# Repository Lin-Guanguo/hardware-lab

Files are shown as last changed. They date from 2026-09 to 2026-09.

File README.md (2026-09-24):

# Hardware Lab

用于个人硬件实验和小装置开发的 Git 仓库。每个装置放在 `projects/` 下，独立维护固件、硬件资料、依赖和构建流程。

## 当前确定方案

以下为各项目当前采用的方向；点击项目名查看最新文件和验证边界，历史方案保留在各项目后续章节。

| 项目 | 用途 | 最近记录的状态 |
| --- | --- | --- |
| [AI Passport](projects/ai-passport/README.md) | 探索紧凑的可编程胸牌、屏幕按键交互与 NFC 链接 | 2026-09-16 确认已下单，等待到货 |
| [Image Oracle](projects/image-oracle/README.md) | 用固定算法将摄像头图像映射为答案，默认拍摄熔岩灯 | 2026-09-19 拼接原型完成并验收；后续探索更多传感器，或焊接、定制 PCB 与 3D 打印的紧凑装置 |
| [Programmable NFC Business Card](projects/nfc-business-card/README.md) | 按键切换身份的薄型 NFC 墨水屏名片 | 2026-09-24 R1 routed in a clean native project: saved/reopened DRC 0, 5.8 mm clear case. Checkpoint `bee8846` saved. Subsequent review removes all nominal 0.2 mm drills, adds USB ground stitching and corrects the C1/C8 review assignment; CE/SCL routing removes two vias and R3/R4 are corrected to 0 ohm. [SWD programmer recovery is selected](projects/nfc-business-card/hardware/r1-usb-swd-recovery.md), with no hidden RESET added. Vendor DFM and real-board tests remain open. [Delivery and checks](projects/nfc-business-card/hardware/pcb-r1-delivery.md). RF and physical fit remain untested. |

## 目录结构

```text
hardware-lab/
├── README.md
├── AGENTS.md
├── .gitignore
├── .gitmodules
├── .agents/
│   └── skills/
│       ├── easyeda-api -> ../../upstreams/easyeda-api-skill   <- 外部 Skill（符号链接）
│       └── pcb-methodology/                                   <- 本仓库自建的方法论总控
├── upstreams/
│   ├── easyeda-api-skill/       <- 嘉立创 EDA 官方 API Skill（可调用）
│   ├── kicad-happy/             <- EMC 规则、公式与监管限值（只读参考）
│   ├── pcb-skill/               <- 同工具链的流程纪律与 MCP 陷阱（只读参考）
│   ├── pcba-design-skills/      <- 证据门禁与产物失效模型（只读参考）
│   └── hw-review/               <- 逐引脚证据式审查、嘉立创 EDA 解析（只读参考）
├── eda/
│   ├── README.md
│   ├── NFC-Card-R1.eprj2
│   └── archive/              <- Historical native projects
├── docs/
│   ├── environment.md      <- 工具链、常驻服务、五分钟自检（新接手先看）
│   ├── pcb-design-rules.md <- DRC 看不见的规则：阈值、一手来源与本板适用性
│   ├── inventory.md
│   └── wiring-diagrams.md
└── projects/
    ├── ai-passport/
    │   └── README.md
    ├── image-oracle/
    │   ├── README.md
    │   ├── firmware/
    │   ├── hardware/
    │   ├── scripts/
    │   ├── wiring-diagrams/
    │   └── docs/
    └── nfc-business-card/
        ├── README.md
        ├── hardware/         <- production/r1/ 制造文件；records/ 校验证据
        ├── enclosure/        <- 模型、STEP/STL、报告；renders/ 是渲染图册
        ├── scripts/          <- 导出器、检查器、布线/线圈规划工具
        ├── docs/             <- 含 progress.md 进度看板
        ├── archive/          <- 历史方案与旧索引
        └── artifacts/        <- 本机产物（全部忽略，只有 README.md 索引入库）
```

目录用途与命名约定见 [AGENTS.md](AGENTS.md)；本机环境、常驻服务与自检见 [环境与常驻服务](docs/environment.md)。所有目录均在首次有实际内容时创建；新项目可以只有 README，不使用占位文件预建目录。根目录 `docs/` 保存跨项目信息，包括器件清单和[接线图制作与归档方法](docs/wiring-diagrams.md)。

根目录 [eda/](eda/README.md) 直接保存嘉立创 EDA 的原始 `.eprj2` 工程，不使用工程文件符号链接；历史工程移到 `eda/archive/`。客户端只需登记一次 `hardware-lab/eda/`。正式工程纳入 Git，所属项目通过文档关联；BOM 等资料仍保存在项目的 `hardware/`，临时导出产物放在 `artifacts/`。

现有接线图见 [Image Oracle 图册](projects/image-oracle/wiring-diagrams/README.md)。后续默认使用带主板外形、完整丝印和模块排针数字序号的接线图；各项目使用相同目录名。

## 设计方法论

DRC 只证明几何没撞上，不证明设计正确。仓库级 [PCB 设计规则索引](docs/pcb-design-rules.md) 列出 DRC 看不见的规则、阈值、一手来源，以及每条规则对 2 层薄板的适用性；流程、约束层级与电气敏感件门禁见自建 skill [pcb-methodology](.agents/skills/pcb-methodology/SKILL.md)。

外部方法论仓库以 Git submodule 引入 `upstreams/`，按需跟随主线。分两类：可直接调用的 Skill 用符号链接进 `.agents/skills/`；只作参考的上游不加链接、不执行其脚本，由自建总控 skill 引用。上游的规则原文不复制进本仓库，引用时标注仓库、文件与规则编号。

## 开始工作

0. 新机器/新接手先看[环境与常驻服务](docs/environment.md)：工具链路径、EDA 桥接（launchd）从零重建、五分钟自检清单与常见故障。
1. 阅读 [AGENTS.md](AGENTS.md) 和目标项目的 README。
2. 分配引脚和确定供电前，先核对实物及对应资料。
3. 改布局、布线、板框或器件位号前，先看 [PCB 设计规则索引](docs/pcb-design-rules.md)，并按敏感件门禁判断要动的器件属于哪一类。
4. 将固件放入项目的 `firmware/`，在项目 README 记录具体工具链、依赖版本和已验证的 shell 命令。
5. 先复现已知可用的例程，再修改应用功能。
6. 记录完成了哪些构建、哪些实机测试，以及仍未确认的事项。

各项目在自己的 README 记录已验证的构建、烧录与测试命令；在本地 Mac 上使用编辑器、shell 工具和 AI 辅助开发。

克隆后使用 `git submodule update --init --recursive` 初始化 `upstreams/` 下的外部仓库。外部 Skill 通过 `.agents/skills/` 中的相对符号链接供 Codex 发现；EDA Skill 的本地依赖与启动方式见 [软件说明](projects/nfc-business-card/docs/software.md)。

## 仓库约定

- 按装置或用途组织项目，每个项目可使用不同的 MCU 和工具链版本。
- 详细状态和下一步放在项目 README，根目录项目表仅作简要导航。
- Git 保存源码、实用的小型素材、可编辑 CAD、依赖锁文件和可复现配置。临时固件导出、采集数据和测量输出放入被忽略的 `artifacts/` 或 `logs/` 目录。
- ESP-IDF 的有意配置保存在 `sdkconfig.defaults` 及所需变体中；生成的 `sdkconfig` 和构建产物不入库。
- 外部上游仓库统一用 Git submodule 放在 `upstreams/`，固定提交并保留上游许可证，在项目文档记录 URL、revision 和使用方式。直接导入的例程仍需记录来源，避免把其嵌套 `.git` 目录复制进仓库。
- 文档默认使用中文；代码、代码注释和专有名词保持英文，具体见 [AGENTS.md](AGENTS.md) 的语言约定。

历史讨论和采购决策继续保存在 [CyberMnema](../CyberMnema/README.md)，通过链接关联。本仓库记录实际工程进展。

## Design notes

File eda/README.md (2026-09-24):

# Native EDA projects

## 当前确定方案

Open [NFC-Card-R1.eprj2](NFC-Card-R1.eprj2) for the NFC card. It contains one PCB and one four-page schematic. [Current files, status and checks](../projects/nfc-business-card/README.md).

Historical projects and database checkpoints are preserved in [archive/nfc-business-card](archive/nfc-business-card/). The E14-named project contains later E-series experiments; its filename does not identify the final R1 source.

Save and close the EDA application before moving or committing `.eprj2` databases. SQLite journals and local automatic backups are ignored. Active projects live directly in this directory; superseded sources live in `archive/`.

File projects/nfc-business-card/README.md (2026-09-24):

# Programmable NFC Business Card

## 当前确定方案

**3.0 mm 内腔研究：**按用户反馈电池最厚处可卡入 3 mm，已完成 [4.6 mm 总厚诊断](enclosure/r1-cavity-3mm-study/README.md)。现有 USB、主控、FPC 座和按键运动存在干涉；局部深腔与平整外表两条路线已有尺寸预算，尚无可打印的 3 mm 内腔方案。电池 3.0 mm 仅用于本次研究，打包版不变。

**最新减薄候选：**[3.6 mm 内腔／5.2 mm 总厚度](enclosure/r1-usb-height-5.2/README.md)已生成。保持电池 3.4 mm 包络及 PCB 安装高度，调整键帽中央压柱后，静止无预压干涉、完整行程几何通过；USB-C 顶部名义余量约 0.11 mm，打印公差和实物回弹仍未验证。5.8 mm 打包版保持不变。

**减薄方向更新：**以 USB-C 安装高度为约束的 [5.4 mm 圆角候选](enclosure/r1-usb-height-5.4/README.md)已生成。键帽底面局部挖空后完整行程几何检查通过，仍保留 3.4 mm 电池包络；键帽局部薄壁、回弹公差与可拆底盖待解决，尚未替换 5.8 mm 打包版。

**CAD 最新接口同步：**[2.54 mm SWD 圆角候选](enclosure/r1-rounded-rear-soft-swd254/README.md)沿用 5.8 mm 厚度，仅更新底盖五孔：Ø1.60 mm、孔口 R0.05，表面最窄连桥 0.84 mm。用户接受通用夹具假设，实物试夹待完成。可拆底盖与按钮减薄仍在设计中。

**外壳工艺评审：**[SLA 打印与 SWD 烧录说明](enclosure/r1-rounded-rear-soft/manufacturing-review.md)已完成，保留五个调试孔。圆角候选仍需解决薄底盖、胶接定位、涂层配合和按键轴向公差；首选向嘉立创 3D 询价，备选 PCBWay。成品板固件尚未开发；首次 bootloader 由用户通过 SWD 写入，不安排工厂代烧。

**最新圆角候选：**[加大圆角的上壳与底盖](enclosure/r1-rounded-rear-soft/README.md)已生成，正面／背面／俯视四角为 R1.2／R0.7／R3.2 mm；外尺寸与 PCB 不变，装入几何检查通过。仍待底盖固定与实物工艺验证。

**外壳方向更新，2026-09-24：**用户选择正面＋侧壁一体、独立底盖、背面内移接缝和外露圆角。[独立 CAD 候选与剖面](enclosure/r1-rounded-rear-study/README.md)保持原外尺寸，PCB 对上壳的装入路径检查通过；底盖固定、胶接工艺和实际装配仍待验证，尚未替换现有 CAD 或制造文件。

**R1 is the current editable engineering prototype.** Three front keys and a front e-paper display; rear NFC coil; right-centred recessed USB-C; two-layer 0.8 mm PCB; transparent printed enclosure, 85.2 × 53.2 × 5.8 mm. The selected battery is nominally 31 × 12 × 3 mm.

**Reviewed prototype checkpoint, 2026-09-24:** the perimeter GND rim is removed, the rear coil has 45° corners and equal offsets to the three exposed edges, and USB CC2 now branches at its protection pad. DRC/connectivity checks pass. **The C1 finding was retracted after identifying C8 as the existing charger input capacitor.** [Review and discussion items](hardware/pcb-r1-review.md). RF tuning, battery measurements and physical assembly remain unverified. The earlier archive checkpoint is `ccf9f92`; the PCB and enclosure study checkpoint is `bee8846`. Subsequent drill/return-path changes are described in the [pre-order review](hardware/r1-preorder.md).

**Latest electrical review:** CE/SCL routing now uses two fewer vias and 4.88 mm less combined trace; saved/reopened DRC and independent copper checks pass. R3/R4 changed to 0 ohm / C21189. [USB update/logging and SWD recovery plan](hardware/r1-usb-swd-recovery.md) records the implemented 2.54 mm SWD row, its synchronized cover access and the user-selected SWD programmer recovery path. The selected generic 5P clip is accepted on nominal dimensions; actual contact is a prototype check. Current manufacturing files are refreshed; the user confirmed on 2026-09-24 that R1 needs no hidden RESET switch or side opening. Next: [production verification handoff](hardware/r1-preorder.md#next-task-handoff).

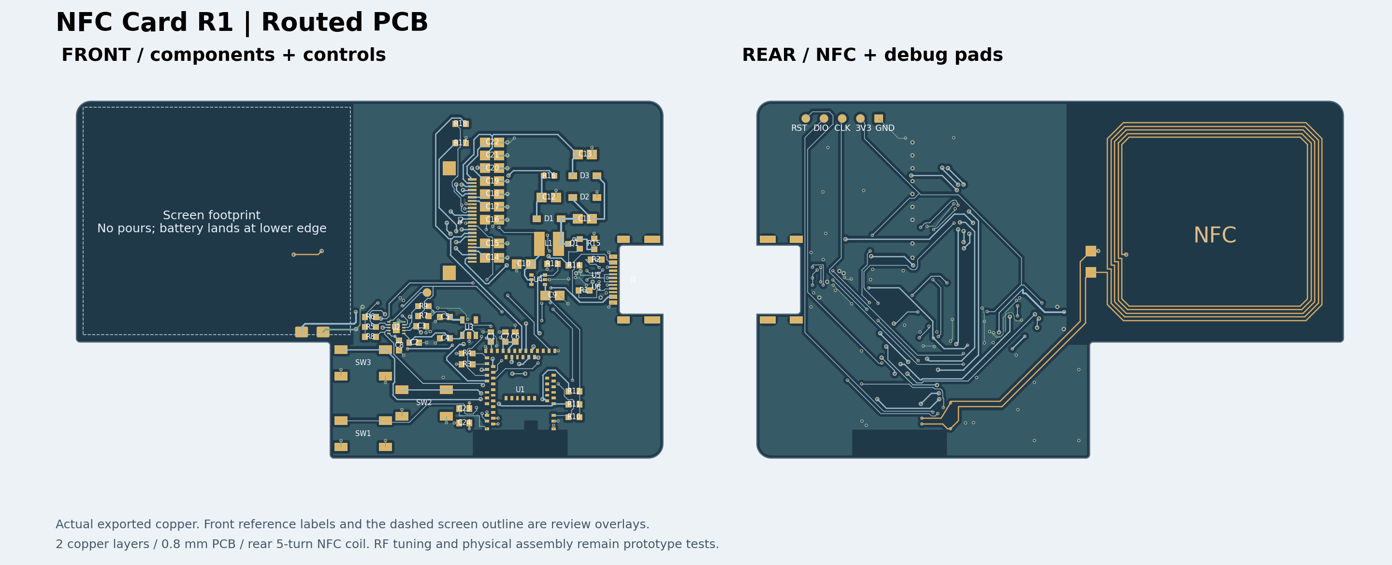
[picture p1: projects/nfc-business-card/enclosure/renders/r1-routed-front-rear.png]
Actual front and rear copper


**Battery follow-up:** battery pads are routed at the user-selected **B position beneath the screen**, with the pack lead exit toward the upper right; both pads were subsequently shifted **1.5 mm right**, to (32.5,18.7)/(35.5,18.7) mm. Three redundant signal vias and one unused stub were removed; reopened DRC and independent copper checks pass. [Regional height/button handoff](enclosure/r1-height-handoff.md) records the accepted 3.4 mm battery and 0.25 mm ferrite assumptions. Thickness/button work is deferred; the active case remains **5.8 mm**. Its old wire/ferrite service bodies need revision for the new pads.

## R1 file index

| Entry | Purpose |
| --- | --- |
| [Native EDA project](../../eda/NFC-Card-R1.eprj2) | Primary editable source: one PCB and one four-page schematic |
| [Manufacturing files](hardware/production/r1/README.md) | Gerber for bare PCB; BOM and CPL for assembly; PDF, STEP and portable EDA backup |
| [Design and verification](hardware/pcb-r1-delivery.md) | Design decisions, checks, limits and reproduction commands |
| [USB/SWD recovery](hardware/r1-usb-swd-recovery.md) | Electrical checks, UF2/CDC plan, clip dimensions and selected SWD recovery |
| [Design inputs](hardware/r1-design.json) | PCB, screen, flex, battery and enclosure dimensions |
| [Clear enclosure](enclosure/README.md) | Editable CAD, assembled STEP and printable tray/lid/three-key meshes |
| [Evidence](hardware/records/r1-validation.json) | Saved DRC, netlist, physical copper, winding and export checks |
| [Scripts](scripts/README.md) | Current export, verification and package commands |
| [Progress](docs/progress.md) | Remaining engineering and physical work |
| [Complete local ZIP](artifacts/NFC-Card-R1-prototype.zip) | Rebuildable handoff containing PCB, CAD and checks; do not upload it as a Gerber ZIP |
| [Historical archive](archive/README.md) | E-series designs, experiments, old indexes and migration map |

## Physical validation still required

- Measure the complete protected battery, sealed edges and wires against the assumed 32.5 × 14 × 3.4 mm envelope.
- Fit the fully inserted display flex, printed enclosure, keys and USB plug; check screen-to-aperture alignment and adhesive retention.
- Bring up the assembled PCB and tune NFC with the final screen and enclosure. C23/C24 = 220 pF is provisional.

[Bench experiments](docs/nfc-bench-test.md) and [firmware](firmware/pn532_probe/) are separate from production-board qualification. No order has been placed.

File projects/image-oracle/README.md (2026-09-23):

# Image Oracle：图像答案之书

用摄像头拍摄图像，通过固定算法从本地答案库中选取并显示答案。默认拍摄熔岩灯，也可以拍摄其他对象。

## 当前确定方案

继续开发的入口是 [oracle_live](firmware/oracle_live/README.md)（[主程序](firmware/oracle_live/oracle_live.ino)）：ESP32-S3-CAM N16R8 + OV3660 + ST7789 + MID 中心键，USB 供电，沿用已验证的[接线图册](wiring-diagrams/README.md)。`camera_serial` 与 `display_serial` 保留作单项测试和恢复基线。

**2026-09-19：相机、屏幕与按键的桌面拼接原型完成，用户实物验收通过。** 当前运行第三个程序 `oracle_live`：左侧实时预览、MID 定格到右侧、下方生成 TRUE/FALSE。可用基线、已完成工作和后续路线见[阶段收尾记录](docs/prototype-milestone.md)。

后续有两条路线：继续拼接传感器探索玩法；或进入焊接、定制 PCB 与 3D 打印，让装置更紧凑。当前仍使用开发板、现成模块和杜邦线，尚未进行定制电路板或外壳制作。

## 实验进展记录

下列条目保留各实验阶段当时的结论；最新状态以上方阶段总结为准。

- 2026-09-16，用户确认此前购买的鹿小班硬件已经全部到货，计划当晚开始实验。具体型号、数量和完好情况仍待验货。
- 2026-09-16，已整理[商家资料与首次实验说明](docs/vendor_resources.md)，下载相机测试源码、套装教程、小智固件及屏幕资料。发现商家部分图纸混用版本，需先对照实物；本地原始下载不入 Git。
- 2026-09-18，已根据用户提供的实物总览与装箱单照片补充[到货清单](../../docs/inventory.md)。纸质清单标注主板为 ESP32-S3-N16R8 CAM、摄像头为 OV3660，额外温湿度模块为 SHT30；实物完整丝印、板卡版本和功能仍待核对。
- 2026-09-18，主板近照可辨认模组标记 ESP32-S3-N16R8；Mac 已识别 USB 串口，并在 115200、8N1 下收到预装程序循环输出的 `50%R`、`50%G`、`50%B`。已验证 USB 识别与串口接收，详见[首次连接记录](docs/first-connection.md)。
- 2026-09-18，用户报告已断电安装摄像头并重新上电；已通过串口确认预装程序为 MicroPython v1.19.1 的 `RGB Demo`，`import camera` 报模块不存在。查询后已软重启恢复灯测试，摄像头安装方向和取帧仍待验证；后续操作同时提供可复现命令。
- 2026-09-19，完整 16 MiB 原固件备份及设备摘要比对通过；[串口相机工程](firmware/camera_serial/README.md)已构建、烧录并通过写入校验，程序约 378 KB。实测识别 OV3660，初始化 8 MB PSRAM，并经原生 USB 取得 320×240 JPEG；修正 Mac 串口控制线引发复位的问题后，正式脚本连续两次拍照成功，已解码查看画面。屏幕、按键和更高分辨率未测试，详见[摄像头启动记录](docs/camera-bringup.md)。
- 2026-09-19，新增[面包板入门与屏幕、按钮准备](docs/breadboard-start.md)。下一步目标为按钮控制屏幕计数；屏幕背面版本和按钮公共端仍待实物确认，尚未分配新 GPIO 或烧录外设测试程序。
- 2026-09-19，用户确认屏幕八针标注，已制定[母对母杜邦线接线表](hardware/display-wiring.md)：SCK40、MOSI41、RST21、DC47、CS42、BL38，保留摄像头和原生 USB 引脚。待核对实际接线与背面版本、添加屏幕测试固件；尚未烧录或验证显示。
- 2026-09-19，用户报告按表接好屏幕；[屏幕测试工程](firmware/display_serial/README.md)构建、原生 USB 自动烧录及写入校验通过，自动重启后收到 `display_serial` 状态回复，待目视确认画面。相机基线保留；两个 Mac 客户端共用避免复位的原生 USB 连接类，提取后相机取帧复测通过。详见[屏幕启动记录](docs/display-bringup.md)。
- 2026-09-19，用户目视确认屏幕测试画面已显示，基本显示验证通过。下一步确认五向按键模块的公共端和针脚，再实现按键控制屏幕计数。
- 2026-09-19，按键近照已确认 `COM UP DWN LFT RHT MID SET RST` 丝印；制定 [COM 共地、MID 接 GPIO14 的方案](hardware/button-wiring.md)。屏幕程序已加入中心键计数和消抖，构建通过，尚未烧录；等待用户完成共地接线。原显示测试程序已另存本地基线。
- 2026-09-19，已将屏幕、中心按键和面包板的四张 HTML 图归档到[接线图册](wiring-diagrams/README.md)，同时保留可编辑源文件。后续沿用主板外形、完整丝印与数字序号的画法；按键实测仍待完成。
- 2026-09-19，用户确认 COM 共地、MID 接 GPIO14 并重新连接 USB；计数版本重新构建、烧录及四段写入校验通过，状态确认 `revision=button-counter`、初始 `count=0`。已发起短按和长按验证，等待用户反馈，详见[按键启动记录](docs/button-bringup.md)。
- 2026-09-19，用户实际按压后报告快速连按漏计数、整屏扫刷。确认旧版绘图阻塞采样约 152 ms，已烧录独立采样、10 ms 消抖及数字局部重绘版本。实测数字绘图约 9.6 ms、采样最大间隔约 1.4 ms；模拟按键测试通过，实物快速连按和长按复测待回报，详见[性能修正记录](docs/button-bringup.md#快速连按漏计数与刷新修正)。
- 2026-09-19，用户确认计数不再丢失，但持续按压后画面延迟。补测复现 USB 日志在无读取端时等待约 2 秒；已烧录不等待 USB 发送的版本，同一压力测试下输出峰值降至 0.212 ms，数字绘图仍约 9.6 ms。构建、烧录校验与无读取端回归测试通过；用户持续连按、停顿后再按，确认“始终跟手，问题解决”。此版本作为按键与屏幕交互基线，详见[USB 阻塞修正](docs/button-bringup.md#连续按压后变慢usb-日志阻塞)。
- 2026-09-19，第三个独立工程 [oracle_live](firmware/oracle_live/README.md)已构建、烧录并正常启动：左侧约 20 FPS 预览，MID 定格到右侧，下方根据照片像素生成 `TRUE`／`FALSE`。固定图像算法、实机预览／定格和 USB 无读取端回归通过；右图已导出 PNG，Mac 重算哈希和答案一致。用户实测确认预览、定格、答案、画面方向和颜色“都正常，效果符合预期”，第三个程序作为后续开发的可用基线。此前按键显示基线已备份，详见[第三个程序整合记录](docs/oracle-bringup.md)。

## 已确定的设计原则

- 图像是答案选择中唯一变化的输入；算法、处理规则和答案库相同时，同一份图像应得到同一个答案。
- 不额外加入随机种子、时间戳或计数器来改变结果。重新抽取意味着重新拍摄，允许答案重复。
- 计划中的核心硬件是摄像头、屏幕和五向按键模块；其他已购模块用于实验，不作为必需功能。
- 先用 USB 供电和面包板验证，功能原型跑通并测量尺寸后，再确定正式接线和外壳。
- 熔岩灯保留原装市电供电并独立放置；本项目仅开发弱电电子部分。
- AI Passport 当前公开配置没有摄像头，作为独立项目探索。

## 目录用途

- `firmware/`：完整固件工程和可复现的构建配置。
- `hardware/`：已核对的 BOM、引脚分配、接线和未来可能设计的 PCB。
- `tests/`：Mac 消抖、图像算法测试，以及实机预览、定格和 USB 无读取端回归测试。
- `wiring-diagrams/`：[交互式接线图册](wiring-diagrams/README.md)，包含独立 HTML 和 `sources/` 图源。
- `docs/`：器件资料、实验、测量结果和设计决策。
- `downloads/`：本地商家原始资料、预编译固件和解压副本，被 Git 忽略；下载来源和校验值保存在 `docs/vendor_downloads.json`。

## 后续两条路线

| 路线 | 目标 | 启动时先做什么 |
| --- | --- | --- |
| 更多传感器实验 | 尝试温湿度、光照、触摸、编码器等输入与屏幕交互 | 选一个已购模块，确认型号、电压及引脚，再做独立读取实验 |
| 紧凑装置与产品化探索 | 用焊接、定制 PCB 和 3D 打印减少杜邦线、固定模块 | 明确保留功能，测量实物尺寸与接口位置，再设计布局和连接方式 |

两条路线可以交替推进，具体步骤与尚未验证的范围见[阶段收尾记录](docs/prototype-milestone.md)。三个固件工程和可恢复基线继续保留；后续实验按实际内容创建目录，不预建 PCB 或外壳占位工程。

## 常用命令

以下安装和构建命令已在 macOS ARM64 验证；烧录与实物测试进展见[摄像头启动记录](docs/camera-bringup.md)。

```sh
bash projects/image-oracle/scripts/setup.sh
bash projects/image-oracle/scripts/build.sh
```

第三个程序使用以下命令构建、查询和定格：

```sh
bash projects/image-oracle/scripts/build-oracle.sh
uv run --offline projects/image-oracle/scripts/oracle.py --port /dev/cu.usbmodem1101 STATUS
uv run --offline projects/image-oracle/scripts/oracle.py --port /dev/cu.usbmodem1101 SNAP
uv run --offline projects/image-oracle/scripts/oracle.py --port /dev/cu.usbmodem1101 EXPORT \
  --output projects/image-oracle/artifacts/photos/oracle-frozen.png
```

`SNAP` 等同于按 MID；`EXPORT` 保存已经定格的右图并重新校验哈希和答案。构建不会自动烧录，烧录、恢复和代码阅读入口见[第三个程序说明](firmware/oracle_live/README.md)。

切回第二个屏幕／按键程序后，使用以下命令控制显示：

```sh
bash projects/image-oracle/scripts/build-display.sh
uv run projects/image-oracle/scripts/display.py --port /dev/cu.usbmodem1101 STATUS
uv run projects/image-oracle/scripts/display.py --port /dev/cu.usbmodem1101 COUNTER
uv run projects/image-oracle/scripts/display.py --port /dev/cu.usbmodem1101 RED
uv run projects/image-oracle/scripts/display.py --port /dev/cu.usbmodem1101 TEST
```

完整步骤及 `COUNTER`、`GREEN`、`BLUE`、`LIGHT_OFF` 等命令见[屏幕工程说明](firmware/display_serial/README.md)。

切回相机固件后，保持原生 USB 连接，不按 BOOT，从仓库根目录拍照：

```sh
uv run projects/image-oracle/scripts/capture.py \
  --port /dev/cu.usbmodem1101 \
  --output projects/image-oracle/artifacts/photos/my-photo.jpg
```

重新插入后用 `ls /dev/cu.*` 核对端口；每次拍照换一个新文件名。照片和原固件备份均不入 Git。

串口连接、MicroPython REPL 与 `screen` 操作见[首次连接记录](docs/first-connection.md)。

## 参考资料

- [拼接原型阶段收尾与后续路线](docs/prototype-milestone.md)
- [第三个程序：相机、屏幕与按键整合实测](docs/oracle-bringup.md)
- [知识笔记：任务、局部重绘与非阻塞日志](docs/responsive-input-display.md)
- [知识笔记：两个 USB-C 接口、UART 与固件通信](docs/usb-uart-notes.md)
- [商家资料、下载位置与首次实验说明](docs/vendor_resources.md)
- [下载来源及 SHA-256 清单](docs/vendor_downloads.json)
- [原始讨论、采购记录与启动计划](../../../CyberMnema/timeline/2026/09/W38/熔岩灯交互装置.20260914.md)
- [共享器件清单](../../docs/inventory.md)

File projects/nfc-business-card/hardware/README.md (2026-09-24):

# R1 hardware

## 当前确定方案

Use the [R1 native project](../../../eda/NFC-Card-R1.eprj2) and [current project index](../README.md). The antenna/CC2 and battery-pad changes were checkpointed in `bee8846`. The [pre-order follow-up](r1-preorder.md) removes nominal 0.2 mm drills, improves USB stitching and corrects the C1/C8 service assignment. The CE/SCL reroute removes two vias; R3/R4 are corrected to 0 ohm. [USB/SWD recovery](r1-usb-swd-recovery.md) records the implemented 2.54 mm SWD row, physical clip trial fit, pending RESET decision and firmware tests. Vendor DFM and prototype tests remain open.

| Files | Purpose |
| --- | --- |
| [production/r1/](production/r1/README.md) | Frozen vendor exports and portable project |
| [pcb-r1-delivery.md](pcb-r1-delivery.md) | Current engineering report and checks |
| [r1-design.json](r1-design.json) | Coordinated dimensional inputs |
| [records/r1-validation.json](records/r1-validation.json) | Consolidated verification; other `r1-*` files hold inputs and detailed evidence |
| [candidate-bom.md](candidate-bom.md), [component-options.md](component-options.md) | Component selection rationale; the exported BOM is authoritative for R1 |
| [battery-purchase-candidates.json](battery-purchase-candidates.json) | Purchased battery candidates and measurement uncertainty |
| [Historical hardware](../archive/pre-r1/hardware/) | E-series snapshots, placement studies and old manufacturing gates |

The native project is editable design data. Gerber describes board artwork and drilling; it does not contain the complete editable design, firmware or enclosure.

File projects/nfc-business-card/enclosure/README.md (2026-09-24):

# R1 transparent enclosure

## 当前确定方案

最新研究：[3.0 mm 内腔／4.6 mm 总厚诊断](r1-cavity-3mm-study/README.md)。电池按用户报告的 3.0 mm 输入，现有 USB、主控、FPC 座和按键仍干涉。已记录局部深腔与平整外表的尺寸预算，仅保存诊断 CAD，未导出打印件或替换下述候选。

继续减薄：[内腔 3.6 mm／外厚 5.2 mm 候选](r1-usb-height-5.2/README.md)已生成，三键静止与完整行程检查通过；USB 顶部间隙约 0.11 mm，按键凹位的按压竖向间隙约 0.08 mm。此为紧配合研究，未替换打包版，仍需处理打印公差和可拆底盖。

减薄研究已恢复：[USB 高度约束下的 5.4 mm 候选](r1-usb-height-5.4/README.md)采用键帽底面局部凹位，三键完整运动包络无干涉，USB／3.4 mm 电池上方名义间隙约 0.31／0.30 mm。局部键帽厚 0.6 mm 与原有 0.05 mm 轴向间隙尚未经过打印和回弹验证；可拆固定仍未实现，打包版保持 5.8 mm。

打包用 [r1-clear-5.8](r1-clear-5.8/README.md)也已同步 2.54 mm 五孔：Ø1.60、外孔口 R0.05，CAD、托盘与装配导出、冻结输入和 `r1-mechanical-check.json` 已刷新。仅更新孔位，不代表打包外形已切换为圆角背盖方案。

最新 CAD 基线：[2.54 mm SWD 圆角候选](r1-rounded-rear-soft-swd254/README.md)在 5.8 mm 圆角版上同步五孔坐标，采用 Ø1.60、外孔口 R0.05，最窄表面连桥 0.84 mm。上壳及其余几何不变；通用探针模块的实物试夹待完成。用户希望方便拆卸，下一步优先研究局部支柱、插舌和小螺钉固定；减薄至 5.6 mm 仅是讨论中的目标，尚未改模型。

恢复接口协调：[隐藏 RESET 与 2.54 mm 探针候选评估](r1-recovery-study.md)已给出右侧按压轴和开关区域；保守包络与装入检查通过。SWD 夹具尺寸、底盖小孔和工具导向尚待确定，未修改 PCB 或发布新外壳制造版。

最新 [制造工艺评审](r1-rounded-rear-soft/manufacturing-review.md)记录 SLA 透明材料平台、薄板与配合风险和 SWD 烧录准备；五个孔按用户确认保留。几何检查通过不代表打印与装配已验收。

同日圆角加强：[更圆润的候选](r1-rounded-rear-soft/README.md)将正面／背面／俯视四角分别增至 R1.2／R0.7／R3.2 mm，外尺寸保持不变；几何与装入检查通过。背面五孔是 SWD 调试探针通道，本次保留。后续仍需验证底盖定位、胶接与打印公差。

2026-09-24 外观方向更新：采用**正面＋侧壁一体、背面嵌入独立底盖，外露边缘圆角**。[圆角与背面接缝候选](r1-rounded-rear-study/README.md)保持 85.2 × 53.2 × 5.8 mm；接缝距外轮廓约 1.33 mm，PCB 对上壳的直线装入检查通过。竖向胶接与底盖定位尚未验证，未替换以下现有模型，也未批准下单。下一步确认固定结构与打印公差，并验证真实排线和装配步骤。

The [current R1](../README.md) uses two transparent printed halves and three printed keys. Overall size is **85.2 × 53.2 × 5.8 mm**; panels are 0.8 mm, perimeter walls 1.2 mm. The display aperture is open and there are no internal crossbeams. Nominal CAD fit passes; printing, flex insertion, battery fit and adhesive closure still need physical validation.

The [thickness/key study](../hardware/r1-packaging-study.md) compares 5.8–5.2 mm using the switch specification's upper travel bound. The existing generator's 0.30 mm key check covers only the earlier nominal-motion assumption. Thickness/button manufacturing is deferred to a separate discussion; no thinner CAD release has been selected or generated. The [height handoff](r1-height-handoff.md) records regional stacks, cap motion and the new battery B solder/ferrite arrangement.

| File | Purpose |
| --- | --- |
| [Assembly FCStd](r1-clear-5.8/e20-clear-assembly.FCStd) | Editable FreeCAD document |
| [Assembly STEP](r1-clear-5.8/e20-clear-assembly.step) | Complete mechanical assembly for review; not the file to print as one solid |
| [Tray STL](r1-clear-5.8/e20-clear-tray.stl) | Print the lower enclosure, dimensions in mm |
| [Lid STL](r1-clear-5.8/e20-clear-lid.stl) | Print the upper enclosure |
| [Keys STL](r1-clear-5.8/e20-clear-keys.stl) | Print all three separate keys |
| [Tray STEP](r1-clear-5.8/e20-clear-tray.step), [lid STEP](r1-clear-5.8/e20-clear-lid.step) | Solid part exports |
| [Geometry report](r1-clear-5.8/e20-clear-report.json) | Nominal intersections and clearances |
| [Assembly preview](r1-clear-5.8/e20-clear-assembled-iso.png), [open preview](r1-clear-5.8/e20-clear-open-iso.png) | Visual review |
| [Actual copper](renders/r1-routed-front-rear.png) | PCB front/rear review |
| [Generator](e20-clear-shell.py), [preview macro](e20-clear-preview.FCMacro) | Rebuild from `hardware/r1-design.json`; filenames retain their E20 origin |

[Mechanical check](../hardware/records/r1-mechanical-check.json): rear debug access is aligned, supports remain on the board, and print meshes are closed. These checks do not certify resin tolerances or strength. [Historical models](../archive/pre-r1/enclosure/) are preserved separately.

The antenna/CC2/battery-pad revision retains component placement and shell geometry. [Mechanical reuse check](../hardware/records/r1-cad-reuse-check.json) compares the two STEP exports; the original CAD build inputs remain preserved inside `r1-clear-5.8/design-inputs.json`. Current electrical dimensions are in `hardware/r1-design.json`. **The frozen CAD still contains the old long wire corridor and 0.20 mm ferrite body; it does not validate the new B-pad wiring or accepted 0.25 mm sheet.** Update the local service bodies and sheet notch in the next mechanical iteration.

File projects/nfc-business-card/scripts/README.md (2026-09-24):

# R1 scripts

## 当前确定方案

Use these scripts with the [R1 files](../README.md). Historical E-series scripts are [archived](../archive/pre-r1/scripts/) and must not be run against the live R1 project.

| Script | Purpose |
| --- | --- |
| `eda-exec-wait.mjs`, `eda-export-r1-snapshot.js` | Bridge execution and live geometry export, guarded by both project and PCB UUID |
| `check-r1-copper.py`, `pour_geometry.py` | Physical connectivity, detached pours, single-layer vias and the precise battery B exception within the screen exclusion |
| `check-r1-nfc.py` | Cut-winding topology proof and deliberate bypass negative control |
| `check-netlist-consistency.py` | Schematic/PCB pin-by-pin agreement |
| `check-e20-outline.py` | Generic closed Gerber outline and USB plated-slot verification |
| `check-r1-delivery.py` | Manufacturing files, positions, drill hits, saved evidence and native-source checks |
| `check-r1-usb-swd.py` | USB/charger/key/SWD pin assignments and R3/R4 procurement consistency; records unverified firmware and fixture status |
| `check-r1-case.py` | FreeCAD solid, print mesh and debug-hole checks |
| `render-r1-copper.py` | Render actual saved copper |
| `study-r1-packaging.py` | Read-only CAD/PCB study of thickness, full key motion and battery landing options |
| `compare-gerber-exports.py` | Compare manufacturing geometry across different native export presets |
| `review-r1-layout.py` | Named service-pin decoupling, antenna spacing, copper fragments, TVS topology and discussion findings |
| `plan-r1-chamfered-coil.py` | Generate constant-normal-pitch 45° coil geometry |
| `export-r1-manufacturing.py` | Export the guarded native PCB into a fresh output directory |
| `package-r1.py` | Rebuild the complete local handoff ZIP from tracked source, exports, CAD and evidence |
| `check-proposed-route.py`, `pcb-maze-router.py` | Candidate-route geometry and routing helpers; plans require independent verification |

[Verification commands](../hardware/pcb-r1-delivery.md#reproduce-checks). Install Python dependencies from [requirements.txt](requirements.txt). FreeCAD checks use the [documented runtime](../docs/software.md).

Rebuild the local handoff from the repository root:

```sh
python3 projects/nfc-business-card/scripts/package-r1.py
```

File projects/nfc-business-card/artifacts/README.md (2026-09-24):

# Local generated artifacts

## 当前确定方案

Tracked sources and vendor files are indexed in the [R1 project README](../README.md). Everything here except this index is local generated data.

- `NFC-Card-R1-prototype.zip`: complete handoff; rebuild with `python3 projects/nfc-business-card/scripts/package-r1.py`.
- `r1-delivery/`: expanded handoff contents; rebuilt with the ZIP.
- `r1-routing/`: snapshots, route experiments and native export scratch files.
- `archive/pre-r1/`: preserved E-series generated outputs.
- `archive/`: other preserved local checkpoints.

Use `hardware/production/r1/NFC-Card-R1-gerber.zip` for bare PCB fabrication. Do not upload the complete prototype ZIP as Gerber data.

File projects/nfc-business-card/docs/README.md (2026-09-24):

# NFC card documentation

## 当前确定方案

The [R1 index](../README.md) defines current geometry and release status. Older dimensions or layout proposals in background notes are historical context.

- [Progress](progress.md): current gates and required physical work.
- [Delivery](../hardware/pcb-r1-delivery.md): evidence, limits and check commands.
- [Software](software.md): EDA bridge and FreeCAD runtime.
- [Screen evaluation](gdeh0154e01-evaluation.md): display datasheet and interface evidence.
- [Architecture](architecture.md): firmware and interaction concepts.
- [NFC bench test](nfc-bench-test.md): separate development-board experiments.
- [Sources](sources.md) and [download manifest](download_manifest.json): source provenance.
- [USB and prototyping](usb-and-prototyping.md), [PCBA workflow](pcba-ai-workflow.md): manufacturing background.
- [Archive](../archive/README.md): superseded plans and previous progress notes.

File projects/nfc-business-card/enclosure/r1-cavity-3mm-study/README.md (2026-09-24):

# 3.0 mm 内腔研究

## 当前确定方案

2026-09-24：按用户反馈“电池最厚处可以卡入 3 mm”，将 **3.0 mm 电池厚度**作为本次研究输入。它是用户观察，不是全寿命最大尺寸；不依靠挤压电池闭合外壳。目标为主体内腔 3.0 mm，前后各 0.8 mm 时总厚 **4.6 mm**，保留圆角及背面内移接缝方向。

**当前器件、安装层和键帽不能直接装进均匀的 3.0 mm 内腔。** 已生成诊断 CAD，静态和按键运动均发现干涉，因此未导出打印 STEP/STL。下一步需要选择局部加厚，或联动修改支承、壁厚和按键结构；本研究没有修改 PCB 或替换 5.8 mm 打包版。

## 高度预算

基准是底盖内表面；沿用 0.32 mm PET/胶安装层、0.80 mm PCB。下列值尚未叠加打印误差、器件公差和装配余量。模型名义值与最大值分别标明。

| 区域 | 当前需要的高度 | 对 3.0 mm 内腔的缺口 | 依据 |
| --- | --- | --- | --- |
| 电池 | 3.00 + 0.10 胶 = 3.10 mm | 0.10 mm | 用户报告的厚度；胶层沿用假设 |
| USB-C | 3.490 mm | 0.490 mm | 当前安装层及库模型 |
| 主控 | 0.32 + 0.80 + 2.20 = 3.32 mm | 0.32 mm | 沿用器件最大高度 |
| 屏幕 FPC 座 | 3.130 mm | 0.130 mm | 当前安装层及库模型；不含排线折弯 |
| 当前凹底键帽 | 约 3.52 mm 才达到按压零竖向间隙 | 0.52 mm | 0.45 mm 规格行程上界加约 0.05 mm 接触间隙 |

USB4500 官方标注 **3.16 mm profile、0.80 mm offset、Mid Mount**，与当前库模型约 3.17 mm 接近。中沉安装已经利用了 PCB 厚度；不能再把 0.8 mm 从连接器整体高度里扣一次。即使完全取消 0.32 mm 安装层，现有连接器仍超过 3.0 mm。[GCT 产品页](https://gct.co/connector/usb4500)

屏幕区域另有问题：按最大屏厚 1.0 mm 计算，屏幕后方与 0.25 mm 铁氧体的间隔仍有约 **0.47 mm**，但与假设高出 PCB 1.0 mm 的焊点/线头重叠约 **0.18 mm**。这是尺寸链计算，未建立真实焊点和走线实体，不能当作实际碰撞测量。

## 两条结构路线

### 主体 3.0 mm，局部加高

保留当前 PCB 安装位置和 0.8 mm 面板，在高器件处增加内腔；外部可考虑连续圆滑过渡。以下统一增加 **0.15 mm 试算余量**，它不是供应商认可的打印公差，也不代表所有按键配合方向已有足够间隙。

| 局部区域 | 内腔估算 | 对应外厚估算 |
| --- | --- | --- |
| USB-C | 3.64 mm | 5.24 mm |
| 主控 | 3.47 mm | 5.07 mm |
| FPC 座 | 3.28 mm | 4.88 mm |
| 当前键帽运动区 | 3.67 mm | 5.27 mm |

电池区按 3.0 电池 + 0.1 胶 + 0.1 试算间隙，需要 3.2 mm。可以研究底盖内侧局部沉槽 0.2 mm，但会使该处底盖从 0.8 减至 0.6 mm，局部内腔也实际变成 3.2 mm，强度与电池长期尺寸仍需验证。

这条路线只是主体薄，最大厚度仍约 **5.3 mm**。表中是包络预算，尚未生成无干涉的局部凸起实体，也未检查过渡曲面、局部薄壁及装入路径。不能宣称它比 5.2 mm 平整候选的最大厚度更小。

### 外表平整，目标总厚 4.6 mm

保持目前底盖及 PCB 高度，只挖上壳内侧，USB 上方壁厚仅剩 **4.6 − 4.290 = 0.310 mm**；再留 0.15 mm 顶部间隙，只剩 **0.160 mm**。这不能作为现有透明树脂方案已可制造的依据。

更有意义的研究方向是同时下沉 PCB、在底盖内侧做局部凹位，并重新设计键帽或更换低矮开关。不过 0.32 mm 安装层是实体 PET 和胶，不能直接当作空隙删除；下沉还会改变 USB 开口、SWD 探针深度和底部绝缘。若进一步更换 USB、主控封装或板厚，则需要 PCB 任务重新核对电气、板框及装配基准。目前没有确认满足严格 3.0 mm 整体内腔的替代 USB 型号。

因此本次结论是：**严格均匀 3.0 mm 内腔不兼容当前配置；主体 3.0 mm 加局部深腔有明确尺寸预算；平整 4.6 mm 外壳仍需结构与器件联动，尚未证明可制造。**

## 检查与文件

- [原始计算报告](report.json)：静态上壳与 USB、主控、FPC 座、电池相交；三个键帽与固定开关体在运动中相交，第二键还触及 R8。报告中的 `retained_rear_brep_equal: false` 是序列化字串比较未通过，未据此声称底盖几何已验证不变。
- [按键尺寸剖面](key-section.png)：已视觉检查，展示 3.8、3.6、3.0 mm 内腔。蓝色实心为完整检查行程位置，虚线为静止位置；省略圆角、端子和移动触点，仅用于解释尺寸关系。
- 诊断模型位于 `../../artifacts/usb-height-3mm-cavity-v1/rear-cover-study.FCStd`，原始源文件哈希未变，诊断模型保存重开后各零件有效。实体有效不代表装配无干涉。
- [建模脚本](../study-r1-usb-height.py)与[剖面脚本](../render-r1-key-section.py)可复现；按键移动/固定区域仍沿用半径 1.4 mm 分界假设，未经实物验证。
- 行程依据：[ALPS SKQGAB 规格](https://tech.alpsalpine.com/cms.media/SKQGAB_KQG_719_EN_cc4e10226e.pdf#page=3)。0.45 mm 是规格上界检查输入，不是建议强压到该行程。

从仓库根目录运行，输出目录必须不存在：

```sh
NFC_USB_HEIGHT_MM=4.6 NFC_USB_BATTERY_MM=3.0 \
NFC_USB_HEIGHT_OUT="$PWD/projects/nfc-business-card/artifacts/usb-height-3mm-cavity-v2" \
PYTHONHOME=/Applications/FreeCAD.app/Contents/Resources \
PYTHONPATH=/Applications/FreeCAD.app/Contents/Resources/lib \
/Applications/FreeCAD.app/Contents/Resources/bin/freecadcmd \
projects/nfc-business-card/enclosure/study-r1-usb-height.py

NFC_USB_HEIGHT_OUT="$PWD/projects/nfc-business-card/artifacts/usb-height-3mm-cavity-v2" \
python3 projects/nfc-business-card/enclosure/render-r1-key-section.py
```

本次 v1 已完成上述 FreeCAD 检查与独立剖面绘制，报告状态为 `INTERFERENCES_FOUND_DIAGNOSTIC_ONLY_NO_PRINT_EXPORTS`。没有进行打印、强度、回弹或实物装配验证。

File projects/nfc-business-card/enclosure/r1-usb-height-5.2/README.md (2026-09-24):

# R1：3.6 mm 内腔／5.2 mm 总厚度候选

## 当前确定方案

2026-09-24：用户要求继续压缩 3.8 mm 内腔，本轮将研究推进到 **内腔 3.6 mm、总厚度 5.2 mm**，上下大面各 0.8 mm。候选已生成并通过名义几何检查，供后续试装设计使用；尚未替换 5.8 mm 打包文件，也未成为可直接下单版本。

3.8 mm 是上一轮分配了约 0.3 mm 顶部间隙的目标，不是硬性结构下限。继续减薄会减少装配余量。PCB、USB-C、支撑高度、外轮廓圆角及 SWD 五孔不变；仍保留 **3.4 mm 电池包络＋0.1 mm 胶层**，没有以压电池来获得空间。

## 厚度比较

以下均为名义尺寸，尚未扣除加工与装配偏差：

| 内腔／总厚度 | USB-C 顶部间隙 | 3.4 mm 电池＋胶层间隙 | 按到底时凹位顶面至开关外壳的竖向间隙 |
| --- | ---: | ---: | ---: |
| 3.8／5.4 mm | 0.31 mm | 0.30 mm | 0.28 mm |
| 3.7／5.3 mm | 0.21 mm | 0.20 mm | 0.18 mm |
| **3.6／5.2 mm** | **0.11 mm** | **0.10 mm** | **0.08 mm** |

三组均使用 1.0 mm 外缘、0.4 mm 底面凹位、0.6 mm 局部顶面的键帽，三个键帽的完整运动包络均无干涉。5.3 mm 在本轮作为几何对比，独立导出的是 5.2 mm 候选。若完整电池实测为 3.2 mm，5.2 mm 方案的电池顶部间隙为 0.30 mm，但 USB-C 的 0.11 mm 不变。

内腔若进一步到 3.5 mm，沿当前堆叠计算，USB-C 仅剩约 0.01 mm，3.4 mm 电池加胶层为零间隙；不能将这个零余量算例作为本工艺的可靠装配尺寸。

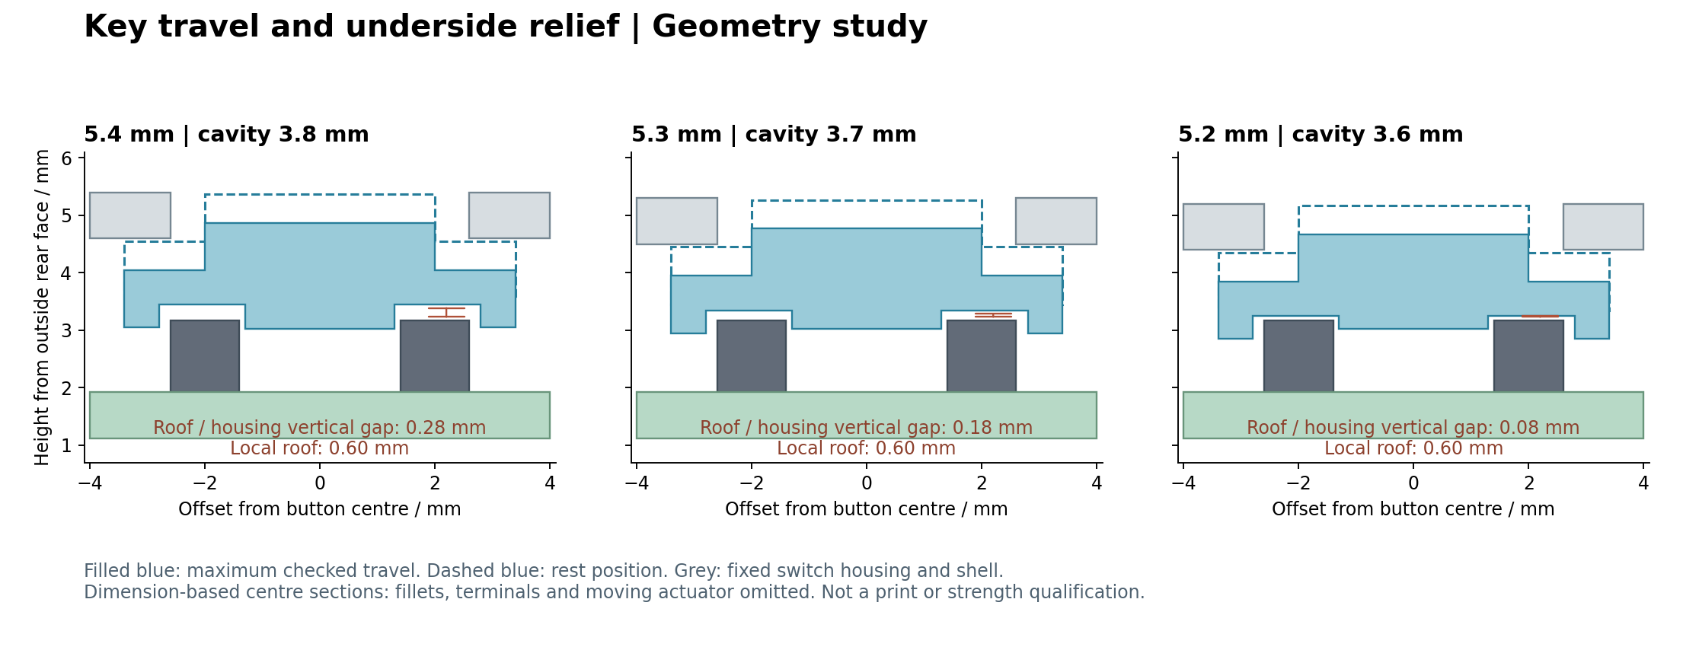
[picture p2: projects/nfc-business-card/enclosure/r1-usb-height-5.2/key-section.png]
三组内腔的按键剖面


## 键帽与验证

沿用[5.4 mm 研究](../r1-usb-height-5.4/README.md)的底凹位结构，但更低的外缘不能把中央压柱也带下去。本轮将中央压柱底端保持在原 **Z=3.52 mm**，原始接触间隙约 0.05 mm；新增静止键帽对**整个开关**的检查，确认没有名义预压干涉。按压扫掠继续使用约 0.50 mm 总位移，并沿用已注明的活动压头排除假设。

[检查报告](report.json)记录：三个键帽有效且各为单实体，中央压柱实际底面匹配原基准；静止时与完整开关无体积干涉；完整位移包络与上壳、PCB、固定开关和其余元件无干涉；所选上壳与已建模装配体无静态干涉。FCStd 保存重开通过，五件 STEP 有效且单实体、五份 STL 封闭；组合 STEP 有五个实体。原 5.8 mm 来源的 SHA-256 未变，SWD 底盖 BREP 不变。

剩余约束：0.6 mm 局部键帽强度、0.05 mm 静止轴向间隙和约 0.08 mm 按压竖向间隙都未通过树脂打印与实际回弹验证；USB 约 0.11 mm 余量没有覆盖完整公差链。真实电池包、排线、焊点和导线仍需试装；本次未加入可拆底盖固定结构。不得把几何通过解释成工艺或整机可靠性验收。

## 文件与复现

- [完整候选 FCStd](rear-cover-study.FCStd)、[五件打印零件 STEP](print-parts.step)。
- 独立壳体 `upper.step/.stl`、`rear.step/.stl`；独立键帽 `key-1.step/.stl` 至 `key-3.step/.stl`。
- [正面预览](front-iso.png)、[背面预览](rear-iso.png)。

代码经 `python3 -m py_compile`，完成结果以 `report.json` 为准，不仅检查 FreeCAD 退出码。生成必须使用新目录：

```sh
NFC_USB_HEIGHT_MM=5.2 \
NFC_USB_HEIGHT_OUT="$PWD/projects/nfc-business-card/artifacts/usb-height-5p2-rebuild" \
PYTHONHOME=/Applications/FreeCAD.app/Contents/Resources \
PYTHONPATH=/Applications/FreeCAD.app/Contents/Resources/lib \
/Applications/FreeCAD.app/Contents/Resources/bin/freecadcmd \
  projects/nfc-business-card/enclosure/study-r1-usb-height.py

NFC_USB_HEIGHT_OUT="$PWD/projects/nfc-business-card/artifacts/usb-height-5p2-rebuild" \
python3 projects/nfc-business-card/enclosure/render-r1-key-section.py
```

不指定 `NFC_USB_HEIGHT_MM` 时仍生成原 5.4 mm 研究。GUI 预览复用 `preview-r1-rear-cover.FCMacro`，指定本候选目录和独立配置，不保存源文件。

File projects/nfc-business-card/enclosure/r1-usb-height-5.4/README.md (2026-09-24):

# R1：以 USB-C 高度为基准的 5.4 mm 候选

## 当前确定方案

2026-09-24：按用户要求恢复减薄设计，以现有 USB-C 的安装高度为约束，完成 **5.4 mm 总厚度／3.8 mm 内腔**候选。上下大面仍各 0.8 mm；圆角、外轮廓、2.54 mm SWD 孔和 PCB 安装基准保留，前壳与屏幕向下移 0.4 mm，重新设计三个键帽底面。**当前是按键与厚度几何候选，尚未作为可打印交付版；打包版仍为 5.8 mm。**

电池继续保留完整包络 **3.4 mm＋0.1 mm 胶层**；3.2 mm 仅作为用户提出、待实测的对比输入，没有将挤压软包作为装配方式。即使电池实测降至 3.2 mm，USB-C 仍占约 3.49 mm 内腔高度，整体下限不会随电池再降低同样幅度。软包尺寸与膨胀需要留意，[VARTA 电池类型说明](https://www.varta-ag.com/fileadmin/varta_storage/downloads/Webinare_PDF/Batteries_101.pdf)也列出 pouch/polymer 的 swelling 问题；该资料不能替代本电池的最大尺寸或寿命余量。

## 厚度结果

| 项目 | 5.4 mm 候选 |
| --- | ---: |
| USB-C 顶部名义间隙 | 0.310 mm |
| 3.4 mm 电池＋0.1 mm 胶层顶部间隙 | 0.300 mm |
| 若完整电池实测为 3.2 mm，顶部间隙 | 0.500 mm，仅对比 |
| 主控最大高度至壳内面 | 0.480 mm |
| 最大屏幕背面至 0.25 mm 铁氧体 | 1.270 mm，堆叠计算 |
| 最大屏幕背面至假设 1.0 mm 焊点／导线 | 0.620 mm，堆叠计算 |

USB 的 3.49 mm 来自原库模型加 0.32 mm 支撑；它是本布局的名义高度，不是供应商最大公差。3.49＋两面各 0.8＝约 5.09 mm 只是零间隙算术下限。取约 0.3 mm 名义余量得到 5.4 mm 研究目标；这个余量尚未扣除打印误差、翘曲、胶厚和元件公差。

## 键帽改动

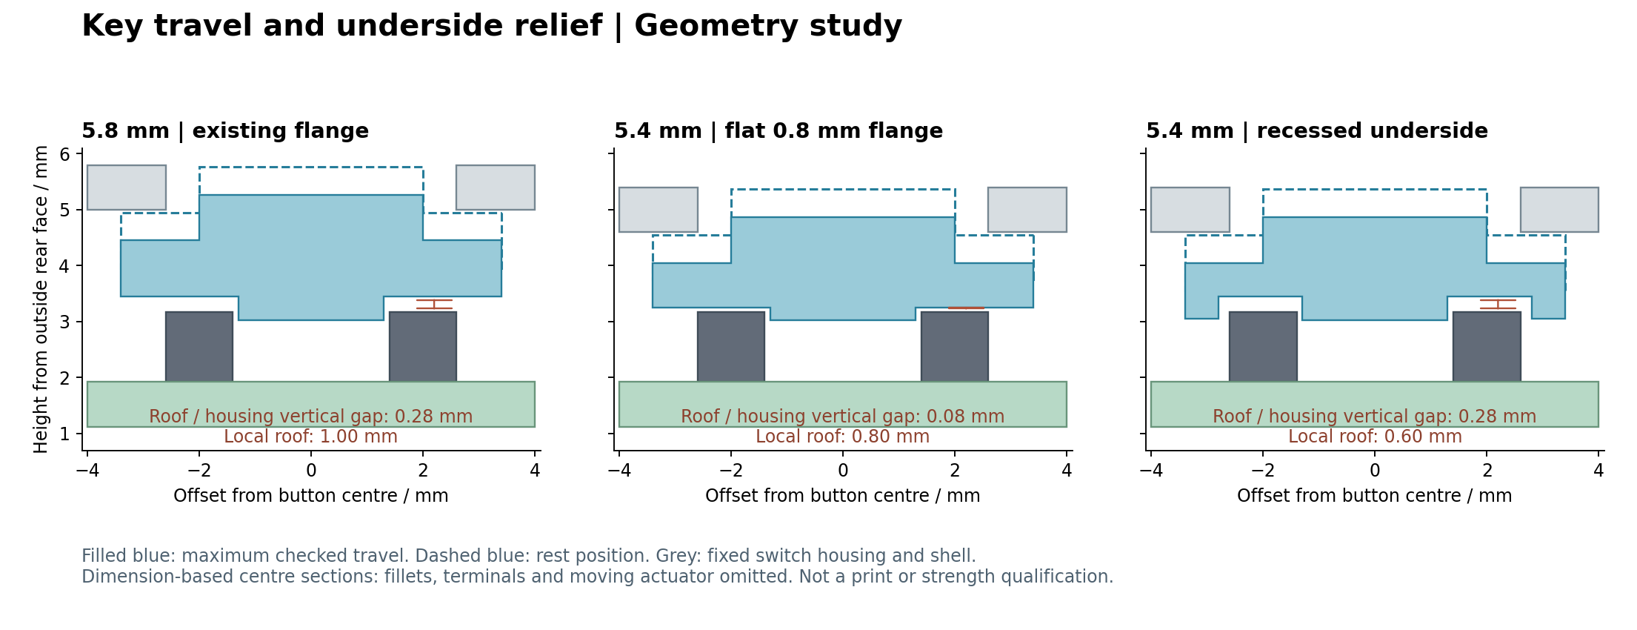
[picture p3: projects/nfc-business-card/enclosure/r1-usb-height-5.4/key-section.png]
按压剖面对比


剖面按尺寸绘制，省略圆角、引脚和活动压头；蓝色实线为检查的最大位移，虚线为静止位置。它不是透明树脂外观预测。

原键帽用一整片 1.0 mm 厚的圆形限位边。简单减薄外壳，会让这片边在按下时撞开关固定外壳。本候选保留 1.0 mm 外缘，在开关外壳上方挖 **5.6 × 5.6 mm、深 0.4 mm**的底面凹位，并保留中央 Ø2.6 mm 压柱；可见按钮仍为 Ø4.0 mm、边缘 R0.2。三个开关及 PCB 均未移动。

按 [ALPS SKQGABE010 规格 §7.2](https://tech.alpsalpine.com/cms.media/SKQGAB_KQG_719_EN_cc4e10226e.pdf#page=3)的行程上限 0.45 mm，加原有约 0.05 mm 接触间隙，检查约 0.50 mm 总位移。该行程是间隙检查边界，不是要求强行把实物开关压下 0.45 mm。

| 外厚／键帽结构 | 凹位顶面或平底至开关固定外壳的竖向间隙 | 几何结果 |
| --- | ---: | --- |
| 5.8／原 1.0 mm 平底 | 0.28 mm | 通过 |
| 5.6／0.8 mm 平底 | 0.28 mm | 通过 |
| 5.4／0.8 mm 平底 | 0.08 mm | 名义不碰撞，余量小 |
| 5.2／0.8 mm 平底 | −0.12 mm | 每键约 0.535 mm³ 干涉 |
| **5.4／1.0 mm 外缘＋0.4 mm 底凹位** | **0.28 mm** | 三键完整位移包络通过 |

这里的 0.28 mm 是**竖向间隙**，不是键帽所有表面的最短距离。完整键帽最短距离约 0.10 mm，来自沿用的中央压柱与活动区排除边界；固定开关检查沿用 Ø2.8 mm 活动区假设，仍需实物核对。

代价必须一起考虑：挖空后局部顶面厚度为 **0.6 mm**，外缘留下较窄的裙边；其打印、刚度和寿命未验证。原静止轴向间隙 **0.05 mm**也尚未解决公差、静止预压和回弹问题。因此“完整行程不撞”不等于按钮已可以可靠量产。下一步应先做该键帽与壳孔的局部配合样件，验证最薄处、偏压和回弹；若材料不接受 0.6 mm 局部结构，需要调整键帽工艺或回退厚度，不能直接压电池补偿。

## 文件与验证

- [完整候选 FCStd](rear-cover-study.FCStd)、[五个打印零件 STEP](print-parts.step)。
- 独立壳体：`upper.step/.stl`、`rear.step/.stl`。
- 独立键帽：`key-1.step/.stl`、`key-2.step/.stl`、`key-3.step/.stl`。
- [检查报告](report.json)、[正面预览](front-iso.png)、[背面预览](rear-iso.png)。这些导出供几何评审和后续样件准备，未批准直接下单。

FreeCAD 检查通过：用水平下表面连续扫掠构造完整键帽运动包络，三个键帽与上壳、PCB、固定开关和其他已建模元件均无干涉；降低后的上壳与已建模装配体无静态干涉；SWD 底盖保持原 BREP；FCStd 保存重开有效，五个独立零件各为单实体、五份 STL 封闭，组合 STEP 为五个有效实体。代码经 `python3 -m py_compile`，索引改动经 `git diff --check`。正背面 GUI 渲染与按键剖面已目视检查。

边界：没有加入可拆底盖固定结构或 RESET 孔；没有重建真实 FPC、导线、铁氧体和焊点实体；屏幕最大尺寸／铁氧体／焊点间隙仅为堆叠计算；没有验证包含松散线材和工具的装配过程，没有做实体按键力／回弹／寿命测试。原 5.8 mm 文件和 PCB 均保留。

## 复现

输出必须是新目录：

```sh
NFC_USB_HEIGHT_OUT="$PWD/projects/nfc-business-card/artifacts/usb-height-rebuild" \
PYTHONHOME=/Applications/FreeCAD.app/Contents/Resources \
PYTHONPATH=/Applications/FreeCAD.app/Contents/Resources/lib \
/Applications/FreeCAD.app/Contents/Resources/bin/freecadcmd \
  projects/nfc-business-card/enclosure/study-r1-usb-height.py

NFC_USB_HEIGHT_OUT="$PWD/projects/nfc-business-card/artifacts/usb-height-rebuild" \
python3 projects/nfc-business-card/enclosure/render-r1-key-section.py
```

读取完成报告；FreeCAD 退出码本身不足以证明成功。GUI 预览复用 `preview-r1-rear-cover.FCMacro`，指定上述模型目录和独立 GUI 配置。

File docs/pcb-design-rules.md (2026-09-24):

---
description: 仓库级 PCB 设计规则索引：DRC 看不见的规则、阈值、一手来源与板级适用性
last_updated: 2026-09-23
---

# PCB 设计规则索引

这份文档回答一个问题：**哪些规则是 DRC 抓不到、但会让板子出问题的？**

它列出规则、阈值、一手来源，以及每条规则对**本仓库的板子类别**（2 层、0.8 mm、USB 全速、射频在模块内、线性充电 + 升压变换）是否成立。它不复制上游规则原文，只做索引与适用性判定——完整规则定义读 `upstreams/` 里的原文。判定的原因比判定本身重要：写明"不适用"和写明"适用"同样有价值，否则会花力气去做不相关的事。

约束层级（硬约束与可交易目标的划分）与变更门禁见 [PCB 方法论 skill](../.agents/skills/pcb-methodology/SKILL.md)。

## 为什么需要这份索引

EasyEDA 的原生 DRC 只检查几何间距与连接：它是必要条件，不是充分条件。这一点本项目已经反复踩到并写进记录——[整板评审](../projects/nfc-business-card/archive/pre-r1/hardware/board-design-review.md) 写明"不会以 DRC 剩余数量作为改层依据"，[E16 记录](../projects/nfc-business-card/archive/pre-r1/hardware/pcb-e16-usb-right-mid.md) 写明"这只是几何与额定电流的估算：压降、去耦回路、升压瞬态和地回流阻抗仍需在实物上测"。

已发生的实例（本索引存在的理由）：`C3` 是 BQ25186 的 BAT 引脚电容（2.2 µF），在 E16 的 USB 排版中被归入"USB 小元件"搬到 (71.90, 20.60)，离 U2 的 BAT 焊盘 24.49 mm（E15 时在 (49.53, 22.86)，约 4.7 mm）。原生 DRC 0 间距、逐引脚网表 0 差异、连通性 0 断网、制造包 `ok=true` **四项全过**——因为它是一处布局意图错误，没有任何一项检查会问"这颗电容该在哪"。DC-001 一次就把它标出来了，随后按本索引的流程搬回 U2 旁 (49.60, 21.60)，实测 2.04 mm，规则从 CRITICAL 变为通过（见 [E16 记录](../projects/nfc-business-card/archive/pre-r1/hardware/pcb-e16-usb-right-mid.md)）。

## 覆盖状态图例

| 标记 | 含义 |
| --- | --- |
| ✅ 自动 | 已由本项目检查器实现，可复跑 |
| 🔒 阻塞 | 需要覆铜几何；快照导出尚未采集铜箔铺铜对象 |
| ✋ 人工 | 需要器件资料或人工判断，无法从几何推出 |
| ⬜ 待实现 | 判据所需几何已具备，但检查器还没写 |
| — 不适用 | 规则前提在本板类别下不成立 |

检查器：[check-e16-emc.py](../projects/nfc-business-card/archive/pre-r1/scripts/check-e16-emc.py)（E16 专用；板级无关的通用化等第二块板再做，不预先抽象）。

```bash
cd projects/nfc-business-card
python3 scripts/check-e16-emc.py --json /tmp/e16-emc.json

# 校验"本表声称自动覆盖"与"检查器真的实现"是否一致
python3 tools/check-rule-coverage.py
```

两条关于这张表可信度的说明：

- **覆盖声明由机器校验。** 标 ✅ 却没有对应实现的条目，属于过度声明——它会让板子看起来被审过而实际没有。这条守卫存在是因为真的发生过一次：`BE-001`、`BE-003`、`IO-001`、`DP-002` 曾标为自动而无人计算，`DP-002` 已因此降为 ✋ 人工。
- **器件角色是声明的，不是从几何推出来的。** 快照只能给出封装，给不出功能，所以检查器里的 `EXTERNAL_CONNECTORS`、`PROTECTION_REFS`、`SWITCHING_INDUCTORS`、`SENSITIVE_REFS` 四张表是人工声明并在每条结论中一起打印。换板或换料号必须同步改这四张表，否则检查会静默答非所问。

## 铜箔与回流路径

| 规则 | 阈值 | 本板 | 说明 |
| --- | --- | --- | --- |
| [GP-001](../upstreams/kicad-happy/skills/emc/references/pcb-emc-rules.md) 信号跨越铺铜缺口 | 任一信号网络的参考面覆盖率 <95% | ✅ 自动（**仅供参考，非门禁**） | 已实现，但**结论暂不可信**：铺铜会沿每条走线留出间距，走线中心线永远落在铺铜为它挖出的间隙里，所以必须按"到最近参考铜箔的距离"判，而**走廊宽度是我定的**。取 0.5 mm 时 48 个信号网络里 45 个低于 95%——对一个地覆铜占 40% / 51% 的板子，这个结论不可信。症结是这个指标无法区分"真实平面开槽"与"平面被同层其它走线的间距穿孔"。标为参考项，**校准到已知有问题的板子之前不作为发现**。本板确实存在的两处开槽是 NFC 禁布区（设计如此）与 EPD 电容列 (x 44–58, y 25–45) |
| GP-003 地平面碎裂 | 地网络有 >3 个不连通岛 | ✅ 自动 | 实测顶层 **29** 个覆铜区域、底层 **14** 个（`analyze-e16-pour.py`）。区域数远超"3 个岛"的阈值，但**这 29 块是否都连到 GND 网络尚未逐一验证**——原生 DRC 报 0 未布通，而本项目的 `ground_reach` 尚不可信（见[E16 记录](../projects/nfc-business-card/archive/pre-r1/hardware/pcb-e16-usb-right-mid.md)）|
| GP-004 地填充率 | 地覆铜填充率 <60% | ✅ 自动 | 实测顶层 **40.0%**、底层 **50.7%**，均低于 60% 阈值。**适用性**：该阈值按专用地平面写；2 层板双面密集走线下 40–50% 属预期，其含义是回流通道被压缩，正是 `GP-001` 要查的，不宜单独当缺陷 |
| GP-005 多个地域 | 检测到多个地网络 | 🔒 | 本板单一 GND，预期通过；仍需覆铜确认无孤岛 |
| [RP-001](../upstreams/kicad-happy/skills/emc/references/pcb-emc-rules.md) 换层缺缝合孔 | 信号过孔周围 max(2 × 介质厚, 1.0 mm) 内无地缝合孔 | ✅ 自动 | 本板 2 层、介质 0.8 mm，阈值 1.6 mm。实测 120 个信号过孔中 93 个超过；其中 **22 个带快速边沿**。USB 对的 8 个换层孔离最近地过孔 **4.27–6.83 mm**。**适用性**：2 层板没有平面对，回流在两面地覆铜之间跳，全速 USB 的 15 ns 边沿下这条绕行只有 λ/1000 量级 |
| [VS-001](../upstreams/kicad-happy/skills/emc/references/pcb-emc-rules.md) 缝合孔间距 | 平均间距 > 2 × λ/20 | ✅ 自动 | 本板 48 个地过孔，平均最近邻 2.92 mm，阈值 6.0 mm（2×λ/20 @2.4 GHz）通过。最大最近邻 8.56 mm 出现在 (69.70, 2.60)，位于天线禁布区边缘，属有意留空 |
| BE-001 信号靠近板边 | 外层走线距板边 < 1 × 介质厚 | ✅ 自动 | 阈值 0.8 mm。实测 **798 段里 7 段**低于阈值，且**全部是直流或按键驱动的慢速网络**（`USB_CC1/CC2/VBUS` 在 USB 缺口内 0.504 mm，`KEY_PREV_N` 沿电池开口边缘 0.400 mm）——0 段带快速边沿。注意与槽边铜距 0.20 mm 是两条不同规则 |
| BE-002 地覆铜环 | 板周长 <90% 在 2 mm 内有地覆铜 | ✅ 自动 | 实测覆铜距板边西/南/东/北 = 0.50/0.15/0.50/0.50 mm（顶层）与 0.50 mm（底层），全部在 2 mm 内，通过 |
| BE-003 连接器区缝合孔 | 连接器 10 mm 半径内孔距 > 2 × λ/20 | ✅ 自动 | 实测 **J1 的 10 mm 内只有 1 个地过孔**（且在 9.08 mm 处，实际属 U1 区域），5 mm 内 0 个。**适用性**：阈值按连接器最高频信号的拐点频率算，USB 全速 15 ns 边沿对应约 23 MHz，2×λ/20 ≈ 620 mm，远大于板子——这条对全速连接器**不构成约束**，数值本身不是缺陷 |
| EE-001 板腔谐振 | 谐振频率落在辐射源 ±20% | 🔒 | 2 层 0.8 mm 无平面腔；本板实际意义有限，列为信息项 |

## 去耦与电源

| 规则 | 阈值 | 本板 | 说明 |
| --- | --- | --- | --- |
| [DC-001](../upstreams/kicad-happy/skills/emc/references/pcb-emc-rules.md) 去耦距离 | 5 mm 警告 / 8 mm 严重（**焊盘到焊盘**） | ✅ 自动 | 必须量焊盘到焊盘。用元件中心到中心量会给 U1 报出假 CRITICAL（9.23 mm），实际 C5/C6/C7 → U1 的 VDD_3V3 焊盘是 4.40 / 3.75 / 4.12 mm，通过。**C3 由此暴露：21.90 mm**，随后修复至 2.04 mm |
| DC-002 缺去耦 | IC 10 mm 内无电容 | ✅ 自动 | 本板全部 IC 都在 10 mm 内（中心到中心，粗筛） |
| DC-003 电容远离过孔 | 电容焊盘到电源/地过孔 > 3 mm | ✅ 自动 | 供电类电容全部 ≤2.7 mm。电源变换类电容（C3 5.68、C11 4.24、C13 7.50、C19 4.12 mm）超阈值——它们不是高频去耦，但连接电感对开关回路的 EMI 同样重要 |
| SW-002 开关节点铜面积 | >25 mm² 中等 / >100 mm² 高 | ✅ 自动 | `EPD_SW` 铜箔 1.86 mm²，通过 |
| SW-003 输入电容热回路 | 三角面积（输入电容 → IC → 电感）>25 mm² | ✅ 自动 | U4→L1→C9 为 0.85 mm²，通过 |
| SW-001 谐波落入测试频段 | 开关谐波落在 30–960 MHz | ✋ 人工 | 需要 U4 升压的开关频率与边沿时间；数据手册可得 |
| PD-001..004 PDN 阻抗 | 反谐振峰超过 Z_target = V × 5% / (0.5 × I_transient) | ⬜ | 覆铜平面对已就位（顶层/底层各一块 GND），还缺逐电容的网络与 ESL/ESR 映射。2 层板无平面对，此项收益有限 |
| EF-001/002 EMI 滤波器截止 | f_sw / f_cutoff < 5 | — | 本板无输入 EMI 滤波器设计 |
| TH-001 MLCC 直流偏压降容 | 有效容值 < 标称 50% | ✋ 人工 | 需要所选 MLCC 的直流偏压曲线；0603 X5R/X7R 在 3.3–4.2 V 下值得核 |

## 连接器与 ESD

| 规则 | 阈值 | 本板 | 说明 |
| --- | --- | --- | --- |
| [ES-001](../upstreams/kicad-happy/skills/emc/references/pcb-emc-rules.md) TVS 距连接器 | >15 mm 中等（建议移入 10 mm） | ✅ 自动 | U5 → J1 4.97 mm，U6 → J1 5.05 mm，通过 |
| ES-002 TVS 地过孔 | 3 mm 内 <2 个地缝合孔（无则高危） | ✅ 自动 | U5/U6 的 GND 焊盘 3 mm 内 **0 个**地过孔。同一处缺陷被三条独立规则指向：`ES-002`（本行）、`RP-001`（USB 对换层孔 4.27–6.83 mm）、`BE-003`（J1 10 mm 内仅 1 个）。**能否判定取决于该焊盘是靠铺铜还是靠细线接地——覆铜几何不在快照里，所以当前只能按厂商指引补缝合孔，无法测量修好了多少** |
| IO-001 连接器无滤波/保护 | 25 mm 内无铁氧体/共模扼流圈/ESD 器件 | ✅ 自动 | 实测 J1（USB-C）最近的保护器件是 U5（USB ESD 阵列），**4.97 mm**，通过。本板无铁氧体与共模扼流圈，因此这条确认的是保护覆盖而非滤波覆盖 |
| IO-002 连接器地引脚比 | 地引脚 < max(2, 信号引脚/4) | ✋ 人工 | J1 是 USB-C，地引脚充足；需按实际连接的引脚数核 |
| SH-001 连接器开口槽谐振 | 槽谐振落在辐射源 ±20% | — | 本板无金属屏蔽壳，不构成谐振腔 |

## 差分与高速

| 规则 | 阈值 | 本板 | 说明 |
| --- | --- | --- | --- |
| [DP-001](../upstreams/kicad-happy/skills/emc/references/pcb-emc-rules.md) 对间偏斜 | 协议相关；**USB 全速 10000 ps**，高速 25 ps | ✅ 自动 | DP/DM 差 2.15 mm（11.8 ps）与 3.80 mm（20.8 ps）。对全速预算余量约 480 倍。**"USB 没做等长"这个担忧由此量化排除** |
| DP-002 偏斜致共模辐射 | 估算发射超过限值 | ✋ 人工 | **未实现，故不标自动。** 上游公式需要电缆长度与共模电流路径的假设（`I_CM = V_CM / Z_cable`、电缆长度），本板没有这些输入；全速 15 ns 边沿下 DP-001 的偏斜又只有 11.8 / 20.8 ps，不构成驱动因素 |
| DP-003 差分对换参考面 | 差分网络上有任何换层 | ✅ 自动 | 本板 USB 对共 10 个过孔。规则判"高危"是按高速对写的；全速下换层引入的是阻抗不连续而非回流断裂，影响有限 |
| DP-004 差分对走外层 | 内层可用时 >50% 走外层 | — | 本板无内层可用 |
| CK-001/002/003 时钟走线 | 外层时钟、>100 mm、距连接器 <10 mm | — | 本板无独立时钟网络；射频与主控时钟都在模块内部 |

## 叠层与串扰

| 规则 | 阈值 | 本板 | 说明 |
| --- | --- | --- | --- |
| [XT-001](../upstreams/kicad-happy/skills/emc/references/pcb-emc-rules.md) 3H 串扰 | 平行耦合 ≥5 mm 且间距 < 3 × 介质厚 | ✅ 自动 | 2 层 0.8 mm 下 3H = **2.4 mm**，比本板绝大多数走线间距都宽，因此命中 54 对网络。**阈值需按攻击者类别筛**：真正带快速边沿的只有 USB 对与 `EPD_SW`/`EPD_PUMP`。命中的高重叠对（NRESET↔SWDCLK、SWDCLK↔SWDIO、KEY_*）都是仅在烧录/按键时翻转的慢速信号 |
| SU-001 相邻信号层 | 两个信号层相邻且中间无参考面 | — | 2 层板无内层 |
| SU-002 信号层离参考面 >0.3 mm | 信号层距最近参考面 >0.3 mm | — | 规则前提是有参考平面。**但这条恰恰指出 2 层板的固有弱点**：本板所有走线距对侧参考面都是 0.8 mm，环路面积天然比多层板大 |
| SU-003 电源/地平面间距 | 电源地介质 >0.2 mm | — | 无平面对 |
| TH-002 铁氧体靠近开关稳压器 | 10 mm 内有开关稳压器 | — | 本板无铁氧体 |

## 上游没有成文阈值但已实现的一条

| 规则 | 阈值 | 本板 | 说明 |
| --- | --- | --- | --- |
| ML-001 未屏蔽开关电感靠近敏感电路 | 15 mm | ✅ 自动 | **这条在 `emc_rules.py` 与上游 README 里有，但 `pcb-emc-rules.md` 没有独立条目**。本板唯一开关电感 L1 距 U1 模块 43.14 mm，通过。注意：U1 模块内含晶振、2.4 GHz 射频与 NFC 前端，是这条规则最该保护的对象 |

## 已知的上游不一致

- 上游 README 与 `emc-precompliance.md` 声称 **44 条规则 / 18 类**；`pcb-emc-rules.md` 实际只写了 **42 条 `###` 条目 / 17 个分类**，且 `ML-001` 有实现无条目。
- 结论：**规则清单以 `emc_rules.py` 的实现 + `pcb-emc-rules.md` 的阈值为准，README 的计数不可当权威**。引用上游时同时标出规则 ID 与文件名。

## 尚未挂一手来源的本仓库规则

以下规则目前是经验值，属于"AI 会自信复述但未必成立"那一类，**在按它做设计决定前必须补来源或标为待验证假设**：

| 规则 | 现状 | 该补什么 |
| --- | --- | --- |
| NFC 线圈外缘离大块金属 ≥5 mm | [E16 记录](../projects/nfc-business-card/archive/pre-r1/hardware/pcb-e16-usb-right-mid.md) 自己标注为"经验余量" | NXP/Nordic 天线设计指南的原文依据，或标为待实测 |
| 0.15 mm 线宽 ≈ 600 mA @10 °C 温升 | 已标注依据为 IPC-2221 外层 1 oz | 保留；IPC-2221 是正式标准，属可追溯 |

## 署名与许可

规则 ID、阈值、公式与一手来源索引自 [aklofas/kicad-happy](../upstreams/kicad-happy)（MIT），规则原文见 `upstreams/kicad-happy/skills/emc/references/pcb-emc-rules.md`，公式库见 `upstreams/kicad-happy/skills/emc/scripts/emc_formulas.py`。本页的板级适用性判定、覆盖状态与本仓库自有规则由本项目撰写。外部仓库以 Git submodule 固定，`upstreams/` 内的上游文件不修改。

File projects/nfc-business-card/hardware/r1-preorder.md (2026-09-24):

# R1 pre-order review — 2026-09-24

## Saved state and current result

Checkpoint **`bee8846`** preserves the PCB, delivery files and separate enclosure studies. The changes below follow that checkpoint and are included in the current repository checkpoint at the user's request. No order or supplier message has been sent.

| Work item | Result |
| --- | --- |
| Six nominal 0.20 mm vias | Five USB vias enlarged to 0.25 mm drill / 0.45 mm land; battery via enlarged to 0.30 / 0.55 mm |
| Battery connection | Via moves from X40.20 to X40.05 mm, with three local trace adjustments; B+/B− positions stay (32.5,18.7)/(35.5,18.7) mm |
| Thin annular rings | Former CC2 0.30/0.20 mm vias now have nominal 0.10 mm radial copper, previously 0.05 mm |
| USB ground return | Two connected GND stitching vias added; worst nearest-ground-via distance 3.66 → 2.62 mm |
| Charger input capacitor | Earlier C1 finding corrected: C1 serves U1.32, while C8 already serves U2.10 |
| Charger-control routing | CE/SCL rerouted together: two fewer vias, 4.88 mm shorter combined path; other signal routes unchanged |
| USB series resistors | R3/R4 changed from 27 ohm to 0 ohm / C21189; native schematic, PCB and BOM synchronized |
| SWD clip adaptation | Five rear pads and labels moved to 2.54 mm pitch; square GND/pin 1, no added vias; cover access synchronized under accepted nominal fixture assumptions |
| Native and independent checks | Saved/reopened DRC 0; no split nets, dead ends, orphan copper or single-layer vias; NFC cut proof passes |
| Manufacturing consistency | 58 BOM/CPL references, 238 matching schematic pins, 153 vias, four plated slots; unchanged outline/components |
| Mechanical reuse | All 238 component STEP solids retain identical volume, area and bounds; this does not validate the pending wire/ferrite service volumes |

Evidence: [change plan and before/after metrics](records/r1-preorder-plan.json), [layout review](pcb-r1-review.md), [delivery checks](records/r1-validation.json), [C8 evidence](records/r1-input-capacitor-check.json).

## Why small holes existed, and why keep 0.25 mm now

The September 22 USB fanout experiments used a **“Multiple Layers Board” DRC preset** to permit smaller lands/holes around the connector's 0.5 mm pitch pads. The electrical board remained two-layer. A preset name is not a requirement to manufacture four layers. See the [archived USB experiment](../archive/pre-r1/hardware/pcb-e16-usb-right-mid.md), especially the “Multilayer-rule fanout experiment” and subsequent fanout records.

The current geometry supports removing every 0.20 mm drill without moving components or changing the USB protection topology. A nominal 0.25 mm hole with 0.45 mm copper land provides 0.10 mm radial copper. There are now **97 nominal 0.25 mm and 56 nominal 0.30 mm vias**. Larger holes are possible in open areas; enlarging all lands in place is not possible in the existing dense fanout. Eliminating the 0.25 mm tier would require broader routing changes and a new verification cycle. That is justified if the actual supplier quote or DFM reveals a material constraint or cost, rather than by the old preset alone.

The current Gerber drill tools are **0.248920, 0.250000, 0.299999 and 0.305001 mm**, plus **0.599999 mm** for the four mounting slots. The near-nominal differences come from legacy imperial dimensions and native export precision. The quote must use the actual Gerber, not a hand-rounded drill file.

## Current JLC domestic capability

Checked the [official JLC capability table](https://www.jlc.com/portal/vtechnology.html) on 2026-09-24:

- Two-layer boards support 0.15 mm drills, explicitly described as unconventional and expensive; the recommended minimum hole is 0.20 mm or larger.
- Via land diameter must exceed hole diameter by at least 0.10 mm; the recommendation is 0.15 mm or more. Current new 0.45/0.25 and 0.55/0.30 sizes exceed that recommendation.
- Unconventional two-layer holes require ink/resin filling. The page does not settle which quote tier our actual near-0.25 mm tools will use or what it costs.
- Minimum plated slot width/length for two layers is 0.5/1.0 mm; length should be at least twice width. R1 has two 0.6 × 1.8 mm and two 0.6 × 1.4 mm plated slots, including rounded ends.
- Published 1 oz two-layer track/space capability is 0.10/0.10 mm. Retain 1 oz; thicker copper has different limits.

Therefore **0.20 mm was not intrinsically unmanufacturable and did not require four layers**. Removing it improves the two smallest annular rings and simplifies the minimum-hole requirement. Neither the public capability page nor DRC is a quote or a supplier acceptance of this custom USB footprint.

## Fabrication selection and DFM brief

Use the [current Gerber](production/r1/NFC-Card-R1-gerber.zip), **89,074 bytes**, SHA-256 `bc26ce13373705df8b42c041d1c44eba96881d41cc013b50b29b341e18924c5b`.

| Field | R1 selection / constraint |
| --- | --- |
| Board | Two-layer FR-4, nominal 81.8 × 49.8 mm, routed L-shaped profile |
| Thickness / copper | 0.8 mm / 1 oz outer copper |
| Finish | ENIG is the proposed flat finish for this prototype; confirm the actual quote |
| Mask | Both faces, including the NFC winding; no exposed antenna, gold fingers or edge plating |
| Vias | Plated through; no blind/buried vias or HDI; confirm required filling/tenting and surcharge from actual drills |
| Connector cutout | Retain the exported contour and four plated slots; do not replace the board outline with an assembly/mechanical drawing |
| Clearance | Smallest pad-to-board-edge geometry is approximately 0.299 mm; signal-pad-to-USB-cutout clearance is approximately 0.301 mm, not the obsolete 0.2007 mm figure |
| Panel / rails | Ask the assembler to prepare/approve tooling rails for the L-shaped 0.8 mm board and protruding mid-mount USB body; keep rails removable and outside the final contour |

Before payment, obtain confirmation for the actual minimum drill tier, hole treatment, four plated slots and USB cutout. These are manufacturing acceptance questions, not a request to invent a special PCB process. The remaining 0.25 mm tier may still affect price.

## 嘉立创 PCB 网页试算（2026-09-24）

按 5 片、双层 FR-4、81.8 × 49.8 mm、0.8 mm 板厚、1 oz、绿色阻焊、沉金和 0.25 mm 最小孔径在[嘉立创 PCB 下单页](https://www.jlc.com/newOrder/#/pcb/pcbPlaceOrder)试算。选择 0.25 mm 后，页面提示该孔径属于高难度工艺，并自动选择过孔塞油及四线低阻全测。价格明细如下；这是未上传 Gerber 的裸板参数试算，不是已审核报价，也不含 SMT、器件和钢网。

| 网页价格项 | 5 片试算 | 说明 |
| --- | ---: | --- |
| 最小孔径/外径 | ¥102.04 | 对应 0.25 mm 档；Gerber DFM 识别最小孔径 0.25 mm |
| 喷镀费 | ¥102.85 | 所选沉金；DFM 估算沉金面积 6.53%，未达到页面提示的 30% 大面积加价线 |
| 阻焊覆盖费 | ¥100.20 | 页面因 0.25 mm 孔径自动选择过孔塞油；Gerber 的实际过孔属性仍须审核 |
| 四线低阻全测费 | ¥101.63 | 0.25 mm 档自动选中，页面禁用“无要求”；正式订单仍须确认 |
| 特价 | ¥30.00 | 裸板基础试算项 |
| 品质赔付费 | ¥10.00 | 页面默认选择的可选保障服务，不属于 PCB 工艺 |

网页合计 **¥446.72**，显示所选快递包邮。固定上述其他参数，仅将孔径改为免费 0.30 mm 档、将塞油与全测复位为普通选项，合计 **¥142.85**；重新选择 0.25 mm 档，页面再次自动选中塞油和全测，合计回到 ¥446.72。两档差 **¥303.87**，恰好是孔径 ¥102.04、塞油 ¥100.20、全测 ¥101.63 三项之和。若另外改用免费表面处理并取消默认品质赔付服务，普通档可低至这次的 ¥30 基础项；这不表示现有 R1 Gerber 可按普通档生产。实际运费和价格以订单审核为准。0.8 mm 板厚、1 oz、绿色阻焊没有在这次价格明细中单列加价。四个镀铜槽、L 形外形、SMT 工艺边和元器件仍待供应商确认，不能据此试算认定免费或可生产。DFM 页面使用了默认有铅喷锡显示，而本试算选择沉金；最终表面处理要以正式制造参数为准。

## Assembly preparation

Bare-board fabrication needs the Gerber ZIP. SMT assembly additionally needs the [BOM](production/r1/NFC-Card-R1-bom.csv), [CPL](production/r1/NFC-Card-R1-cpl.csv) and [assembly PDF](production/r1/NFC-Card-R1-assembly.pdf). A supplier number in the BOM is not proof of current stock or automatic assembly support.

| Part | Assembly / purchasing confirmation |
| --- | --- |
| U1 MDBT50Q-P1MV2, C5119772 | Confirm exact module suffix and antenna variant; check the module orientation and availability |
| U2 BQ25186DLHR, C44639442 | Confirm WSON-10 exposed-pad stencil and placement; do not substitute a charger by similar name |
| J1 USB4500-03-0-A, C5354966 | Custom adapted mid-mount footprint: review signal lands, tabs, slots and placement overlay; native CPL midpoint is 0.15 mm left of its reference origin |
| J2 FPC-05FB-24PH20, C2856831 | Verify contact side, latch direction and insertion orientation against the screen flex |
| C8 CL10A475KO8NNNC, C19666 | Samsung marks it NRND; check stock. Suggested successor is CL10A475KO8NQN#, but a substitution requires value, bias, package and height confirmation |
| SW1–SW3 SKQGABE010, C115351 | Three electrical switches are in the BOM; printed keycaps are separate enclosure parts |
| Battery, display, ferrite | Fit and connect after PCBA reflow; they are not populated by the 58-component CPL |

No live assembler BOM matching, stock reservation, stencil approval, panel approval or binding quotation has been completed. The bare-board parameter estimate above is provisional. Those remaining checks depend on the actual selected service and its review screen. The intentional R3/R4 substitution is documented in the [USB/SWD review](r1-usb-swd-recovery.md); no supplier-driven substitutions are approved.

## Remaining work and ownership

1. **Recovery design settled, 2026-09-24:** the user accepts recovery through an SWD programmer. Retain the five existing SWD/NRESET pads; do not add a hidden RESET switch or side opening. The current export implements 2.54 mm SWD pitch for the selected generic 5P clip, with synchronized cover access; nominal assumptions were accepted and trial fitting is a prototype check. [USB/SWD contract](r1-usb-swd-recovery.md).
2. **Supplier / order preview:** drill tier and filling, USB slot/cutout acceptance, component matches/stock, rotations and tooling rails. The package and questions are ready; no supplier acceptance is claimed.
3. **Prototype electronics:** current-limited power-up, rails, charging, display, SWD and USB full-speed operation. Four USB transitions still exceed the contextual 1.6 mm ground-via guideline; this is a review cue, not a proven USB fault. Firmware must be built and validated for this nRF52840 board.
4. **Assembled NFC:** tune the provisional C23/C24 values with the actual screen, 0.25 mm ferrite, battery and shell. Geometry checks do not establish resonance or read range.
5. **Separate enclosure work:** the active 5.8 mm case and rounded rear-cover candidate have separate status. Battery dimensions/lead dress, B-pad solder access, ferrite notches, display flex, cover fixing and key travel need the mechanical iteration and fit sample. See the [height handoff](../enclosure/r1-height-handoff.md) and [rounded candidate](../enclosure/r1-rounded-rear-study/README.md).

The current files can be uploaded for a fabrication/assembly quote and DFM review now. Before payment, accept the supplier's actual parts, connector placement and hole/profile review. Firmware development and RF/USB/physical validation can follow on the first small prototype batch. Print a fit sample before ordering finished transparent housings; the preferred rounded cover still needs a closure decision. This is an engineering prototype, not a production-qualified release.

## Next-task handoff

The PCB/manufacturing checkpoint is `ccdc51d`; the subsequent recovery decision above does not change the PCB or Gerber. The user plans a separate task for production verification. Start with the current Gerber, BOM/CPL and assembly PDF: verify export consistency, inspect the supplier's board preview, select fabrication parameters, review drill/slot/profile acceptance, and match actual assembly parts, orientation, availability and tooling rails. Record the quote and unresolved supplier findings before ordering. Do not reopen the hidden RESET decision or request further clip dimensions. Enclosure iteration proceeds separately; firmware and assembled RF/USB/fit tests remain prototype work.

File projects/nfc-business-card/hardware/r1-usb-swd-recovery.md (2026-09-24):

# R1 USB firmware update and SWD recovery review

Status: hardware review and USB resistor correction completed; firmware and physical USB/SWD operation are unverified. The five SWD lands now use 2.54 mm pitch for the user-selected single-row 5P clip. The user accepted nominal fit assumptions; detailed clip metrology is not a release gate. No factory programming is requested.

**Recovery decision, 2026-09-24:** the user accepts connecting an SWD programmer for recovery. Retain GND, VDD_3V3/VTref, SWCLK, SWDIO and NRESET; do not add a hidden RESET switch or side access hole for R1. The earlier RESET mechanical study is reference only and is no longer an ordering decision. Routine USB updates/logs remain planned firmware work; standalone button-only recovery with a failed application is not required.

## Implemented hardware correction

R3 and R4 changed from 27 ohm to **0 ohm, UNI-ROYAL 0603WAF0000T5E / C21189**, using the existing R0603 lands and component locations. Schematic and PCB instance procurement fields are synchronized. Nordic states that the nRF52840 USB PHY already includes the series resistors; extra termination is not required. Keeping the two lands permits later measured changes without a layout change. [Nordic verified answer](https://devzone.nordicsemi.com/f/nordic-q-a/94955/resistors-for-d-and-d-), [Nordic signalling discussion](https://devzone.nordicsemi.com/f/nordic-q-a/82014/nrf52840-usb-d-d--impedance-matching/340456).

## Netlist checks

| Function | Current connection / finding |
| --- | --- |
| USB D+ | J1 A6/B6 → USB_DP_CONN / U5 protection → R3 → U1.35 |
| USB D− | J1 A7/B7 → USB_DM_CONN / U5 protection → R4 → U1.34 |
| Type-C detection | CC1 and CC2 each have their own 5.1 kohm Rd to GND; U6 protects these lines. No USB PD or advertised-current detection controller is present. |
| USB supply | J1 VBUS → U1.32 and U2.10; C1 is the local 2.2 µF module VBUS capacitor, C8 is the charger 4.7 µF input capacitor. |
| Module power | U2 SYS → U3 TPS7A0233 → VDD_3V3 → U1 VDD and VDDH. DCCH remains unconnected in normal voltage mode. |
| Charge enable | R7 pulls CHG_CE_N high by default. Firmware must explicitly enable charging and set a battery-appropriate current. |
| Existing recovery input candidate | SW2 / KEY_NEXT_N → U1.4 / P1.11, active low, with a 10 kohm pull-up. Final bootloader board configuration must agree. |
| Reset | U1.40 / P0.18 → TP5 NRESET. There is currently **no physical RESET switch**. Configure both UICR PSELRESET registers during initial SWD programming. |
| VBUS protection limit | U5/U6 protect signal lines; they are not a VBUS clamp. The charger's input protection does not protect the parallel U1 VBUS branch. VBUS hot-plug waveform / ESD protection remains a review and bench item; no surge immunity is claimed. |

USB uses its own VBUS-powered regulator; supplying only VDD_3V3 does not establish USB operation. [Nordic power specification](https://docs.nordicsemi.com/r/bundle/ps_nrf52840/page/power.html).

The charger's default input limit is 500 mA; its default charge current is 10 mA, and CE is pulled inactive on this PCB. This does not prove compliance with a USB host's pre-enumeration or suspend limits. Both bootloader and application must control their total VBUS load, choose a conservative limit before enumeration, and handle suspend/detach. Do not infer a right to draw 1.5/3 A from the two Rd resistors. Battery charging limits also require the actual pack's specification. [TI BQ25186 data sheet](https://www.ti.com/lit/ds/symlink/bq25186.pdf), [TI default charge current clarification](https://e2e.ti.com/support/power-management-group/power-management/f/power-management-forum/1540320/bq25186-spec-check).

## Firmware and recovery contract

1. **First programming:** the user powers the board and uses SWD to program a board-specific bootloader and required configuration. Treat VDD_3V3 as the debugger's target-voltage reference by default; do not simultaneously drive it from an unrelated programmer supply.
2. **Routine update:** evaluate Adafruit nRF52 UF2 with the final framework. NCS/Zephyr is a candidate, not a frozen production port. Confirm bootloader/SoftDevice/MBR layout, application link address, UF2 family identifier, USB identity, LF clock source, button GPIO and flash protection. Do not flash an unrelated board's complete image.
3. **Application failure:** connect the SWD programmer and recover through the retained SWD/NRESET pads. Firmware may additionally support holding SW2 while the programmer asserts NRESET to enter the bootloader, but direct SWD reprogramming remains the fallback. A runtime USB command alone is insufficient when the application cannot start; no standalone hidden RESET is required for R1.
4. **Interrupted application update:** retry through the bootloader if reachable; otherwise recover with SWD. UF2 does not inherently guarantee automatic rollback or a second application image; use an explicitly designed MCUboot / dual-image scheme if that becomes a requirement.
5. **Bootloader / configuration failure:** retain all five SWD signals as the recovery path. Document whether a debugger recovery mass-erase is needed and warn that it removes stored user data. Do not enable debug protection without a deliberate recovery decision.
6. **Logs:** application USB CDC ACM is the candidate console, using bounded/non-blocking buffering and detach handling. UF2 bootloader USB and application USB are separate firmware states. USB logs/update do not provide SWD breakpoints.

A battery keeps the MCU powered when USB is unplugged. USB insertion/removal is therefore not a reliable reset mechanism. [Adafruit bootloader](https://github.com/adafruit/Adafruit_nRF52_Bootloader), [Zephyr UF2 board example](https://docs.zephyrproject.org/latest/boards/adafruit/feather_nrf52840/doc/index.html), [Zephyr CDC ACM](https://docs.zephyrproject.org/latest/services/connectivity/usb/device_next/cdc_acm.html), [Nordic UICR](https://docs.nordicsemi.com/r/bundle/ps_nrf52840/page/uicr.html).

## Mechanical handoff — proposals, not installed parts

### Hidden RESET — not selected for R1

The following dimensions preserve the earlier study only. The user selected SWD programmer recovery; do not implement this switch or its opening as part of R1 production preparation.

A rear-mounted switch cannot be assumed to fit the current **0.32 mm** PCB-to-rear-cover space. Assess a front-side, side-operated switch with an inconspicuous right-wall tool hole.

Candidate for CAD assessment: **Alps SKSCLBE010**, nominal **3.5 × 3.55 × 1.25 mm**, side push, 0.2 mm travel, 2.2 N force, with guide bosses. The manufacturer drawing must determine the full land/body envelope, boss penetration, actuator datum and tool clearance. [Manufacturer specification](https://tech.alpsalpine.com/e/products/detail/SKSCLBE010/).

The [CAD candidate study](../enclosure/r1-recovery-study.md) found space at front-coordinate datum **C = (80.30, 8.60) mm**, actuator toward +X, pressed toward −X. This datum is defined by the manufacturer drawing, not an EDA library origin. The operating end is at X = 82.40 mm; its axis is approximately outer-case Z = 2.620 mm. The full terminal span is 4.85 ±0.10 mm and recommended land span is 5.00 mm; the body dimensions alone are insufficient.

The conservative body/terminal envelope, including 0.10 mm assumed installation allowance, is **X 78.70…82.55, Y 6.075…11.125, Z 1.920…3.420 mm**. It clears the studied rounded upper case by at least 0.85 mm and passes its insertion sweep. Two locating holes are proposed at (79.40,8.60)/(81.20,8.60) mm, Ø0.80 +0.05/0 mm; the maximum 0.60 mm boss length fits within the 0.80 mm PCB. The final footprint still needs mounting-face/mirroring and all-layer copper checks.

A Ø2.0 mm side access hole was evaluated at Y = 8.60, Z ≈ 2.620 mm. A hypothetical Ø0.6 mm tool travels approximately 2.2 mm to the actuator and 2.4 mm at full nominal travel. **Tool guidance, allowable offset, overtravel stop and physical force/return are unresolved.** This establishes candidate space only. No PCB pads, board holes, switch BOM row or released CAD openings have been added. The study is against the rounded enclosure candidate; it does not modify or release the packaged frozen 5.8 mm shell.

### Five-pin clip

Selected fixture: **绿深旗舰店 / 单排5P探针模块（2.54mm间距）**, from the user's product screenshot on 2026-09-24. No manufacturer model number was shown. The user explicitly accepted adaptation by nominal pitch without waiting for exact needle projection/jaw dimensions. The first illustration labels fixture needle holes as Ø1.5 mm; this does not establish contact-tip diameter. These assumptions remain subject to physical trial fit, not further drawing requests.

The native PCB now has **five rear lands at exactly 100 mil / 2.54 mm pitch**, with the original row centre and Y retained. Coordinates below use the **front PCB coordinate system**, in mm:

| Land | Signal | X | Y | Identification |
| --- | --- | ---: | ---: | --- |
| TP1 | GND | 65.92062 | 48.49876 | Square, pin 1 |
| TP2 | VDD_3V3 / VTref | 68.46062 | 48.49876 | Circle |
| TP3 | SWCLK | 71.00062 | 48.49876 | Circle |
| TP4 | SWDIO | 73.54062 | 48.49876 | Circle |
| TP5 | NRESET | 76.08062 | 48.49876 | Circle |

Land size is approximately **1.20 mm** (native 1.19888 mm). Total first-to-last centre span is **10.16 mm**. TP1's square shape and the individual GND/3V3/CLK/DIO/RST rear labels identify orientation; this is visual identification, not mechanical keying. With PCB +Y upward in a front projection the table runs left to right; looking through the back about the vertical axis reverses that order. Match the square GND end and the actual debugger cable signal labels before connecting. VDD_3V3 is target-voltage reference by default.

Local rear access traces were adjusted without moving components or adding vias. Saved/reopened native DRC is zero; independent copper checks pass. [Applied plan](records/r1-swd-254-plan.json), [saved geometry and preservation checks](records/r1-swd-254-check.json).

CAD uses **Ø1.60 mm holes with an outer R0.05 mm mouth** for the revised access. At 2.54 mm pitch the bore web is 0.94 mm and minimum surface web is **0.84 mm**. The nominal rear face-to-pad depth remains **1.12 mm**. The [rounded rear-cover candidate](../enclosure/r1-rounded-rear-soft-swd254/README.md) documents the five-hole change; the packaged clear case is synchronized separately and checked against these PCB coordinates. Keep the existing 0.8 mm bare board and 5.8 mm enclosure for trial fitting. Probe reach, spring compression, coatings and reliable contact are physical checks, not claimed compatibility measurements.

## Required physical tests

- SWD identify, initial bootloader program, reset pin operation, and recovery after an intentionally invalid application.
- USB A-to-C and C-to-C data cables, both plug orientations; enumeration in bootloader and application; battery-only / USB-only / both-source transitions.
- VBUS hot-plug peaks, 3.3 V stability and source/backfeed behaviour; total pre-enumeration, configured and suspend current; conservative battery charge configuration.
- UF2 update interruption and retry; SWD/NRESET recovery with an invalid application while the battery remains connected. If implemented, test SW2 plus programmer-driven reset as an additional bootloader entry.
- USB log handling with no host, closed terminal and unplugged cable; no display/button task stalls.
- Actual clip registration, electrical contact and non-shorting through the assembled cover.

These are open verification items, not features marked usable.

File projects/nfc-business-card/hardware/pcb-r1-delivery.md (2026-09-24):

# NFC Card R1 — routed engineering prototype

## Current files

- Native source: [NFC-Card-R1.eprj2](../../../eda/NFC-Card-R1.eprj2). One board, one PCB, one four-page schematic. The original E14-named project is unchanged.
- Complete local handoff: [NFC-Card-R1-prototype.zip](../artifacts/NFC-Card-R1-prototype.zip).
- Actual copper review: [front/rear PNG](../enclosure/renders/r1-routed-front-rear.png).
- Coordinated clear case: [R1 CAD](../enclosure/r1-clear-5.8/e20-clear-assembly.FCStd), [STEP](../enclosure/r1-clear-5.8/e20-clear-assembly.step), [tray STL](../enclosure/r1-clear-5.8/e20-clear-tray.stl), [lid STL](../enclosure/r1-clear-5.8/e20-clear-lid.stl), [three keys STL](../enclosure/r1-clear-5.8/e20-clear-keys.stl).
- Frozen design inputs: [r1-design.json](r1-design.json). Verification: [r1-validation.json](records/r1-validation.json).

This is a routed, editable prototype handoff. NFC performance and physical assembly have not been tested; it is not a production-qualified product. No manufacturing order has been submitted.

## Review status

Checkpoint `bee8846` preserves the antenna, CC2, battery-pad and enclosure studies. Subsequent work eliminates all nominal 0.2 mm drills and adds two USB ground stitching vias. The previous C1 finding was incorrect: C1 bypasses U1 VBUS and C8 already bypasses the charger input. [Layout review](pcb-r1-review.md) and [pre-order DFM/assembly brief](r1-preorder.md) describe evidence and remaining work.

The latest grouped CE/SCL reroute removes two vias and 4.88 mm of trace. R3/R4 are now 0 ohm / C21189. [USB/SWD review](r1-usb-swd-recovery.md) records the user-programmed bootloader plan, implemented 2.54 mm SWD interface and hidden RESET candidate; these recovery features are not yet physically qualified.

## Implemented changes

All 58 component positions, rotations and footprints, and the board outline, retain the accepted E20D placement. The old project is preserved by SHA-256 comparison. Detailed routing now contains 819 line segments, 153 vias, 248 pads and two ground pours.

The complete screen projection through all three exposed board edges is free of pours on both copper layers: X 0–39.62, Y 17–52 mm. The user selected a specific top-layer exception for B+/B− lands at (32.5,18.7)/(35.5,18.7) mm and their narrow routes; all other non-NFC copper remains excluded. See [battery plan](records/r1-battery-b-plan.json) and [RF/assembly limits](../enclosure/r1-height-handoff.md#battery-b-and-ferrite-integration). Five rear debug pads now use X 65.92062/68.46062/71.00062/73.54062/76.08062, Y 48.49876 mm (GND/3V3/CLK/DIO/RST), at 2.54 mm pitch. TP1/GND is square and the other lands are circular; rear signal labels follow the new centres. The R1 bottom cover has matching Ø1.60 mm access holes and R0.05 outer mouths; the nearby support remains clear. The screen, key and USB openings retain their accepted positions.

The rear antenna is a five-turn spiral, outer centreline 29.9 × 27.6 mm, nominal trace/space 0.25/0.25 mm, 45° chamfers and 3 mm centreline offsets from the three exposed straight edges, covered by solder mask. The two NFCT terminals share a native net through a schematic short flag. A separate cut-and-reconnect proof verifies that the winding is not bypassed; ordinary net connectivity alone cannot prove this. C23/C24 remain **220 pF C0G provisional tuning values**. U1.52 connects through the C23 branch to NFC2; U1.54 through C24 to NFC1. These pad names are terminal identifiers, not proof of RF tuning.

USB protection/fanout, display power loops and local decoupling were routed before remaining controls and signals. Their construction records are [critical routes](records/r1-critical-plan.json), [local decoupling](records/r1-decoupling-plan.json), [coil](records/r1-nfc-coil-plan.json) and [RF ground return](records/r1-rf-ground-short-plan.json). Final exported geometry, rather than these construction plans, is the verification input. Short local power paths use 0.25–0.4 mm widths; control routing uses finer tracks where needed. USB is full speed; this two-layer layout has no controlled-impedance certification. Charger/display transient behaviour and USB operation still require powered board tests.

Major reference labels remain on the front silkscreen. Fine passive designators are on the assembly layer/PDF, with rear debug labels printed at 1.0 mm height and 0.15 mm stroke. The copper PNG adds reference labels for review; it is not a photorealistic rendering of final silkscreen.

## Verified evidence

| Check | Result |
| --- | --- |
| Saved, closed and reopened native project | SQLite `quick_check=ok`; native DRC **0** |
| Schematic vs PCB | 58 references, 238 component pins, **0 mismatches** |
| Independent physical copper, including ground pours/thermal spokes | **0 split nets, 0 dead ends** |
| Screen exclusion | **0 unexpected copper / 0 poured copper**; only the selected top battery lands/routes are excepted |
| Redundant via audit | **0 isolated or single-layer vias**; three removed along with one dead stub |
| NFC winding | Connected before cut; two correct branches after cutting an outer turn; deliberate bypass rejected |
| Gerber outline | One closed contour, native corner radii, no competing mechanical contour |
| Drills | 153 vias and four 0.6 mm plated mounting slots match the PCB |
| BOM / CPL | 58 references each; positions and rotations match native reference coordinates |
| Stack | Two copper layers, native total 0.800024 mm (nominal 0.8 mm) |
| CAD | See [R1 mechanical check](records/r1-mechanical-check.json); nominal shell/component geometry only; [new wire/ferrite service bodies remain pending](../enclosure/r1-height-handoff.md) |

The native J1 CPL automatic midpoint is 0.15 mm left of its reference origin because the custom signal lands shift the footprint bounds. The native values are retained, and both midpoint and reference coordinates are supplied. Confirm J1 orientation/registration in the assembler's placement preview, as with other connectors.

The independent pour parser was calibrated using asymmetric arc endpoints and a deliberately wrong tenfold fill-unit scale. The historical copper checker omitted pour contact from its dead-end logic; the R1 checker includes actual filled copper and thermal spokes. Native DRC connection results were stale during routing, so the final result was obtained after a full save/quit/reopen cycle.

## Fabrication and assembly parameters

Use the **R1 Gerber ZIP** for an engineering prototype: nominal PCB **81.8 × 49.8 mm**, routed L-shaped outline, two layers, **0.8 mm FR-4**, **1 oz outer copper**, solder mask over the antenna. Standard plated through vias and routed profile; no buried/blind vias, flex process or four-layer conversion. A flat ENIG finish is a reasonable assembly option; mask colour remains a cosmetic choice. Confirm vendor DFM for the custom USB footprint and small plated slots before fabrication.

The export retains only copper, silk, mask, paste and board-outline layers plus native drill/test data. BOM and CPL are normalized to UTF-8 CSV; original native UTF-16 tab-delimited versions remain in the local routing artifacts. The PCB STEP and seven-page native assembly PDF accompany the source project. The PDF includes both assembly faces, BOM, copper faces and drilling.

Public manufacturing references checked for this revision: [JLCPCB capabilities](https://jlcpcb.com/capabilities/Capab) and [assembly capabilities](https://jlcpcb.com/capabilities/pcb-assembly-capabilities). The covered coil's 0.25/0.25 mm nominal geometry exceeds the published 0.15/0.15 mm covered-coil requirement. The USB uses the [GCT USB4500](https://gct.co/connector/usb4500) mechanical family; E20D's documented land/cutout adaptation remains part of this prototype.

The case is **85.2 × 53.2 × 5.8 mm**, two transparent printed halves with 0.8 mm panels, 1.2 mm perimeter walls and three separate keys. No full-height crossbeams. PET/PSA support pieces and patterned adhesive are still assembly consumables; there is no separate PC cover sheet. STL dimensions are in millimetres. The user's vendor specifies 0.8 mm nominal walls and ±0.2 mm accuracy; resin identity and feature-specific tolerances have not been approved. Print one fit sample before treating this enclosure as qualified.

## Physical work still required

1. Measure the complete protected battery, sealed edges and leads. Nominal 31 × 12 × 3 mm is selected; the assumed maximum envelope is 32.5 × 14 × 3.4 mm.
2. Fit the fully inserted display flex and align the screen active area to the bezel. The connector must not pull the screen into alignment. Check USB access, lid bonding, keys and debug access on the printed sample.
3. Bring up the PCB with current-limited power, verify rails/charging/display/USB/SWD, then test NFC using the final screen and case. Measure/tune C23/C24 and evaluate ferrite if required. A PN532 desk test does not qualify the nRF52840 PCB antenna. [Nordic NFCT reference](https://docs.nordicsemi.com/r/bundle/ps_nrf52840/page/nfc.html).

## Reproduce checks

Run from the repository root, after installing `projects/nfc-business-card/scripts/requirements.txt`:

```sh
python3 projects/nfc-business-card/scripts/check-r1-copper.py --snapshot projects/nfc-business-card/hardware/records/r1-routed-snapshot.json --output projects/nfc-business-card/hardware/records/r1-copper-check.json
python3 projects/nfc-business-card/scripts/check-r1-nfc.py --snapshot projects/nfc-business-card/hardware/records/r1-routed-snapshot.json --output projects/nfc-business-card/hardware/records/r1-nfc-check.json
python3 projects/nfc-business-card/scripts/check-netlist-consistency.py --sch projects/nfc-business-card/hardware/records/r1-schematic.enet --pcb projects/nfc-business-card/hardware/records/r1-pcb-pins.json
python3 projects/nfc-business-card/scripts/check-e20-outline.py --snapshot projects/nfc-business-card/hardware/records/r1-routed-snapshot.json --gerber projects/nfc-business-card/hardware/production/r1/NFC-Card-R1-gerber.zip --output projects/nfc-business-card/hardware/records/r1-profile-check.json
python3 projects/nfc-business-card/scripts/check-r1-delivery.py
python3 projects/nfc-business-card/scripts/check-r1-usb-swd.py
python3 projects/nfc-business-card/scripts/render-r1-copper.py --snapshot projects/nfc-business-card/hardware/records/r1-routed-snapshot.json --output projects/nfc-business-card/enclosure/renders/r1-routed-front-rear.png
```

Live snapshot export: `eda-export-r1-snapshot.js`, guarded by both project and PCB UUID. Native final DRC, rule configuration, topology, profile, parser calibration and release-file hashes are recorded under `hardware/records/r1-*`.

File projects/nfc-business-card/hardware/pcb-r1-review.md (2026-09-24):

# R1 antenna and layout review — 2026-09-24

## Status

**Reviewed engineering prototype; vendor DFM and powered/physical tests remain open.** Earlier checkpoints are `bee8846` (PCB/CAD studies) and `ccf9f92` (organization). The current repository checkpoint includes the subsequent drill, return-path, control routing, USB resistor and 2.54 mm SWD/CAD changes. [Current files](../README.md), [machine-readable review](records/r1-review.json), [actual copper preview](../enclosure/renders/r1-routed-front-rear.png).

All 58 component placements, footprints and rotations are unchanged. The board outline is unchanged. SWD cover access is synchronized to the new 2.54 mm pitch. Routing now has **819 segments and 153 vias**. The immediately preceding drill/return-path revision had 825 segments and 155 vias; checkpoint `bee8846` had 824 and 153. Component values R3/R4 are now 0 ohm; their geometry is unchanged.

## Implemented

| Item | Before | After / evidence |
| --- | --- | --- |
| Screen projection | The old rectangle stopped short of the exposed board edges, leaving GND strips | Both layers free of pours in X 0–39.62, Y 17–52 mm, including all three exposed edges; later user-selected top battery B lands/routes are the only non-NFC exception |
| Coil | Five rectangular turns, outer centreline 30 × 24 mm; unequal edge offsets | Five turns, 20 corners at 45°; outer centreline 29.9 × 27.6 mm |
| Edge spacing | Left 2.9, lower 2.7, upper 6.9 mm to centreline | All three 3.000 mm to centreline / 2.875 mm to copper edge |
| Winding spacing | 0.25 mm nominal | 0.25 mm straight and diagonal minimum; 0.50 mm normal pitch maintained through nested chamfers |
| USB CC2 protection | Load branch before U6, leaving about 3.30 mm of TVS stub | Load leaves U6's protection pad; two added vias are on the protected load branch. Incoming connector routing is retained |
| Independent copper audit | Only copper groups containing pads/vias were examined | Detached fill fragments are also checked; injected orphan-fill negative control is rejected |

The coil is made from native PCB trace primitives, with a top crossover and two preserved vias. It is not an image or silkscreen drawing. The native single-net representation is intentional; a separate cut proof checks that the winding is not bypassed.

Nearby conductive material can introduce eddy-current losses and detuning. This supports removing the unnecessary rim, but does not quantify the improvement on this board. The screen remains a nearby load, and the changed winding requires assembled RF tuning. The matching capacitors remain provisional. [NXP AN11564, sections 2.2 and 3.2](https://www.nxp.com/docs/en/application-note/AN11564.pdf).

## Battery B and redundant-via follow-up

Following the user-requested 1.5 mm right shift, B+/B− are at **(32.5,18.7)/(35.5,18.7) mm**, with the battery lead exit at the upper right. Rounded 1.8 × 1.5 mm top lands have approximately **0.65 mm** board-edge clearance, polarity silk and 0.35 mm power routing. A 0.20 mm GND link reconnects a pour island isolated by the new route. No screen-area pours were restored. [Plan](records/r1-battery-b-plan.json), [checks](records/r1-battery-b-check.json).

Removed three vias that no longer join copper on both faces:

| Net | XY, mm | Removed geometry |
| --- | --- | --- |
| BAT_PACK_TBD | (45.840,24.646) | Via at former battery landing route; bottom traces remain joined |
| USB_CC2 | (72.100,28.800) | Via with only top traces after CC2 rerouting |
| VDD_3V3 | (61.665,17.936) | Via and the unused top branch ending there |

Nearby GND stitching vias still contact both face pours and are retained. The audit now checks each via for copper contact on both faces; an injected single-layer CC2 via is rejected. It also rejects unapproved screen-area tracks and any new pour, even inside an allowed battery pad.

The top battery routes cross rear NFC feedlines in XY and approach the winding to approximately **0.87 mm in XY**, on opposite PCB faces. The pads alone remain about 0.73 mm from NFC copper. The right shift increases the route-to-winding XY gap from 0.15 to 0.87 mm; feedline crossings are unchanged. These are geometric facts, not RF qualification. The ferrite lies between the PCB and screen; it does not isolate front battery copper from the rear coil. Assembled tuning remains required.

The user deferred thickness/button work. The [height handoff](../enclosure/r1-height-handoff.md) retains the current 5.8 mm case and records the 3.4 mm pack / 0.25 mm sheet assumptions. The frozen CAD wire/ferrite service volumes need updating for B-pad access in the next mechanical iteration.

## Charger-control routing cleanup

The foldback near (49,23.2) and the overlapping SCL segment were reviewed together with adjacent routing. The saved result reroutes CHG_CE_N and CHG_SCL as a group:

| Net | Segments before → after | Vias before → after | Length before → after |
| --- | ---: | ---: | ---: |
| CHG_CE_N | 29 → 21 | 6 → 4 | 39.56 → 32.98 mm |
| CHG_SCL | 18 → 19 | 4 → 4 | 33.76 → 35.46 mm |

Together: **7 fewer segments, 2 fewer vias and 4.88 mm less trace**. SCL grows by 1.70 mm to free the shorter CE path. This is a verified local improvement, not a claim of globally optimal routing. The numbers come from the saved/reopened native snapshot; EDA merged some proposed segments during creation. All unrelated net traces/vias, pads, placements, board outline and antenna exclusions match the preceding snapshot exactly. USB D− and CC2 retain their functional crossings and protection routing.

[Before/after front and rear comparison](../enclosure/renders/r1-control-routing-comparison.png), [actual metrics and preservation checks](records/r1-route-cleanup-check.json), [construction plan](records/r1-route-cleanup-plan.json).

## USB firmware and recovery hardware

R3/R4 changed from 27 ohm to **0 ohm / C21189**, with schematic/PCB procurement fields and native BOM synchronized. The nRF52840 PHY already includes series resistors. D+/D−, CC pull-downs, VBUS, charger defaults, existing key and all five SWD signals were checked against the netlist. [Hardware review, primary references and firmware/bench follow-up](r1-usb-swd-recovery.md), [machine checks](records/r1-usb-swd-check.json).

UF2 and USB CDC remain firmware candidates requiring board-specific implementation and tests. The user will perform initial SWD programming; no factory programming is requested. The user selected the generic Lushen single-row 5P clip and accepted nominal 2.54 mm fit assumptions. Five rear lands/silk and their access routes are updated; TP1/GND is square for orientation. A physical trial fit remains. [SWD change check](records/r1-swd-254-check.json). A hidden side-operated RESET has a [CAD space study](../enclosure/r1-recovery-study.md), but its tool guide/stop and final footprint are not released; no RESET component has been added.

## Findings to discuss

### 1. C1/C8 service assignment — previous finding retracted

The previous review mapped C1 to U2.10 and omitted C8. That was incorrect. **C1.1 is 1.24 mm from U1.32 (module VBUS); C8.1 is 1.75 mm from U2.10 (charger IN).** Both capacitors share `USB_VBUS`, but serve different local loads. No component was moved. The checker now names both service pairs, with ground-via distances computed from the saved geometry.

C8 is Samsung CL10A475KO8NNNC, 4.7 µF / 16 V / X5R. Its manufacturer typical 25 °C DC-bias curve gives about 2.35 µF at 5 V (about 2.12 µF when also allowing −10% nominal tolerance). TI requires at least 1 µF effective IN capacitance. This supports the existing 5 V input choice; it does not guarantee full-temperature behaviour or replace transient testing. The manufacturer now marks this part NRND and suggests CL10A475KO8NQN#; no BOM substitution was made. [Samsung product data](https://product.samsungsem.com/mlcc/CL10A475KO8NNN.do), [TI sections 7.2.2/9.1](https://www.ti.com/lit/ds/symlink/bq25186.pdf), [recorded evidence](records/r1-input-capacitor-check.json).

### 2. USB return stitching — partial geometric improvement

Added GND vias at **(52.25,12.35)** and **(75.00,24.15) mm**, outside SMT lands. Both touch copper on both faces and belong to the single connected GND network. The worst nearest-GND-via distance falls from **3.66 to 2.62 mm**. Four USB transitions remain above the contextual 1.6 mm guideline (about 1.68, 2.11, 2.46 and 2.62 mm).

A closer candidate at (53.35,14.95) would sit in a region isolated from local GND on both layers; local 0.25 mm GND-route screening could not connect it without crossing existing copper. It was not installed. Eliminating every detour would require additional signal rerouting; the proximity guideline alone does not establish that tradeoff is necessary for USB full speed. Reference continuity and USB operation remain prototype validation items, not claimed fixes or certifications.

### 2a. Small holes — enlarged

All six nominal 0.2 mm holes are gone: five USB holes are now 0.25 mm with 0.45 mm lands; the battery via is now 0.30/0.55 mm, shifted 0.15 mm left. Battery solder lands remain at the user's selected positions. The two former 0.30/0.20 mm CC2 vias now have a nominal 0.10 mm annular ring instead of 0.05 mm. The board remains two-layer, with 97 nominal 0.25 mm and 56 nominal 0.30 mm vias. [Decision, current capabilities and remaining vendor checks](r1-preorder.md).

### 3. NFC screen/ferrite/tuning — physical validation

The enlarged coil is still behind the screen. The existing optional ferrite service envelope covers it, but neither a ferrite material nor a final tuning capacitance has been qualified. Test the assembled screen, case and battery environment. Keep the ground rim removed during those tests.

## Other reviewed areas

| Rule / area | Computed result / applicability |
| --- | --- |
| GP-003 / ground connectivity | One connected GND network across layers; no orphan copper fragments |
| BLE module keepouts | No copper intrusion in either all-layer keepout or top-only extension |
| ES-002 / TVS ground | U5 nearest GND via 0.899 mm, 7 within 3 mm; U6 0.800 mm, 6 within 3 mm |
| ES-001 / CC2 topology | Removing the incoming U6 trace separates J1 from the U6 + R2 branch; prior pre-protection tee removed |
| SW-002 / switching node | `EPD_SW` copper area 9.757 mm²; below the upstream 25 mm² review threshold |
| SW-003 / placement proxy | C10–L1–Q1 pad triangle 5.643 mm²; e-paper charge-pump topology needs waveform validation, not a generic buck-loop claim |
| Ground ring BE-002 | Not applied inside the NFC keepout; its plane-pair edge-emission premise does not override antenna clearance |
| GP-002 / inner-layer rules | Not applicable to this two-layer board |
| Full-board copper-fill percentage | Not a gate because NFC/BLE clearances intentionally remove copper |
| Mechanical reuse | 58 unchanged placements and outline; 238 exported component STEP solids match in volume, area and bounds; the 5.8 mm case has synchronized 2.54 mm SWD holes |

The TVS routing change follows TI's recommendation to eliminate the branch between the protected line and the TVS. It does not claim ESD qualification; the retained connector fanout still uses layer changes. [TI SLVA680A, sections 2.1 and 2.3](https://www.ti.com/lit/an/slva680/slva680.pdf).

## Verification

Saved, closed and reopened native DRC: **0**. Independent copper: **0 split nets, 0 dead ends, 0 orphan copper, 0 single-layer or isolated vias**. Schematic/PCB: **58 references, 238 pins, 0 mismatches**. NFC winding cut and deliberate bypass negative control pass. Coil corners/spacing/edge offsets and the expanded screen/BLE exclusions are measured from the saved native snapshot. Manufacturing exports are refreshed for this review checkpoint.

```sh
python3 projects/nfc-business-card/scripts/review-r1-layout.py --snapshot projects/nfc-business-card/hardware/records/r1-routed-snapshot.json --pins projects/nfc-business-card/hardware/records/r1-pcb-pins.json --output projects/nfc-business-card/hardware/records/r1-review.json
```

See [delivery checks](pcb-r1-delivery.md#reproduce-checks) for copper, topology, netlist, profile and bundle verification. Passing these checks does not qualify RF, USB operation or physical assembly.

## Method and provenance

Applied the repository [pcb-methodology skill](../../../.agents/skills/pcb-methodology/SKILL.md), with read-only references to:

- `upstreams/kicad-happy/skills/emc/references/pcb-emc-rules.md`, revision `a6bba1add1e18b89e3aa0824b9769ed1d9d79174`: DC-001/DC-003, GP-003, SW-002/SW-003, ES-001/ES-002, RP-001 and BE-002.
- `upstreams/pcb-skill/skills/pcb/SKILL.md`, revision `6e939b64907e3c63236c7522c511af5d7d1afaad`: independently verify physical geometry and manufacturing outputs.
- `upstreams/pcba-design-skills/.agents/skills/pcb-layout-review/references/layout-review-checklist.md`, revision `d41e9996f052016727403236cf0f7476f8f23a1b`: prove each copper fragment reaches its net; invalidate downstream evidence after copper changes.

Thresholds are used only with stated board-specific applicability. This was one agent's systematic review with independent exported-geometry checks, not a separate human review or physical certification.

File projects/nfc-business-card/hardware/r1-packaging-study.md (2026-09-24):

# R1 thickness and battery landing study

## Superseding decision

The user selected **option B, screen lower-edge battery pads**. That PCB change is now applied and verified; [route plan](records/r1-battery-b-plan.json), [checks](records/r1-battery-b-check.json), and [updated PCB review](pcb-r1-review.md). The battery lead exit is at the upper right. **Thickness and button manufacturing are deferred; retain the current 5.8 mm case.** Regional heights and mechanical follow-up are recorded in the [height handoff](../enclosure/r1-height-handoff.md).

The comparison below is the earlier study, tied to its recorded pre-change snapshot. Its A recommendation was superseded by the user's B selection. Pad-only distances below do not include the implemented routes. The historical A/B image is not the current PCB.

## Earlier proposal (historical)

Discussion study, 2026-09-24. **No active PCB, enclosure or manufacturing export is changed by this study.** The study is retained in the repository checkpoint; its proposed thickness changes remain unimplemented. The user accepted a **3.4 mm battery maximum** and **0.25 mm ferrite sheet** for calculations; these are design inputs, not measurements. The ferrite allocation includes adhesive; separate tape must be added if necessary.

- Preferred next mechanical candidate: **5.6 mm overall / 4.0 mm cavity**, with a revised 0.8 mm key flange.
- 5.4 mm overall / 3.8 mm cavity is a tighter fitting experiment requiring further key design or measured fit.
- Preferred battery landings: **beside the vertical battery cutout, between SW1 and SW3**. Keep the full screen/NFC copper exclusion.

Evidence: [computed study](records/r1-packaging-study.json), [reproduction script](../scripts/study-r1-packaging.py). Dimensions below come from the active CAD and PCB snapshot. Component library models are nominal; maximum MCU and screen heights come from the design inputs.

## Thickness by region

Retain the 0.8 mm floor and lid. The 0.32 mm PCB support is a physical stack of 0.20 mm PET and two 0.06 mm adhesive layers, not unused air. The PCB is 0.8 mm thick. Take the **maximum regional stack**, not the sum of all regions.

| Region | Occupied height above the inner floor | Treatment |
| --- | --- | --- |
| Battery | 0.10 adhesive + 3.40 pack = **3.50 mm** | The old 0.40 mm allowance above a nominal 3 mm cell is already included in the accepted maximum; do not recover it a second time |
| Recessed USB | 0.32 support + 3.170 model = **3.490 mm** | The connector shares the PCB height; do not add another 0.8 mm |
| MCU | 0.32 support + 0.80 PCB + 2.20 maximum = **3.32 mm** | Includes the model-to-maximum allowance |
| FPC socket | 0.32 + 0.80 + 2.010 model = **3.130 mm** | Flex bend is checked separately; the open-lid service volume is not a closed-flex envelope |
| Screen | 0.32 + 0.80 + 0.10 sheet spacing + 0.25 ferrite + 1.00 screen + 0.06 adhesive = **2.53 mm** | The remaining cavity height is the gap between ferrite and screen; the active area remains open |

The [GCT USB4500](https://gct.co/connector/usb4500) specifies a 3.16 mm profile and 0.80 mm offset. The actual imported model is slightly taller, so the study uses its 3.170 mm extent.

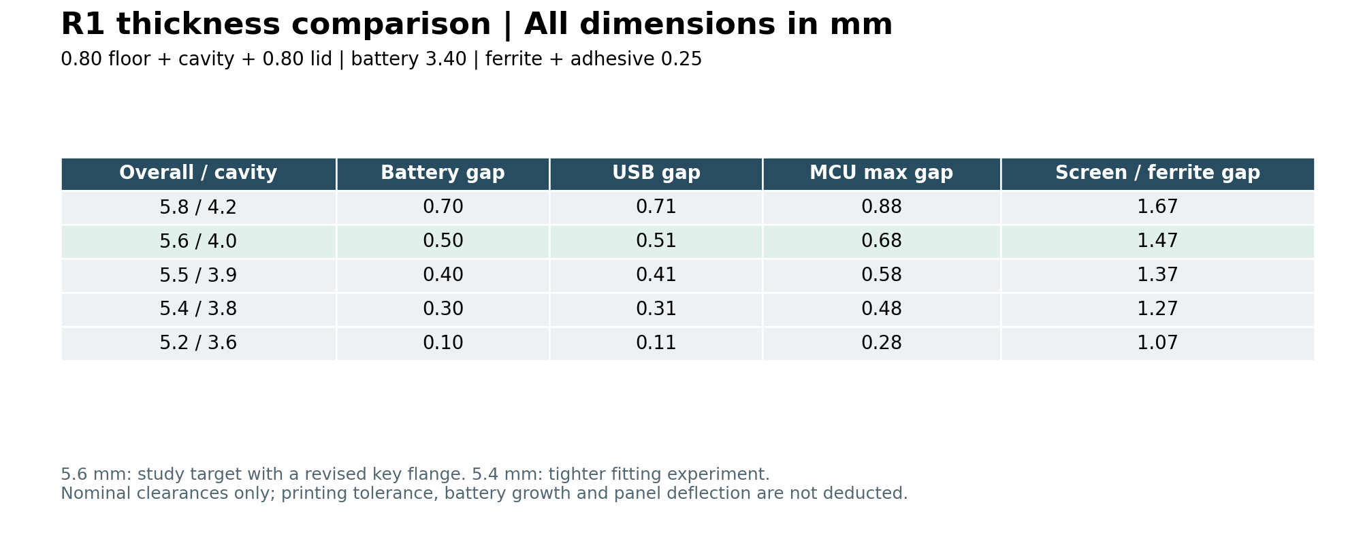
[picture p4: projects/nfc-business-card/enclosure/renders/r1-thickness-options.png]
Thickness options


At **5.6 mm**, nominal upper gaps are: battery **0.50**, USB **0.51**, MCU maximum **0.68**, FPC socket **0.87**, and ferrite-to-screen **1.47 mm**. At **5.4 mm**, these become **0.30 / 0.31 / 0.48 / 0.67 / 1.27 mm**.

Battery and USB alone suggest roughly 5.4 mm overall with a 0.3 mm nominal gap. That gap is a design allocation, not a supplier tolerance guarantee. At 5.2 mm only 0.10/0.11 mm remain above the battery/USB, and the proposed key already collides. A 5.0 mm enclosure has a 3.4 mm cavity, less than the battery-plus-adhesive stack even before clearance.

The screen has enough vertical space in every candidate. Its XY aperture registration stays unchanged; lowering the lid changes the flex bend, which still needs a fully inserted sample check. A hypothetical 1.0 mm solder/wire envelope above the PCB would leave 0.62 mm below the maximum screen at 5.4 mm if no ferrite covers that local envelope; this does not establish the wire diameter or actual solder height.

Reducing the PET support could recover some PCB/component height, but cannot reduce the battery's 3.50 mm requirement. Keep the existing support until rear solder protrusions, insulation and floor deflection are checked.

## Keys: a real constraint and a manufacturing item

There are two different parts:

1. **Electrical switches SW1/SW2/SW3:** purchased ALPS SKQGABE010 components, already in the PCB BOM; soldered during assembly.
2. **Visible keycaps:** three separate transparent printed parts, captured under the lid. They can be ordered with the shell; no separate stock keycap purchase is required. They cannot be fused to the rigid case if they are to move.

The old CAD check only moved the key 0.30 mm. The [ALPS specification, section 7.2](https://tech.alpsalpine.com/cms.media/SKQGAB_KQG_719_EN_cc4e10226e.pdf#page=3) gives travel **0.25 +0.20/-0.10 mm** under its test load. The study checks 0.45 mm plus the model's approximately 0.05 mm contact gap. This is a clearance envelope, not a command to force every switch through 0.45 mm. The moving actuator is excluded from the fixed-body collision check.

| Overall / flange | Clearance at the maximum travel envelope | Result |
| --- | --- | --- |
| 5.8 / 1.0 mm, existing geometry | 0.28 mm | Revised check of the existing design |
| **5.6 / 0.8 mm** | **0.28 mm** | Recovers 0.2 mm overall while retaining the current plunger length and motion space |
| 5.5 / 0.8 mm | 0.18 mm | More sensitive to printing and assembly variation |
| 5.4 / 0.8 mm | 0.08 mm | Static fit is insufficient evidence for release |
| 5.2 / 0.8 mm | -0.12 mm | Collision detected |
| 5.4 / 1.0 mm, unchanged flange | -0.12 mm | Simply lowering the existing lid fails the expanded motion check |

All three switches were checked using FreeCAD solid intersections. The failing cases intersect the fixed switch model by approximately 0.535 mm³ per key; passing rows have zero intersection. These are nominal geometry results, not tolerance or fatigue tests.

Keep the existing 0.6 mm nominal radial gap between the 4.0 mm head and 5.2 mm lid hole. The depicted 0.05 mm axial gap is not a controlled bearing: the cap floats and settles against the actuator. Plunger height, lack of resting preload and full return need actual fitting. The thinner flange also needs a strength/print check. Small keycaps may need a removable carrier for the printing supplier's handling/minimum-size rules; the carrier must avoid the plunger and sliding surfaces.

The user's resin sheet gives 0.8 mm wall and ±0.2 mm accuracy. Those values do not establish the flatness or accumulated tolerance of this assembly. [JLC's design guide](https://jlc3dp.com/help/article/3d-printing-design-guideline) increases recommended wall thickness with part size and lists minimum part sizes. The broad 0.8 mm shell panels and the separate small keys still need supplier review; this study retains the user's thickness choice rather than declaring it qualified.

## Battery pads: compare location before routing

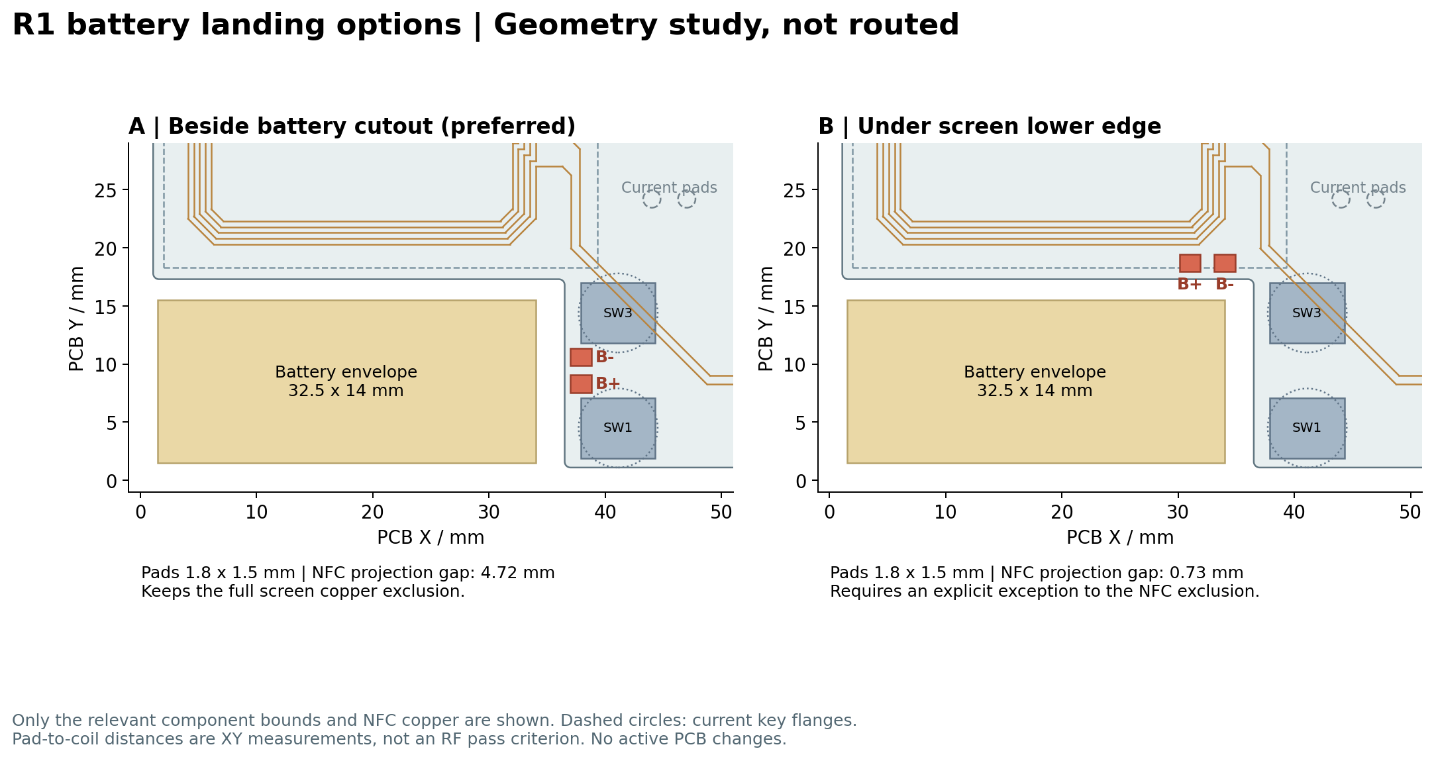
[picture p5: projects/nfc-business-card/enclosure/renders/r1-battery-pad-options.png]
Battery pad options


Both studies use **1.8 × 1.5 mm top-side solder landings**. Coordinates are in the PCB's native XY frame.

| Item | A: beside cutout, preferred | B: screen lower edge |
| --- | --- | --- |
| B+ / B− centers | (37.9, 8.3) / (37.9, 10.6) | (31.0, 18.7) / (34.0, 18.7) |
| Minimum copper-to-outline | 0.50 mm | 0.65 mm |
| Minimum XY distance to NFC copper | **4.72 mm** | **0.73 mm** |
| Nearest component model bounds | 0.45 mm to SW1/SW3 | No component within 2 mm |
| Top tracks within 0.2 mm of the proposed pads | None | None |
| Existing top pads or vias within 0.2 mm | None | None |
| Existing full-screen copper exclusion | Preserved | Requires two pad and route exceptions |

These distances are geometric comparisons, **not RF clearance thresholds**. At the time of this comparison neither option had been routed or passed native DRC; B has since been implemented as linked above. The side option also has a nominal 0.8 mm gap between solder lands and 0.424 mm XY clearance from the nearest key flange. Pad corners should be rounded in implementation, with solder-mask openings and clear polarity marks.

The assumed lead exit reference is (34, 8.5), still unmeasured. From there the preferred centers are only about 3.9–4.4 mm away in XY, before bends and soldering slack. This avoids the previous wire detour up to the pads at Y=24.2. Do not specify cut-to-length wires until the actual protection board/lead exit is known.

Implementation should move the BAT_PACK_TBD and GND landings, route power and return together through the right-hand electronics area, and retain the charger-local battery decoupling capacitor. Size trace widths for the actual peak current and voltage drop; the existing narrow battery route is not a requirement to preserve. Rebuild pours, check edge/mask clearance, route continuity and solder access, then update the wire service envelope and exports. Keep solder and strain relief clear of both moving key flanges. Do not restore a ground rim around the NFC coil. If a real battery temperature sensor is used, its NTC connection needs a separate lead plan; do not silently tie it to B−.

## Ferrite placement

Back-to-front stack: **phone → rear cover → rear coil → PCB → ferrite → screen**. Use a low-loss magnetic sheet specified for 13.56 MHz, not an arbitrary conductive metal foil. A [TDK NFC sheet example](https://product.tdk.com/en/search/noise_magnet-sheet/noise_magnet-sheet/charge-nfc-low/info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) has 0.20 mm magnetic material and 0.24 mm total thickness including adhesive, making the accepted 0.25 mm allocation plausible without selecting that part.

[NXP AN11564 sections 2.2 and 3.2](https://www.nxp.com/docs/en/application-note/AN11564.pdf) support placing ferrite between antenna and metal, covering the antenna, and measuring/tuning in the final stack. Only those physical principles are used here; PN7120-specific matching values do not apply to this nRF52840 design.

If a front PCB solder pad is below the sheet, it is on the same side of the ferrite as the rear coil. The sheet does not isolate those two PCB conductors from each other. Thus the screen-edge option still creates an antenna-neighbour change despite generous vertical space. The side location avoids that tradeoff. The final ferrite, display, battery and case must be included in NFC tuning; shielding is not proof of working read range.

## Reproduce and remaining work

From the repository root:

```sh
python3 projects/nfc-business-card/scripts/study-r1-packaging.py
```

This reads the saved FCStd through FreeCAD, computes the key motion cases, audits candidate pad geometry with Shapely, and renders the comparison images. It does not save the FCStd or write to EDA. The saved comparison is historical. Re-running against the current PCB replaces its baseline; current B-route verification is in the linked battery and PCB review records.

For the next mechanical revision: discuss the cap/flange process, update B-pad wire/solder and ferrite relief, and use the updated [PCB review](pcb-r1-review.md), which corrects the earlier C1/C8 assignment. Printing, battery growth allowance and final NFC tests remain physical validation tasks.

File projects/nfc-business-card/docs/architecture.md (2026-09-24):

---
description: NFC 身份切换、电源和固件架构决策
last_updated: 2026-09-21
---

# 架构选择

当前主控为 nRF52840，满足用户新增的 USB 编程要求；nRF52832 只作早期 NFC/薄度比较。下载与原型选项见 [USB 编程方案](usb-and-prototyping.md)。

2026-09-20 的具体器件、电源域、接口脚号和启动约束见 [系统设计草案](../hardware/system-design.md)；本文保留功能与固件行为讨论。正式原理图、固件和实物尚未完成。

## 1. 需要的是可编程标签端

手机/读卡器产生 13.56 MHz 磁场，名片在 NFC-A 标签端响应。电池供主控和墨水屏使用，按键选择后由固件更换 NDEF 数据。这个交互不要求名片产生读卡场；日常所说的“主动切换”与 NFC 协议里的主动通信模式不是一回事。

nRF52832 的 NFCT 支持 NFC-A listen、106 kbps 和外部场检测唤醒；Nordic SDK 提供 Type 2 标签库。其 Type 2 库的“只读”指手机一侧不能改写，主控固件仍可设置下一次提供的 NDEF。资料：[nRF52832 NFCT](https://docs.nordicsemi.com/r/bundle/ps_nrf52832/page/nfc.html)、[Nordic NFC 文档](https://nrfconnectdocs.nordicsemi.com/ncs/latest/nrf/protocols/nfc/index.html)。

```mermaid
flowchart LR
    Keys[至少两键，第三键可选] --> MCU[nRF52840]
    MCU -->|SPI| EPD[1.54 英寸墨水屏]
    MCU ---|NFC1 / NFC2 + 匹配网络| Coil[13.56 MHz 线圈]
    Coil <-.-> Reader[手机或兼容读卡器]
    USB[USB-C] -->|5 V| Charger[充电与电源路径]
    USB <-->|USB 数据 / 固件升级| MCU
    Battery[薄型单节锂电池] <--> Charger
    Charger --> Reg[3.3 V 稳压]
    Reg --> MCU
    Reg --> EPD
    SWD[首烧 / 救援 SWD 焊盘] --- MCU
```

BLE 天线和 NFC 线圈是两套不同结构。Raytac 模块附带的 PCB 天线服务于 2.4 GHz 无线，不会替代 NFC 线圈；V1 不启用 BLE 广播、Wi-Fi 或联网功能。

## 2. 对外内容与兼容性

默认每个身份提供一个 **NDEF HTTPS URI**。固件内保存 `profile_id / display_name / subtitle / https_url`，屏幕显示当前身份及可选二维码，二维码与 NFC 使用相同 URL。只有选中索引需要持久化，不需要存动态资料数据库。

- iPhone 支持背景读取的机型可显示链接通知，用户点击后打开；不能承诺贴近后无确认地自动打开。Apple 明确说明背景读取条件和 URI 记录要求：[官方说明](https://developer.apple.com/documentation/corenfc/adding-support-for-background-tag-reading)。
- Android 与具体读卡器做实物兼容测试。支持 ISO14443A 并不自动代表上层软件会解析 NDEF 或打开链接。
- HTTPS URL 可以先指向已有个人页面或社交主页，不需要为 V1 建后端。若最终需要名片页和 `.vcf` 下载，可单独开发；NFC 读取本身不需要名片联网，打开网页通常需要手机联网。
- 不以原始 vCard 作为唯一默认记录，避免把“读到字节”误当成“所有手机自动存入通讯录”。
- V1 不做任意 UID 切换、MIFARE/DESFire 门禁兼容或支付仿真。这些是不同的协议和认证需求。
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

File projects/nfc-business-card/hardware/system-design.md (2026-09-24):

# 电子名片系统设计草案

更新：2026-09-20。范围：功能框图、供电边界与原理图输入；已形成 [EDA 原理图草案](../archive/pre-r1/hardware/schematic-draft.md)，尚未完成制造设计或验证实物。对应 [候选 BOM](candidate-bom.md) 和[六色屏/302030 空间研究](../archive/pre-r1/enclosure/pcba-e6-302030.svg)。框图反映当前选样方向，EDA 的屏幕电路尚未迁移。

2026-09-21 按键需求更新：至少两颗分别轮换一级栏目、二级选项，二级选到即自动应用；第三颗在空间与装配允许时保留，功能待定。现有三颗开关及 GPIO/网络保留，逻辑角色与具体位号的映射待后续固件/原理图同步，详见[交互架构](../docs/architecture.md)。
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

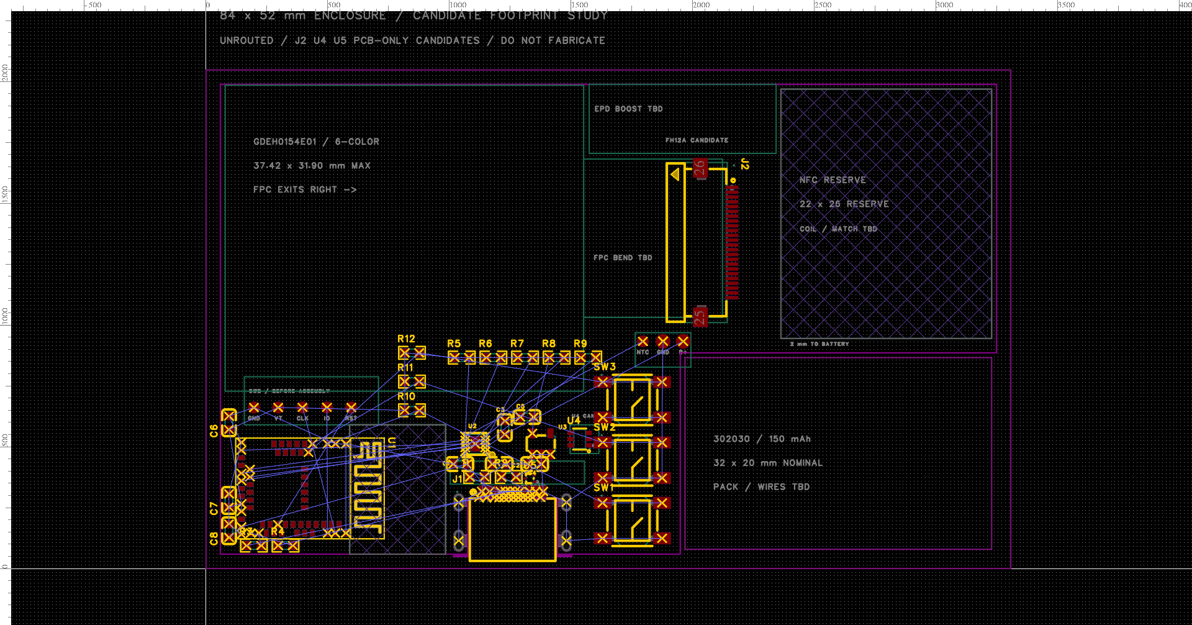
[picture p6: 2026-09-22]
projects/nfc-business-card/hardware/pcb-84x52.png

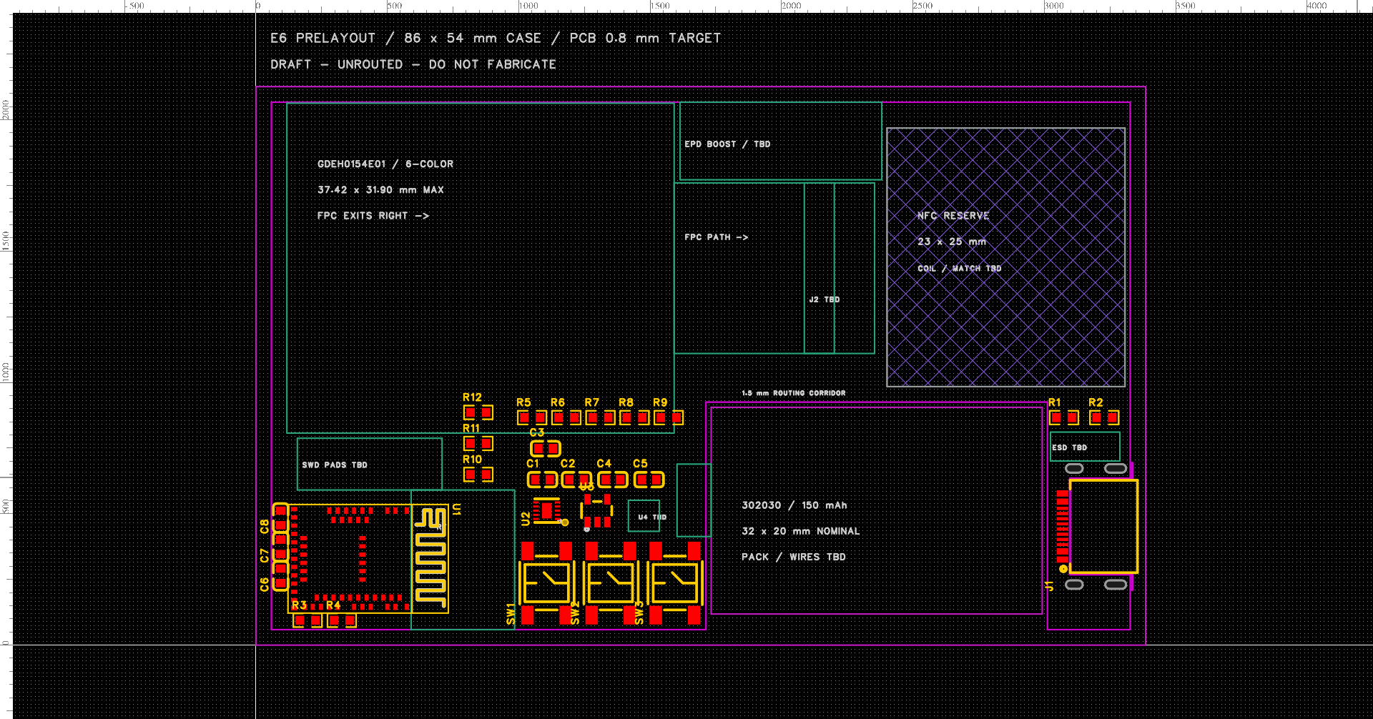
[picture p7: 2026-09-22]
projects/nfc-business-card/hardware/pcb-prelayout.png

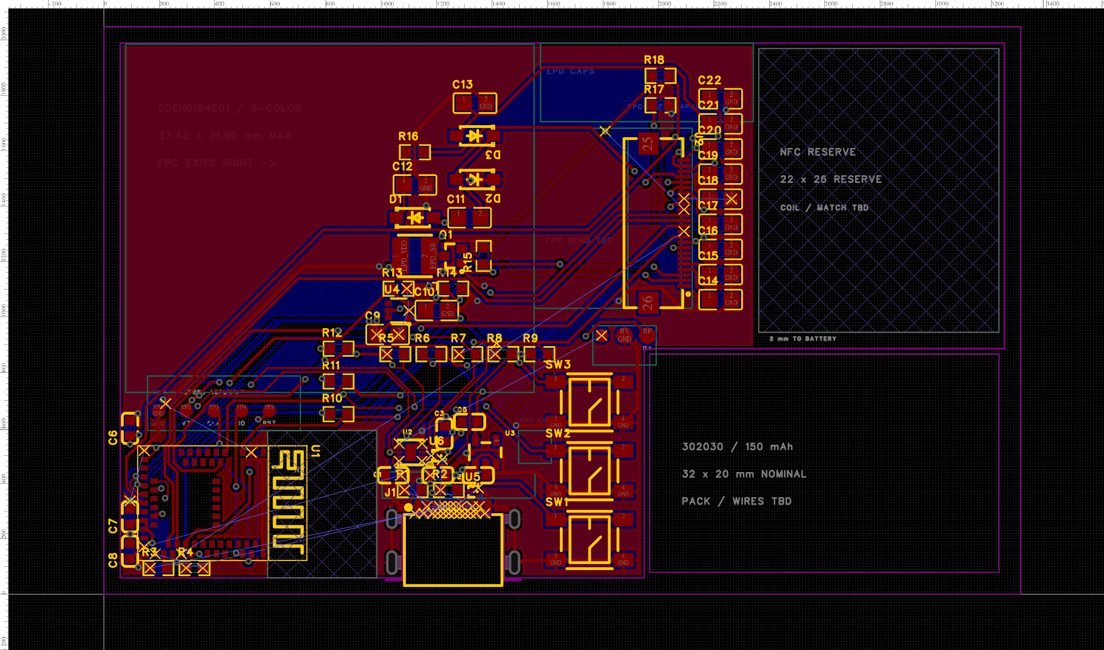
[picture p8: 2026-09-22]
projects/nfc-business-card/hardware/pcb-e6-84x52.png

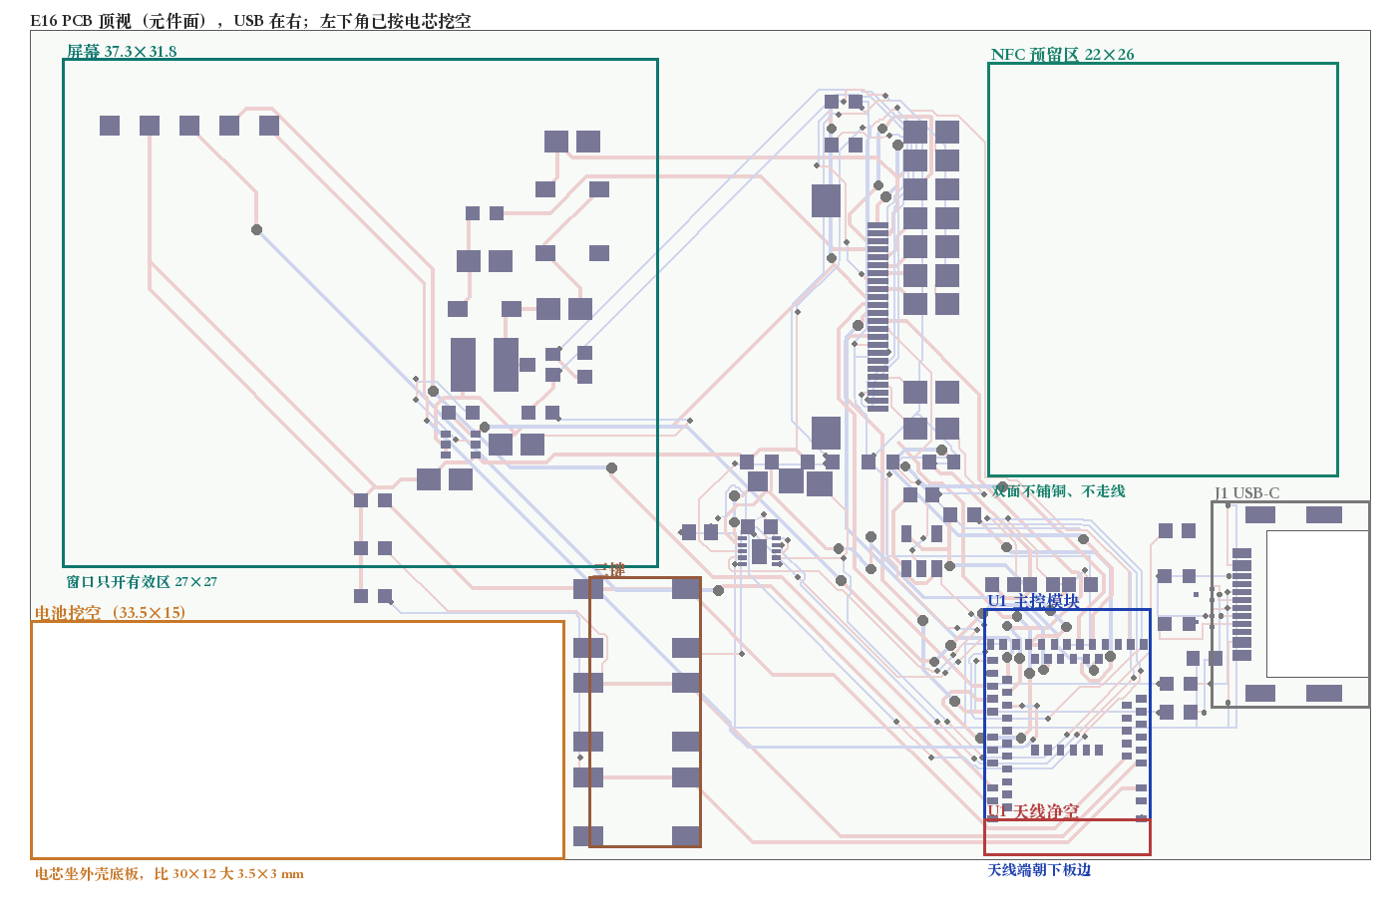
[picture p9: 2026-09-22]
projects/nfc-business-card/hardware/pcb-e16-regions-label.png

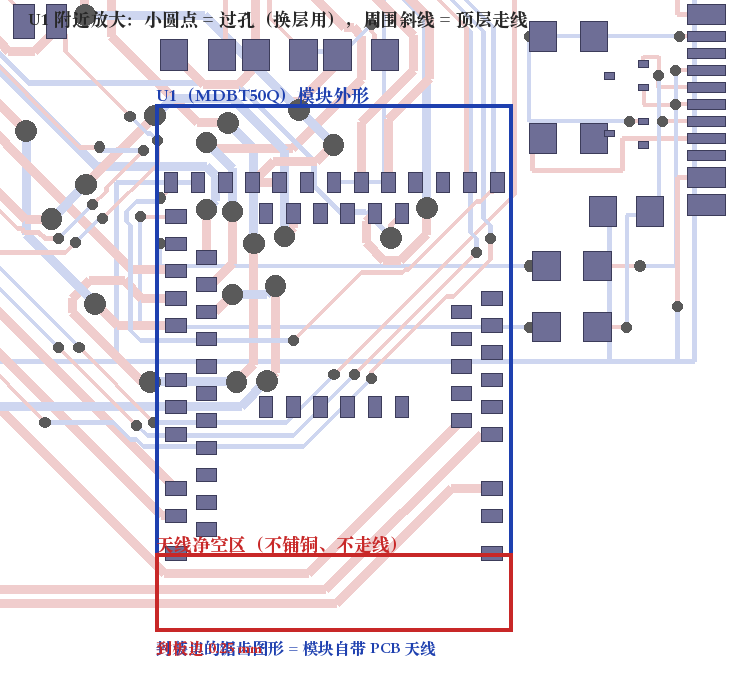
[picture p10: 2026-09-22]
projects/nfc-business-card/hardware/pcb-e16-u1-label.png

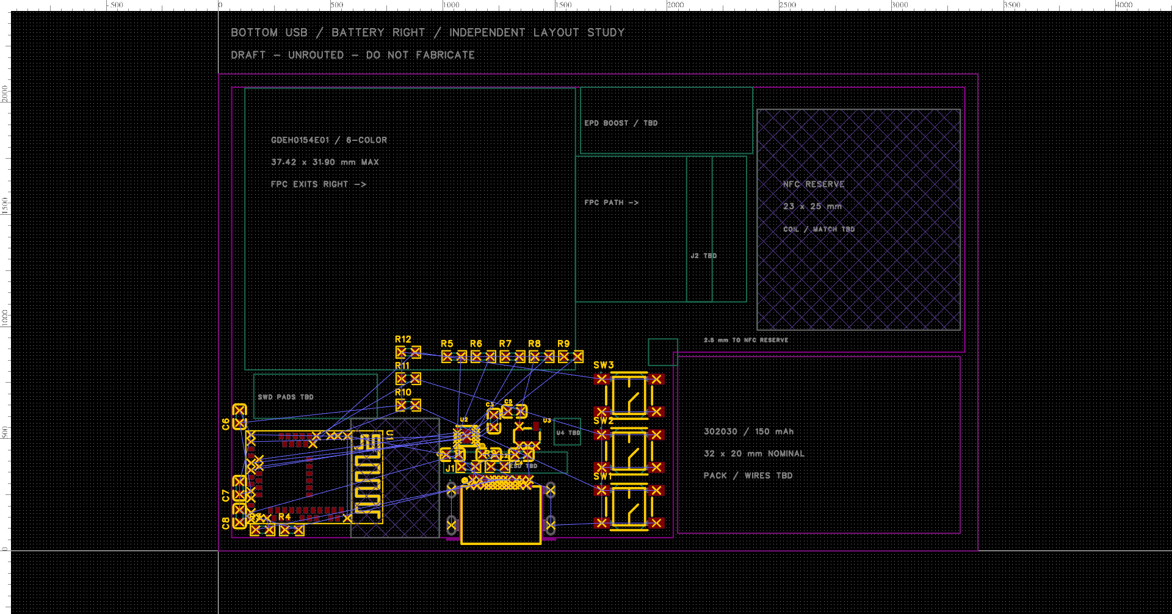
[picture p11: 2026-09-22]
projects/nfc-business-card/hardware/pcb-bottom-usb.png

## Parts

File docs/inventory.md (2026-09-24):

# 共享器件清单

本清单区分用户确认到货与实物验货结果，随收货和检查进展更新。具体装置的实际 BOM 和接线放在所属项目的 `hardware/` 或 `docs/` 目录。

| 物品 | 数量 | 已记录状态 | 备注 |
| --- | --- | --- | --- |
| FoloToy AI Passport | 未记录 | 2026-09-16 用户确认已下单，等待到货 | 到货后核对批次和配件 |
| PN532 NFC 模块 | 1 | 2026-09-23 用户确认到货，并提供正反面照片 | 蓝色 PCB 天线板，双排针已焊、另有带接口丝印的未焊孔位，带 SET0/SET1 模式开关；外观接近 ITEAD PN532 模块，具体版本、电源与双排针针序仍待核对；未通电或测试卡模拟 |
| GDEH0154E01 候选墨水屏屏体 | 1 | 2026-09-23 用户确认到货；未提供屏体丝印近照 | 用户粗量约 38 × 32 × 0.9 mm，未大力压尺；型号、FPC 朝向及实际包络待实物核对 |
| 墨水屏随附转接板 | 1 | 2026-09-23 用户确认随屏到货；未提供转接板近照 | 采购目标为 DESPI-E01；实际板卡型号、接口丝印与供电待核对；桌面测试用，不计入最终薄卡 |
| 302030 类锂聚合物电池 | 1 | 2026-09-23 用户确认到货 | 用户粗量约 3 × 20 × 32 mm；完整保护包、引线与最大厚度未核对；当前名片布局不能直接使用此尺寸 |
| 301230 类锂聚合物电池 | 1 | 2026-09-23 用户报告已购买；到货未确认 | 购物车目标约 3 × 12 × 30 mm，保护包完整外形和实际容量待到货核对 |
| 301423 类锂聚合物电池 | 1 | 2026-09-23 用户报告另买一只备用；到货未确认 | 购物车目标约 3 × 14 × 23–24 mm，型号与保护包完整外形待到货核对 |
| ESP32-S3-CAM / N16R8 / 1.54 寸屏幕套装 | 1 套 | 2026-09-16 用户确认到货；2026-09-18 提供实物总览和装箱单照片 | 已按照片初步核对类别，详细型号、数量与功能仍待逐项验货 |
| 额外按键、传感器、杜邦线、LED 和电阻 | 见下方发货清单 | 2026-09-18 提供实物总览和发货清单照片 | 作为共享实验配件；一块五向按键的 MID 已验证，其他模块未通电验收 |

## 2026-09-18 到货照片核对

依据用户提供的两张照片：收纳盒内实物总览、套装装箱单与额外配件发货单。下表数量与型号来自纸质清单，不能替代逐件实物核验；不保存照片中的个人收件信息。

### 基础套装

| 清单标注 | 清单数量 | 照片核对情况 |
| --- | --- | --- |
| ESP32-S3-N16R8 CAM 开发板 | 1 | 近照可辨 N16R8；实测 ESP32-S3 v0.2、16 MB Flash，USB-UART 与原生 USB 均可通信；应用初始化报告 8 MB PSRAM，并成功使用帧缓冲拍照 |
| OV3660 摄像头 | 1 | 2026-09-19 驱动读取 PID `0x3660`，320×240 JPEG 拍照及第三个程序约 20 FPS 小图预览已验证；更高分辨率未测试 |
| 1.54 寸彩屏 | 1 | 用户已确认八针标注并按表接好；ST7789 测试固件烧录及 USB 回复通过，用户目视确认基本显示成功；背面 PCB 版本未独立核对 |
| 400 孔面包板 | 2 | 可见两块白色面包板 |
| Type-C 数据线 | 1 | 可见白色线材，接口和数据传输能力待核对 |
| INMP441 麦克风模块 | 1 | 小模块需取出后逐个核对丝印 |
| MAX98357 音频模块 | 1 | 小模块需取出后逐个核对丝印 |
| 3 W 喇叭 | 1 | 可见黑色喇叭，额定参数按清单记录 |
| 140 根盒装跳线 | 1 盒 | 可见盒装跳线，未清点根数 |
| 收纳盒 | 1 | 可见收纳盒；此数量为套装清单数量 |

### 额外实验配件

| 清单标注 | 清单数量 | 照片核对情况 |
| --- | --- | --- |
| 黑黄色旋钮帽（WH148 电位器／编码器用） | 1 | 可见黑黄色旋钮帽；此条目是旋钮帽，不额外计作电位器模块 |
| 20 cm 杜邦线：公公、公母、母母 | 各 2 包，每包 10 根，共 60 根 | 可见多组彩色杜邦线，端点组合和根数未逐组核对 |
| 一路触摸传感器，点动型 | 1 | 可见带同心圆图案的蓝色触摸板，具体芯片待确认 |
| SHT30 传感器模块，蓝板焊好 | 1 | 发货单明确写 SHT30，模块丝印仍需近照确认 |
| 五向导航按键模块 | 2 | 一块已连接 COM 共地、MID 接 GPIO14；2026-09-19 中心键计数、持续连按响应和相机定格已由用户确认；其他按键脚及另一块模块未测试 |
| 360 度旋转编码器模块，五针 | 1 | 可见带金属转轴的模块，具体型号待确认 |
| 1/4 W 金属膜电阻，41 种各 20 只 | 1 盒，共 820 只 | 可见对应标签的电阻盒，未逐个计数或测量 |
| GY-302 光照传感器模块 | 1 | 小模块需取出后逐个核对丝印 |
| LED，3 mm 与 5 mm 各 3 种 | 1 盒，共 60 只 | 可见多色 LED，未清点和测试 |
| ST034 彩色按键，八位 | 1 | 可见标注 K1～K8 的八键板 |

此前讨论倾向 SHT30，但购物截图显示 DHT11；本次发货单明确列出 **SHT30**，未列出 DHT11。发货清单层面的型号已有依据，实物仍待近照或读取验证，不能仅凭板色确认型号。

开发板的 USB 识别、Flash 备份、固件写入和摄像头取帧已验证，详见 [Image Oracle 启动记录](../projects/image-oracle/docs/camera-bringup.md)。当前运行[第三个整合程序](../projects/image-oracle/docs/oracle-bringup.md)，用户确认实时预览、MID 定格、答案显示、画面方向和颜色正常；其他配件的照片初查不代表通电验收。

## 采购参考

- [AI Passport 购买与后续计划](../../CyberMnema/timeline/2026/09/W38/AI_Passport.20260916.md)
- [Image Oracle 讨论与配件清单](../../CyberMnema/timeline/2026/09/W38/熔岩灯交互装置.20260914.md)

确认实际拥有的工具后，再补充工具清单和收纳位置。

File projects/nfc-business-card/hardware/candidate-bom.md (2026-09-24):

# PCBA 候选 BOM

## 当前确定方案

2026-09-21：[E6 电路工程](../archive/pre-r1/hardware/pcb-e6-84x52.md)已选用 56 个电路元件并加入原理图/PCB，具体 J2、升压、供电开关、ESD 和电容料号以该记录及[网表](../archive/pre-r1/hardware/e6-circuit.enet)为准。仍是可调整的工程选型，不是采购或生产 BOM；样品与功耗验证未完成。以下保留之前候选比较，其“未加入 EDA”等描述属于当时状态。

更新：2026-09-20。用于系统与空间设计，**不是采购或制造 BOM**：分组数量不是完整位号清单；被动件数量、耐压、温漂、封装及贴片可得性须在原理图阶段补齐。数量均按一块板或一套整机估计。

用户当前取样选择：GDEH0154E01 六色屏 + DESPI-E01 转接板 1 套、302030 / 150 mAh 电池 1 只。尚未确认购买或到货；已生成独立[样品排布](../archive/pre-r1/enclosure/pcba-e6-302030.svg)，EDA 仍为先前黑白屏草案。以下更新选型方向，不代表已经完成电路迁移；黑白 GDEY0154D67 保留作备选。

## 关键器件

| 功能 / 数量 | 候选料号 | 机械与电气依据 | 采用前缺口 |
| --- | --- | --- | --- |
| 主控 / 1 | **MDBT50Q-P1MV2** | nRF52840；15.5 × 10.5 × 2.0 mm，模块图纸高度上界 2.2 mm；NFC/USB 引脚已核对 | 主控供货；EDA 符号和封装；首次 SWD 与 USB bootloader |
| 屏幕 / 1，后装 | **GDEH0154E01** 取样选择 | 240 × 240 六色；屏体上界 37.42 × 31.9 × 1.0 mm；FPC 尾部还需空间 | 刷新体验、峰值功耗、BUSY 极性、对应版本驱动与 FPC 方向；[专项评估](../docs/gdeh0154e01-evaluation.md) |
| 电池 / 1，后装 | **大佳满益 302030 / 150 mAh** 取样选择 | 商家标称 32 × 20 × 3 mm，3.7 V / 满充 4.2 V，带保护板两线；新模型已移到右下缺口 | 最大完整包体、NTC、充放电规格及新排布实测；2.5 mm PCB 窄桥待验证，不能按标称尺寸冻结 |
| 充电 / 1 | **BQ25186DLHR** | WSON-10，2.2 × 2.0 mm，最高 0.8 mm；I2C 电源路径 | 复位默认值、NTC、输入限流、热焊盘和小电池终止条件 |
| 稳压 / 1 | **TPS7A0233DBVR** | 3.3 V / 200 mA；SOT-23-5 最高 1.45 mm | 升压启动峰值、压差、有效电容与反向供电 |
| 屏幕开关 / 1 | **TPS22919DCKT** | SC70-6；1.6–5.5 V 输入；逻辑控制 | 封装库与供货尚未核对；GPIO 断电顺序；不是屏幕高压开关 |
| USB / 1 | **USB4500-03-0-A** | GCT 16 接点 USB 2.0 数据座；沉板 0.8 mm，主体高 3.16 mm、深 6.5 mm、含侧翼宽 11.24 mm | 板边槽、锚脚/焊料下凸、插头外壳避让、壳体承力；不能按“沉板 0.8”误认为高度 0.8 mm |
| FPC 座 / 1 | **六色屏需重选**；旧候选 FH12-24S-0.5SH(55) 暂停沿用 | DESPI-E01 指定 24 pin / 0.5 mm 上接触或双面接触；旧候选为底接触 | 结合屏幕触点朝向、pin 1、排线厚度、完整焊盘和翻盖空间重选；不能仅按针数替换 |
| 交互按键 / 至少 2，第三颗可选（当前排布 3） | **SKQGABE010** | 名义主体 5.2 × 5.2 × 1.5 mm | 键帽与行程、未按下最高点、焊盘；模型另画按键操作区 |
| NFC / 1 组 | PCB 线圈 + C0G 调谐电容 | 先分配无金属覆盖区域；数值待测 | 匝数/电感/匹配均未定，不能把空间框当成合格天线 |
| 首烧救援 / 5 点 | SWDIO / SWDCLK / RESET / GND / VTref | 测试焊盘，使用外部探针 | 探针夹具、装壳后的可达性；不装凸起排针 |

器件事实来源：[Raytac](https://www.raytac.com/product/ins.php?index_id=47)、[Good Display](https://www.good-display.com/product/388.html)、[PowerStream 电池目录](https://www.powerstream.com/thin-lithium-ion.htm)、[BQ25186](https://www.ti.com/product/BQ25186)、[TPS7A02](https://www.ti.com/product/TPS7A02)、[TPS22919](https://www.ti.com/product/TPS22919/part-details/TPS22919DCKT)、[GCT USB4500](https://gct.co/connector/usb4500)、[Hirose FH12](https://www.hirose.com/product/p/CL0586-0521-0-55)。本地原厂图纸及校验值见 [下载清单](../docs/download_manifest.json)。

2026-09-20 采购核对：当前屏幕套餐及电池选项来自用户购物车截图，价格不作为实时库存或结算保证；DESPI-E01 只作测试工具，不计入最终成品 BOM。早期 GM201030 的带 PCM 旧规格书给出最大厚度 4 mm，已取消主选；LP201230 保留作询样备选。采购链接、规格差异及待确认问题见[器件选项](component-options.md)。

## 2026-09-21 紧凑排布候选

[84 × 52 独立工程](../archive/pre-r1/hardware/pcb-84x52.md)新增实际库封装：J2 **FH12A-24S-0.5SH(55) / C506794**、U4 **TPS22919DCKT / C2860814**、U5 **TPD2EUSB30DRTR / C97502**。三者均只是 PCB 空间候选，未连入原理图，排除 BOM；未查询实时库存或锁定 SMT 供货。

J2 为上接触，本体上界 6.4 × 16.7 × 2.2 mm；屏幕触点长与插座推荐值有差异，库锚脚也不同于原厂推荐，需确认或换座。U5 只用于评估 USB 数据 ESD，VBUS/CC 尚未完成。SWD 和电池/NTC 已放入平面焊盘，传感器、引线和电路验证仍待完成。[Hirose 产品](https://www.hirose.com/en/product/p/CL0586-0555-2-55)、[TI TPD2EUSB30 数据手册](https://www.ti.com/lit/ds/symlink/tpd2eusb30.pdf)。

同日屏幕资料复核新增 **XUNPU FPC-05FB-24PH20 / C2856831**：与官方 DESPI-E01 电路图标注同型号，24 pin / 0.5 mm 双面接触，闭合高度 2.00 ±0.10 mm。实际库封装通过 79 项名义尺寸比较，FPC 配合与制造层仍待审核；尚未取代 EDA/CAD 内的 FH12A。[尺寸、公差和外围清单](../docs/gdeh0154e01-evaluation.md#接口与参考电路复核2026-09-21)。参考板图面另有 25 个外围器件（不含 FPC 与桌面排针），其中存在版本/DNP 待确认项，不能据此生成正式采购数量。

## 必要外围与待选器件

| 分组 | 当前设计输入 | 下一步核对 |
| --- | --- | --- |
| USB CC 电阻 | 5.1 kΩ、1%，2 颗，CC1/CC2 各一颗 | 封装/料号、布局及受电声明 |
| USB 数据串阻 | Raytac 正常电压参考图各 27 Ω，2 颗 | Nordic 与模块参考版本、信号完整性；不重复叠加串阻 |
| USB 保护 | D+/D− 低电容 ESD；VBUS/CC 保护方案待选 | 钳位电压、容值、漏电、回流路径与实际 USB 连接要求 |
| I2C 上拉 | EDA 草案按 BQ25186 引脚说明改为 10 kΩ，2 颗，拉到主 3.3 V | 总线电容与速率、掉电引脚电平、最终阻值；[位号与库料号](../archive/pre-r1/hardware/schematic-draft.md) |
| 屏幕升压 | 旧黑白屏参考：47 µH / 500 mA 电感、Si1308EDL MOSFET、MBR0530 二极管 ×3 | **迁移六色屏时按其规格及 DESPI-E01 逐项重审，尚不锁料**；屏幕电流、线圈饱和/厚度、MOS 栅压条件 |
| 屏幕阻容 | 旧黑白图含 2.2 Ω、1 MΩ，以及 1 µF/4.7 µF、25 V 等电容 | 按六色屏交付版本及实测逐个定数量与料号；考虑直流偏压导致有效电容下降 |
| 主控/电源去耦 | 模块、充电器、LDO 与负载开关按各自原厂参考配置 | 靠近引脚、启动瞬态、额定耐压与低电压可用性 |
| 电池 NTC | 热敏电阻及热接触方案待电池资料确认 | 阻值/B 值/保护温区；禁止用固定电阻假装有电池温度反馈 |
| 电池测量 | 可断开的分压 / 测试点，暂不锁电阻值 | ADC 输入范围、漏电与测量精度；不增加永久低阻负载 |
| NFC 匹配 | 保留两路匹配焊盘，初始值待线圈设计 | 装入屏幕/电池/外壳后调谐与手机覆盖测试 |

因此电阻在这块板上会用于 USB 识别、信号串联、总线上拉、屏幕升压和电压测量；开发板常已装好这些外围，所以面包板实验时不一定需要自己加。

## 供货快照与 PCBA 边界

以下是 **2026-09-20 读取的 LCSC 国际站网页显示值**，未锁库存，不等于嘉立创国内 SMT 可直接调用的料库；也未查询贴片等级、损耗和装配费。价格不在本轮冻结。

| 器件 | 立创编号 / 来源 | 网页显示 | 项目判断 |
| --- | --- | --- | --- |
| MDBT50Q-P1MV2 | [C5119772](https://www.lcsc.com/product-detail/C5119772.html) | 缺货 | 供货阻塞，先确认补货/来料或评审替代 |
| BQ25186DLHR | [C44639442](https://www.lcsc.com/product-detail/C44639442.html) | 67 | 仅少量记录，正式下单前复查 |
| TPS7A0233DBVR | [C5142805](https://www.lcsc.com/product-detail/C5142805.html) | 5,237 | 有网页库存记录 |
| USB4500-03-0-A | [C5354966](https://www.lcsc.com/product-detail/C5354966.html) | 32 | 数量较少；原厂图与商城“24P”标签不同，按原厂 16 接点图核对封装 |
| FH12-24S-0.5SH(55) | [C202112](https://www.lcsc.com/product-detail/C202112.html) | 12,292 | 有网页库存记录，接触方向仍待屏幕核对 |
| SKQGABE010 | [C115351](https://www.lcsc.com/product-detail/C115351.html) | 47,325；最小/步进 5 颗 | 3 块板需 9 颗，裸料采购时需按包装规则计算 |

PCB/PCBA 暂按 0.8 mm 板、单面主要器件进行设计研究；具体通道、拼板/工艺边、沉板 USB 装配以及模块来料要由国内制造服务确认。屏幕、电池、键帽和壳体按收到 PCBA 后装配规划。首批 3 块板仍是数量候选，未下单。

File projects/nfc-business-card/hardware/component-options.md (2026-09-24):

---
description: 元件候选、尺寸证据、替代路线与未冻结的采购条件
last_updated: 2026-09-20
---

# 器件与现成方案选项

以下为候选比较，不是可下单 BOM。尺寸来自原厂图纸时注明页码；供应商目录、设计目标和实测结果分别标记。当前没有本项目实物测量或正式报价。2026-09-20 成品路线已转为薄模块加定制 PCBA，已读取部分器件网页库存；最新分组料单、供货快照及缺口见 [候选 BOM](candidate-bom.md)，接口边界见 [系统设计](system-design.md)。

## 成品小板新候选：截图中的 nice!nano v2.0SMT

2026-09-18 用户提供「深圳市大熊智能」淘宝商品截图，当前选项显示 nRF52840 nice!nano、不焊接排针。以下仅转录商家标称，不等于原厂认证、到货或测量：

| 项目 | 截图标称 | 选型判断 |
| --- | --- | --- |
| 尺寸 | 34.1 × 18.0 × 3.2 mm | 平面较 XIAO 长；需确认 3.2 mm 是否包含 USB 座和背面全部器件，以及高度公差 |
| 存储 | 1 MB Flash / 256 KB RAM | 与 nRF52840 芯片规格相符，不能由截图证明板上实际芯片/固件状态 |
| 接口/供电 | 21 路 GPIO、3.3 V、4.2 V 锂电池充电管理 | 需要对应板型的引脚图、原理图和默认充电电流；充电管理不自动等于完整电池保护 |
| 待机 | 深度睡眠约 20 µA | 是商家条件未明的标称，不用于推算本项目整机续航 |

它是以 nRF52840 为核心的开发板，不能把板型名与芯片名混用。nRF52840 具备 Cortex-M4 64 MHz、BLE、NFC-A 和 USB；与常见 Wi-Fi MCU 如 ESP32-S3 相比，本项目选择它的直接理由是可编程 NFC 标签能力与电池设备适配性，项目不需要 Wi-Fi。不能据此断言所有 nRF 板都比所有 ESP32 板省电。来源：[Nordic 产品页](https://www.nordicsemi.com/Products/nRF52840)、[ESP32-S3 官方概览](https://docs.espressif.com/projects/esp-hardware-design-guidelines/en/latest/esp32s3/product-overview.html)。

最先核实该款的 NFC 引出：芯片的 **P0.09 / NFC1、P0.10 / NFC2** 是否都接到可焊焊盘、有没有连接其他负载，以及固件/bootloader 是否将其配置为 GPIO。芯片引脚功能来自 [Nordic pin assignments](https://docs.nordicsemi.com/r/bundle/ps_nrf52840/page/pin.html)，不是本商品已确认的板级引脚表。[原版 nice!nano 引脚/原理图入口](https://nicekeyboards.com/docs/nice-nano/pinout-schematic/) 只能作为比较资料，不能替代该商家的具体板卡版本图。外接 NFC 线圈和匹配网络仍需验证。

若实物完整高度确为 3.2 mm，则 0.8 + 3.2 + 0.8 = 4.8 mm，离 5 mm 剩 0.2 mm，尚未计入焊线、固定、绝缘、壳体偏差和涂层。相比此前定制板的 3.2 mm 预算，这里的 3.2 mm 是独立的商家整板标称，两者证据不同。USB 数据下载/恢复方式、可焊 NFC 引脚和完整高度确认后，才决定是否选它；当前不下单。

## 主控模块（当前定制路线）

| 候选 | 资料规格 | 工程判断 |
| --- | --- | --- |
| Raytac MDBT42V-P512KV2 | nRF52832；8.4 × 6.4 × 1.50 mm；图纸尺寸公差 −0.15/+0.20 mm | 早期薄度备选；无原生 USB，不再主选；高度预算 **1.70 mm** |
| Raytac MDBT42V-512KV2 | 同系列陶瓷天线版，标称高 1.75 mm | 不为 V1 关闭的 BLE 功能支付额外厚度 |
| **Raytac MDBT50Q-P1MV2** | nRF52840；15.5 × 10.5 × 2.00 mm；图纸公差 −0.15/+0.20 mm | 原生 USB 主路线的已核对候选；高度预算 **2.20 mm**，料号尚未冻结 |
| 裸 nRF52 | 芯片封装、去耦、晶振、DCDC 与布局需整套设计 | 暂不冻结型号；只在模块方案无法满足厚度时深入 |

来源：[MDBT42V Rev L](https://www.raytac.com/upload/download_files/03056be9fb6b807f9344a27b3bbc0e02.pdf) 第 7、13 页；[MDBT50Q Rev L](https://www.raytac.com/tw/download/index.php?index_id=24) 第 8 页。两个机械图已渲染核对，不能把“模块高度”当成焊到另一块 PCB 后的总高度。

MDBT42V-P512KV2 的原厂 pin assignment 明确引出 NFC1（模块 pin 11 / P0.09）、NFC2（pin 13 / P0.10）。这里只记录原厂事实，不是本项目最终引脚分配。模块仍须按参考电路配置电源与外围；不能因为是模块就省去所有 DCDC 外围。BLE 天线净空照模块说明处理，NFC 另配线圈与调谐电容。不要误买 AT 固件变体或没有 NFC 的其他 nRF52 型号。

## 墨水屏

| 候选 | 规格与尺寸 | 建议 |
| --- | --- | --- |
| **Good Display GDEH0154E01** | 1.54 英寸，240 × 240，六色；屏体 31.8 ±0.1 × 37.32 ±0.1 × 0.85 ±0.15 mm | 用户当前取样选择，配 DESPI-E01；刷新、峰值功耗及接口待验证，见[专项评估](../docs/gdeh0154e01-evaluation.md) |
| Good Display GDEY0154D67 | 1.54 英寸，200 × 200，SSD1681；玻璃 31.80 ±0.20 × 37.32 ±0.20 × 1.00 ±0.10 mm；有效区 27 × 27 mm；24 pin / 0.5 mm FPC | 保留为黑白备选及现有原理图的旧设计输入 |
| **Good Display GDEH0154E01** | 1.54 英寸，240 × 240、六色；屏体 31.8 ±0.1 × 37.32 ±0.1 × 0.85 ±0.15 mm | 用户关注的彩色候选；原厂资料和示例已取得，刷新时间/局刷/峰值功耗仍缺，见[专项核对](../docs/gdeh0154e01-evaluation.md) |
| GDEY0213B74 | 2.13 英寸，250 × 122，SSD1680Z；59.2 × 29.2 × 1.0 mm 标称 | 长条文字更舒展，但占用更长边，留给电池和线圈的空间减少 |
| GDEW0102T4 | 1.02 英寸，厂商页面列为停产 | 不用于新设计 |
| GDEW0102I4FC | 1.02 英寸柔性屏，厂商给出约 0.3 mm 薄结构 | ACF 连接等装配条件增加难度，暂不优先 |

来源：[1.54 英寸产品页](https://www.good-display.com/product/388.html)、[1.54 英寸原厂图纸镜像](https://static-cdn.m5stack.com/resource/docs/products/core/AirQ/GDEY0154D67%281%29.pdf) 第 7 页、[2.13 英寸](https://www.good-display.com/product/391.html)、[1.02 英寸停产屏](https://www.good-display.com/product/207.html)、[柔性屏](https://www.good-display.com/product/341.html)。

**玻璃轮廓没有包括展开的 FPC。** 1.54 英寸图纸有约 14.30 ±0.30 mm 的尾部延伸尺寸、0.30 ±0.05 mm 接触区厚度；最终还须安排弯曲半径、连接器与装配插入空间。示意图用尾部预留区表达，没有把它当成已完成折弯设计。

成品方案采用裸屏，将驱动外围集成进定制 PCB；成品驱动/转接板保留作桌面验证。COG 驱动器不代表整套电源已集成，仍需核对升压外围、VCOM、去耦、FPC 接触方向和连接器高度。黑白候选的旧版图纸部分高压引脚标签存在不一致，新版规格尚未取得，暂不冻结其网表。当前改为优先取样六色屏，不带触摸和前光；六色屏暂按整屏更新评估，不能沿用黑白候选的局刷能力。

2026-09-20 早期采购核对：曾建议 **GDEY0154D67 黑白裸屏**，现保留为备选。[佳显中文官网](https://www.good-display.cn/product/380.html)的“购买链接”指向[淘宝商品 617537932644](https://item.taobao.com/item.htm?id=617537932644)。已通过浏览器核实官网链接；淘宝商品访问被站点安全策略拦截，未核实当前选项、价格或库存。官网另列[中文规格书入口](https://www.good-display.cn/companyfile/582.html)，标为 2024-10-18 更新，尚未读取新版正文。采购时须确认交付型号和对应规格版本；裸屏不能直接接开发板 GPIO，桌面验证仍需匹配的驱动外围/转接板。

同日用户在[硬件 配件购买](codex://threads/01a0be87-5f3b-7b23-8fdc-68312f9cc88e)决定取样 **GDEH0154E01 六色屏 + DESPI-E01 转接板** 1 套，并在本任务提供购物车截图：套餐优惠价 ¥63.3，302030 / 150 mAh 电池 1 只为 ¥7.6，截图商品金额合计 ¥70.9，未核实运费或最终结算。状态为选定样品，尚未确认付款、到货或实测。转接板用于桌面验证，成品 PCB 再集成经验证的必要外围。

## 操作件

| 方案 | 候选 | 取舍 |
| --- | --- | --- |
| **三个独立按钮** | ALPS SKQGABE010，厂商现行目录标称 5.2 × 5.2 × 1.5 mm、1.57 N | 推荐；前/后/确认容易布置，单独键帽容易调整 |
| 五向按键 | E-Switch JS1300AQ，主体约 9.8 mm 方形、标称总高 1.55 mm | 可选；需要专门的十字键帽与限位，焊盘轮廓比主体大 |

来源：[ALPS SKQG 现行目录](https://tech.alpsalpine.com/c/products/category/tact-switch/sub/02/series/skqg/)、[JS1300 原厂 PDF](https://www.e-switch.com/wp-content/uploads/2022/06/JS1300.pdf)。JS1300 图纸已目视核对；是五组常开触点，不能套用随意找到的六脚摇杆封装。当前 SKQG 候选是 1.5 mm 版本，不照搬其他旧型号的 0.8 mm 数字。

预算包含焊接、按键行程、键帽和壳体突出量。采用凹入或齐平按键，增加防误触设计；不把硬质薄树脂直接当作寿命已验证的弹性铰链。正式 CAD 前取得候选的完整公差/焊盘资料并确认样品供应。

## 电池：先拿完整包体图，再冻结

用户当前取样选择为下文的 **302030 / 150 mAh**，需要重新排布，完整尺寸及允许充放电电流仍待确认。早期 40–60 mAh 窄条路线保留为备选；**FPbattery / DNK LP201230 60 mAh** 的小量供货仍未确认。以下保留早期 [PowerStream 薄电池目录](https://www.powerstream.com/thin-lithium-ion.htm)对照，是**供应商目录值，非已确认的成品包最大尺寸**：

| 目录型号 | 容量 | 列示 T × W × L | 用途判断 |
| --- | --- | --- | --- |
| GM201030-PCB | 43 mAh | 2 × 10 × 30 mm | 取消主选：同系列带 PCM 旧规格书给出最大厚度 4 mm，不能按目录的 2 mm 装壳 |
| PGEB021235-PCB | 40 mAh | 2 × 12 × 35 mm | 可替代，较宽长 |
| GM171538-PCB | 53 mAh | 1.7 × 15 × 38 mm | 标称更薄，平面占地更大 |
| GM251341-PCB | 95 mAh | 2.5 × 13 × 41 mm | 容量优先的备选，厚度与保护板余量更紧 |

同一目录有裸电芯 2 mm、带保护后标为 3 mm 的型号，也有保护板使局部明显加厚的说明。因此不能根据 `201030` 这样的名称判定装壳尺寸。[EEMB 编码说明](https://www.eemb.com/faq-6) 也说明型号主要描述电芯尺寸及容差，不能代替完整包体交付图。

新增证据与候选：

- **GM201030 暂不采购。** PowerStream 托管的[惠州基安比 201030/43 mAh 带 PCM 规格书](https://www.powerstream.com/lip/201030-%2043mAh%20_3.7V%20with%20PCM_A0.pdf)为 2013-12-03 A0 版，第 6 页写明装配最大 **33 × 10.5 × 4 mm**，不包括引线，厚度包括胶带及保护板。这与目录的 2 mm 不一致；不能证明当前交付版本相同，也不能再把它当作已满足薄度的候选。
- **LP201230 60 mAh 仅作询样候选。** [FPbattery 产品页](https://www.fpbattery.com/product/3-7v-60mah-lipo-battery-lp201230/)及其[初版规格书](https://www.fpbattery.com/wp-content/uploads/2023/10/201230-3.7V-60mAh-Specification.pdf)列 3.7 V、4.2 V 充电终止、32 × 12 × 2 mm 包体及 PCM；规格书推荐充电 0.2C（12 mA）、上限 0.5C（30 mA）、连续放电上限 1C（60 mA）。这些是供应商标注，未经实测或量产版本确认，不直接用于设置充电器。
- **资料一致性和小量供应仍是门槛。** FPbattery 同站目录另写 201230 为 80 mAh，产品页与初版 PDF 的部分 PCM 参数也不一致；采购必须指定 60 mAh 的具体版本并取得确认书。[厂家 FAQ](https://www.fpbattery.com/2mm-thickness-lipo-battery/)称可付费取样，但常规 MOQ 为每型号 100 只。1–3 只样品的现货、价格、完整厚度公差、引线出口、温度检测和国内发货均未确认，未联系厂家。
- **3 mm 包体新增询样候选，未改 CAD。** 2026-09-20 用户反馈淘宝难以找到上述 2 mm 型号，公开检索仍未确认符合原目标的国内零售现货。新增 [YDL 301225 80 mAh](https://ydlbattery.com/products/ydl-301225-80mah-3-7v-lithium-polymer-battery-3x12x27mm-with-ph2-0-connector)：页面称含保护板的包体为 27 × 12 × 3 mm，不含外置线材和插头的装配空间；交付最大尺寸、公差及规格书尚未核对。页面同时出现 10 只起订和 4–9 只阶梯价，1–3 只供应及国内配送未确认，不能作为已可下单样品推荐。34 × 12 × 2.6 mm 是原空间目标而非固定器件限制；约 3 mm 的窄电池可结合薄片前盖重新评估，不等于已满足整机 ≤5 mm。先获取现货完整尺寸，再重排和验证，避免只按目录型号反复搜索。

**用户提供的 302030 零售候选（2026-09-20）：** 大佳满益旗舰店截图选项为 302030 / 150 mAh，标称 3.7 V、32 × 20 × 3 mm、两根引线，截图优惠价 ¥7.3，页面宣传带保护芯片。尚未购买，未取得与交付批次一致的规格；完整包体最大厚度、保护板参数、充放电电流及 NTC 均待确认。可优先取 1 只样品量测，不能按标称容量承诺续航。

- 用户随后提供并指明属于 302030 的详情参数图：标称 3.7 V、满充 4.2 V、过放保护 2.7 ±0.1 V、过流保护 3.0 ±1.0 A。图内未注明型号或版本，先记为商家标称，尚非批次规格或实测。过流一行标题写成“电压”而单位是 A，应按电流阈值理解；保护动作阈值不等于电芯允许的持续/峰值放电电流，更不能用于设置充电电流。仍需确认标准/最大充电电流、持续/峰值放电电流和完整尺寸。
- 根据现有 `pcba-layout-report.json` 做轴对齐包络计算：在原电池坐标替换成 32 × 20 × 3 mm，会与屏幕重叠 32 × 5 × 1.1 mm，也超出当前 PCB 电池缺口。需重排屏幕、电池及 PCB 轮廓，不能原位替换；没有重新生成 CAD 或进行视觉检查。
- 后续已完成独立的[六色屏/302030 排布](../archive/pre-r1/enclosure/pcba-e6-302030.svg)：电池移到右下缺口，26 个简化实体检查通过。薄片前盖下的完整电池厚度规划上限为 3.45 mm，包含厂家要求的尺寸增长空间；只是基于当前壁厚和间隙假设的预算。电池到货需实测，2.5 mm PCB 窄桥仍待结构与布线验证，见[结构记录](../enclosure/README.md)。
- 薄片前盖的电池局部名义预算可研究为 0.8 mm 背壁 + 3.0 mm 电池 + 0.3 mm 前片 + 0.3 mm 绝缘/固定/间隙分配 = 4.4 mm。没有计入真实交付公差与厂家要求的尺寸增长预留，不代表整机厚度通过。
- 首张截图的“输入 4.2–5 V”和详情图的“充电器电压 4.2–5 V”均未解释测量位置，不能作为电池两线直接接 5 V 的依据；详情图已单列满充 4.2 V。保护板不代替恒流/恒压充电管理；保留项目的 [BQ25186 充电路径](https://www.ti.com/product/BQ25186)，实际截止电压与充电电流由电池规格确认。默认两线版本没有单独的 NTC 引线，项目仍需安排温度检测。

可供 LP201230 后续询样的文字：

> 做厚度不超过 5 mm 的电子名片，想先买 1–3 只 LP201230 60 mAh 样品。请确认有无现货和报价，并提供与交付样品一致的规格书、含保护板/胶带/焊点的最大长宽厚、满充及寿命末期尺寸预留、引线出口图、允许充放电电流、保护板参数及是否带 NTC。当前包体空间目标为 34 × 12 × 2.6 mm（长 × 宽 × 厚），请勿只提供裸电芯尺寸。

采购前必须拿到：完整包体最大 T/W/L、满充尺寸与鼓胀预留、保护板位置与高度、引线/焊点出口、4.2 V 还是其他充电终止电压、允许充电电流和脉冲放电电流、温度检测方式、样品 MOQ 与运输条件。目录中的工程样品定价不等于当前可交付报价；本轮未询价或下单。

不优先 CR2032（自身 3.2 mm 且座子再加高）；常规 CR2032 也不能接充电器。小型 LiPo 必须按电芯规格设置充电电流，不能直接使用默认大电流 TP4056 成品模块。

## 电源、连接与外围

| 功能 | 主选/备选 | 采用条件 |
| --- | --- | --- |
| 充电与电源路径 | **TI BQ25186** | 2.2 × 2.0 mm WSON，封装最高 0.8 mm；可设置 5 mA–1 A，带电源路径与温度监测；优先贴片组装 |
| 简化充电备选 | MCP73831 | 容易理解，但无完整电源路径/电池温度管理；必须另处理边用边充及终止判断，不能直接替换 |
| 3.3 V 稳压 | **TPS7A0233DBVR** 候选 | SOT-23-5 封装最高 1.45 mm、200 mA；检查瞬态、压差、输入/输出电容和反向电流条件 |
| NFC | 独立 PCB 线圈或 FPC 线圈 + 调谐电容预留 | NFC1/NFC2 接法按 Nordic 参考设计；根据最终电池/外壳装配测量调谐 |
| 日常编程与充电 | **GCT USB4500-03-0-A** 候选 | 连接 nRF52840 原生 USB 与充电路径；核对 CC、D+/D−、VBUS、ESD 和可恢复 bootloader |
| 首烧与救援 | **SWD 测试焊盘 + 外部调试器** | 留 SWDIO、SWCLK、GND、VTref，建议 RESET；不是日常必用接口 |
| USB-C 机械选型 | USB4500，0.8 mm 沉板，主体高 3.16 mm | 板边槽、板上下突出、壳体开口与插拔受力待核对，计入 ≤5 mm |
| 屏幕连接器/驱动外围 | FH12-24S-0.5SH(55) 候选；外围待冻结 | 24 pin / 0.5 mm 底接触；需验证 FPC 方向、插拔余量和当前版驱动参考电路 |

来源：[BQ25186](https://www.ti.com/product/BQ25186)、[其数据手册](https://www.ti.com/lit/ds/symlink/bq25186.pdf) 第 33、54 页；[TPS7A02](https://www.ti.com/product/TPS7A02) / [封装图](https://www.ti.com/lit/ds/symlink/tps7a02.pdf) 第 45 页；[MCP73831](https://www.microchip.com/en-us/product/mcp73831)。

BQ25186 的 ICHG_CTRL 复位值 0x05 对应约 10 mA，充电默认使能；这不是“任何小电池都安全”的结论。接电芯前必须核对默认充电电压、NTC、看门狗复位行为和电池允许值，包括 MCU 尚未启动的阶段。SYS 可达 4.4–5.5 V 或其他配置状态，经稳压再供电。保护板、电源路径、充电控制各有职责，不能互相替代。

## 可以买现成的吗？

本轮没有找到同时有可编程 NFC 标签切换、墨水屏、多按键、充电以及**可核实成品厚度 ≤5 mm**的现成产品；这不是宣称市场上绝不存在。

| 参考产品/项目 | 可以借鉴什么 | 与本目标的差距 |
| --- | --- | --- |
| [Seeed EN04](https://wiki.seeedstudio.com/epaper_EN04/) | nRF52840、墨水屏驱动、按键与 NFC 的开发平台 | 适合功能验证；开发板外围/接口高度不能直接当薄名片 |
| [LILYGO T-Echo](https://github.com/Xinyuan-LilyGO/T-Echo) | nRF52840 + 墨水屏的开源参考 | LoRa/GNSS 等占空间；现成固件的 NFC 支持要单独确认 |
| [T-Echo Card](https://lilygo.cc/products/t-echo-card) | 卡片外形交互参考 | 厂商列 90 × 60 × 9.5 mm，0.42 英寸 OLED；不是薄墨水屏方案 |
| [Espruino Pixl.js](https://www.espruino.com/Pixl.js) | 可编程 NFC 与四按键 | LCD，整机约 60 × 53 × 15 mm，不符合屏幕/厚度目标 |
| [L-ink Card](https://github.com/peng-zhihui/L-ink_Card) | 薄结构、ST25DV 与墨水屏设计 | 功能与固件需逐项审查，不能当现成多身份名片；多芯片物理切换也不等于本方案 |

当前成品路线为定制 PCB/PCBA，成品小板保留作手机读取、按键切换与屏幕刷新的桌面验证。板上贴片件按嘉立创 SMT 可供料范围匹配；屏幕、电池由适合的小量渠道采购并后装，立创商城零售库存不等于 SMT 库存。所有实际器件、连接器、焊点和线材均需纳入厚度预算。

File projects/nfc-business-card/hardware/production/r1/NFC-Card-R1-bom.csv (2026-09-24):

No. | Quantity | Comment | Designator | Footprint | Value | Manufacturer Part | Manufacturer | Supplier Part | Supplier
1 | 4 | 2.2uF 16V | C1,C3,C4,C5 | C0603 | 2.2uF | CL10A225KO8NNNC | SAMSUNG(三星) | C23630 | LCSC
2 | 2 | 10uF 10V | C2,C6 | C0603 | 10uF | CL10A106KP8NNNC | SAMSUNG(三星) | C19702 | LCSC
3 | 1 | 100nF 50V | C7 | C0603 | 100nF | CC0603KRX7R9BB104 | YAGEO(国巨) | C14663 | LCSC
4 | 1 | 4.7uF 16V | C8 | C0603 | 4.7uF | CL10A475KO8NNNC | SAMSUNG(三星) | C19666 | LCSC
5 | 11 | 1uF | C9,C10,C11,C12,C13,C16,C17,C18,C20,C21,C22 | C0805 | 1uF | CL21B105KBFNNNE | SAMSUNG(三星) | C28323 | LCSC
6 | 3 | 4.7uF | C14,C15,C19 | C0805 | 4.7uF | CL21B475KAFNNNE | SAMSUNG(三星) | C98195 | LCSC
7 | 2 | 220pF C0G (tune) | C23,C24 | C0603 | 220pF | GRM1885C1H221JA01D | muRata(村田) | C77032 | LCSC
8 | 3 | MBR0530T1G | D1,D2,D3 | SOD-123_L2.7-W1.6-LS3.7-RD-1 |  | MBR0530T1G | onsemi(安森美) | C82046 | LCSC
9 | 1 | USB4500-03-0-A | J1 | USB4500 E20 Routed Cutout |  | USB4500-03-0-A | GCT | C5354966 | LCSC
10 | 1 | FPC-05FB-24PH20 | J2 | FPC-SMD_24P-P0.50_FPC-05FB-24PH20 |  | FPC-05FB-24PH20 | XUNPU(讯普) | C2856831 | LCSC
11 | 1 | 47uH | L1 | IND-SMD_L3.0-W3.0 | 47uH | NRH3010T470MN | TAIYO YUDEN(太诱) | C223116 | LCSC
12 | 1 | SI1308EDL-T1-GE3 | Q1 | SOT-323_L2.0-W1.3-P1.30-LS2.1-BR |  | SI1308EDL-T1-GE3 | VISHAY(威世) | C469327 | LCSC
13 | 2 | 5.1k 1% | R1,R2 | R0603 | 5.1kΩ | 0603WAF5101T5E | UNI-ROYAL(厚声) | C23186 | LCSC
14 | 3 | 0Ω | R3,R4,R16 | R0603 | 0Ω | 0603WAF0000T5E | UNI-ROYAL(厚声) | C21189 | LCSC
15 | 8 | 10k 1% | R5,R6,R7,R8,R9,R10,R11,R12 | R0603 | 10kΩ | 0603WAF1002T5E | UNI-ROYAL(厚声) | C25804 | LCSC
16 | 1 | 100kΩ | R13 | R0603 | 100kΩ | 0603WAF1003T5E | UNI-ROYAL(厚声) | C25803 | LCSC
17 | 2 | 10kΩ | R14,R18 | R0603 | 10kΩ | 0603WAF1002T5E | UNI-ROYAL(厚声) | C25804 | LCSC
18 | 1 | 2.2Ω | R15 | R0603 | 2.2Ω | 0603WAF220KT5E | UNI-ROYAL(厚声) | C22939 | LCSC
19 | 1 | 3Ω | R17 | R0603 | 3Ω | 0603WAF300KT5E | UNI-ROYAL(厚声) | C23157 | LCSC
20 | 3 | SKQGABE010 | SW1,SW2,SW3 | KEY-SMD_4P-L5.2-W5.2-P3.70-LS6.4 |  | SKQGABE010 | ALPSALPINE(阿尔卑斯阿尔派) | C115351 | LCSC
21 | 1 | MDBT50Q-P1MV2 | U1 | COMM-SMD_MDBT50Q-1MV2 |  | MDBT50Q-P1MV2 | RAYTAC | C5119772 | LCSC
22 | 1 | BQ25186DLHR | U2 | WSON-10_L2.2-W2.0-P0.40-BL-EP_TI_DLH0010A |  | BQ25186DLHR | TI(德州仪器) | C44639442 | LCSC
23 | 1 | TPS7A0233DBVR | U3 | SOT-23-5_L2.9-W1.6-P0.95-LS2.8-BL |  | TPS7A0233DBVR | TI(德州仪器) | C5142805 | LCSC
24 | 1 | TPS22919DCKT | U4 | SC-70-6_L2.0-W1.3-P0.65-LS2.1-BR |  | TPS22919DCKT | TI(德州仪器) | C2860814 | LCSC
25 | 2 | TPD2EUSB30DRTR | U5,U6 | SOT-9X3-3_L1.0-W0.8-P0.35-LS1.0-BR |  | TPD2EUSB30DRTR | TI(德州仪器) | C97502 | LCSC

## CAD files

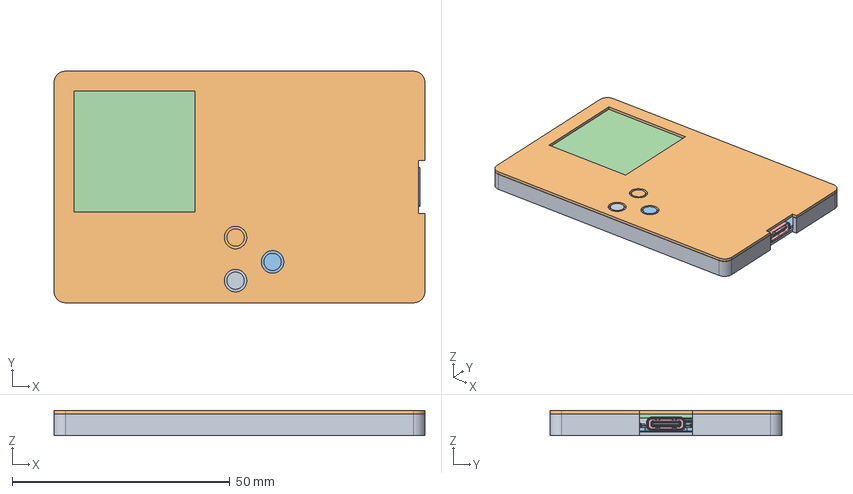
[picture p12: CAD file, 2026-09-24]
projects/nfc-business-card/enclosure/r1-clear-5.8/e20-clear-assembly.FCStd
85.2 x 53.2 x 5.80 mm
ClearTray
ClearLid
PCB
Component_C9
Component_C10
Component_C11
Component_C12
Component_C13
Component_C14
Component_C15
Component_C16
Component_C17
Component_C18
Component_C19
Component_C20
Component_C21
Component_C22
Component_C1
Component_C2
Component_C3
Component_C4
Component_C5
Component_C6
Component_C7
Component_C8
Component_C23
Component_C24
Component_R1
Component_R2
Component_R3
Component_R4
Component_R5
Component_R6
Component_R7
Component_R8
Component_R9
Component_R10
Component_R11
Component_R12
Component_R13
Component_R14
Component_R15
Component_R16
Component_R17
Component_R18
Component_U1
Component_U4
Component_D1
Component_D2
Component_D3
Component_U5
Component_U6
Component_U2
Component_J2
Component_U3
Component_Q1
Component_L1
Component_SW1
Component_SW3
Component_SW2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

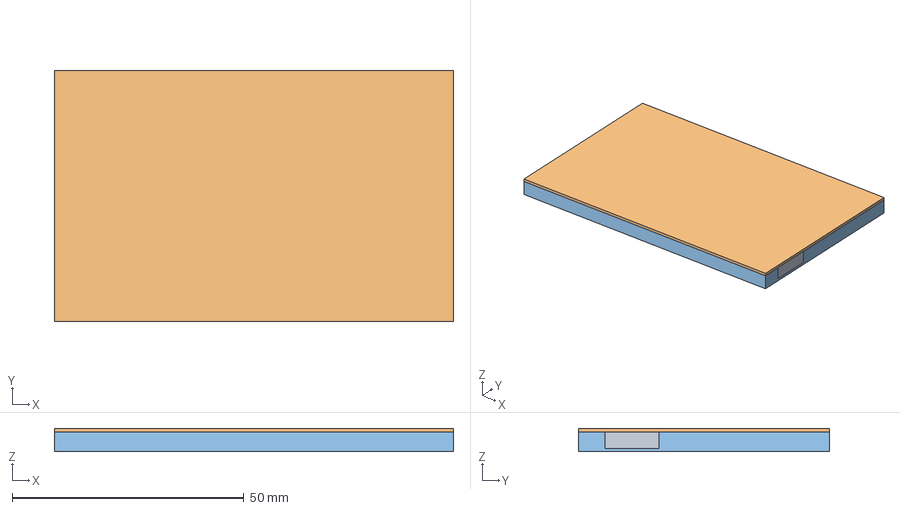
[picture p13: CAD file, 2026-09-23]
projects/nfc-business-card/enclosure/pcba-layout-workflow-validation.FCStd
86.0 x 54.0 x 5.00 mm
背壁预算面
前壁预算面（隐藏）
86 × 54 × 5 mm
0.8 mm PCB · 电池缺口 / USB 槽假设
U1 · MDBT50Q-P1MV2
DS1 · GDEY0154D67 玻璃
BT1 · 完整包体采购目标
J1 · USB4500 主体
USB 焊脚与装配区
J2 · FH12-24S
屏幕 FPC 路径与插入预留
屏幕升压器件区
NFC 专用区域
模块 2.4 GHz 天线预留
U2 · BQ25186
U3 · TPS7A0233
U4 · TPS22919 预留
电源与保护外围区
SWD 探针操作区
SW1 · SKQGABE010
按键 1 键帽与行程预留
SW2 · SKQGABE010
按键 2 键帽与行程预留
SW3 · SKQGABE010
按键 3 键帽与行程预留

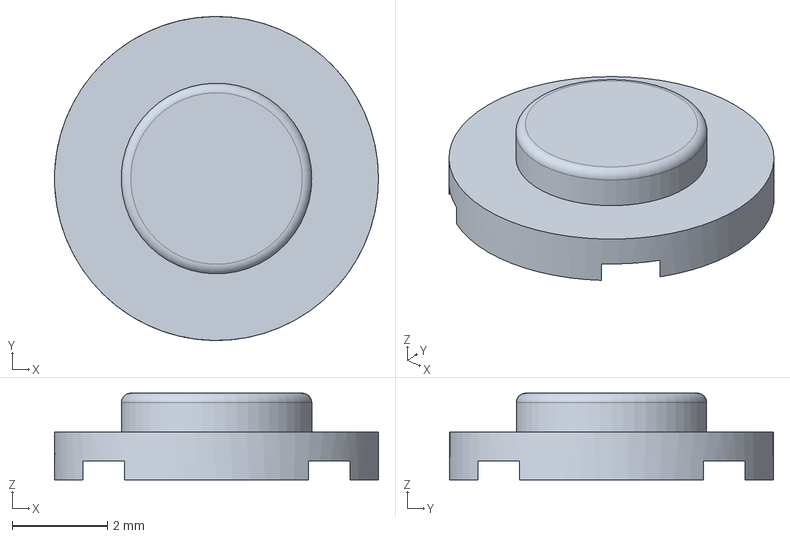
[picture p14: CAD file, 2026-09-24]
projects/nfc-business-card/enclosure/r1-usb-height-5.2/key-1.step
6.80 x 6.80 x 1.82 mm

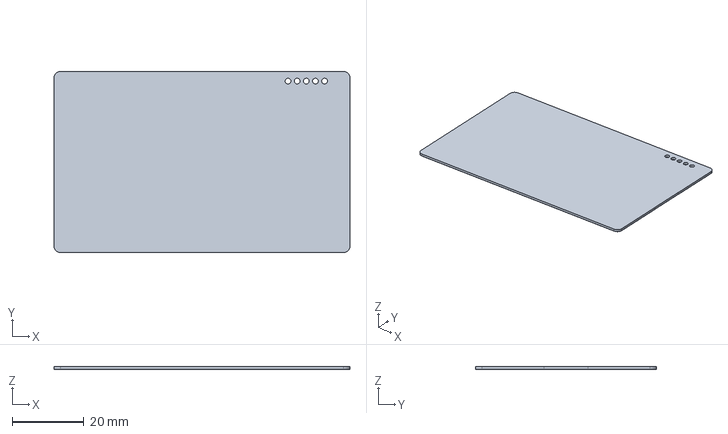
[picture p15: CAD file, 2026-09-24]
projects/nfc-business-card/enclosure/r1-usb-height-5.4/rear.step
82.3 x 50.3 x 0.8 mm

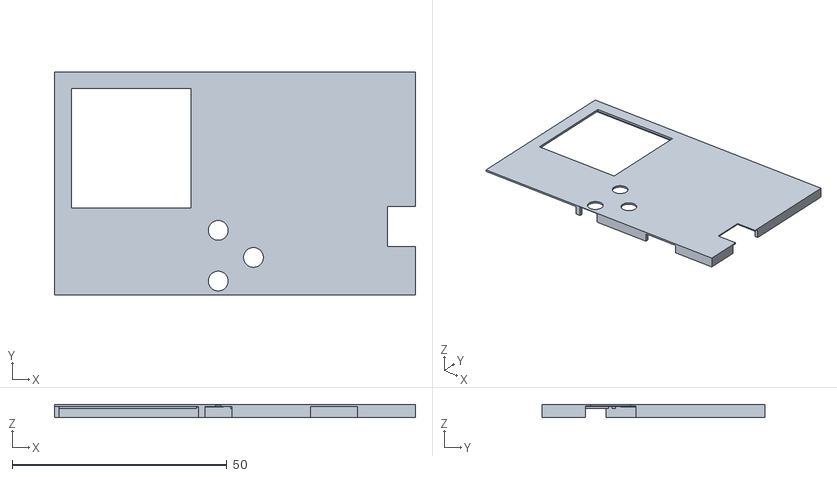
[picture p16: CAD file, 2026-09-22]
projects/nfc-business-card/enclosure/nfc-card-e16-top-v7.stl
84.0 x 52.0 x 3.00

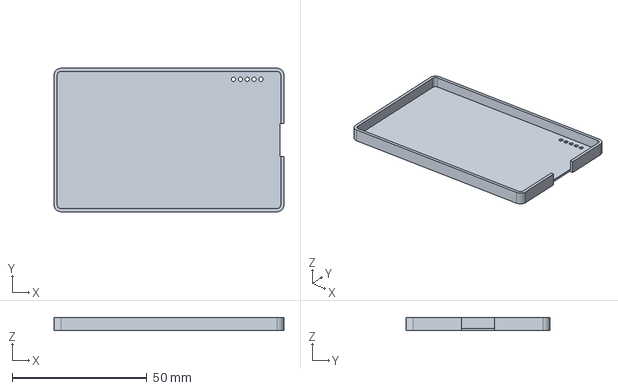
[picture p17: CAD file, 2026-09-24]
projects/nfc-business-card/enclosure/r1-clear-5.8/e20-clear-tray.step
85.2 x 53.2 x 4.94 mm

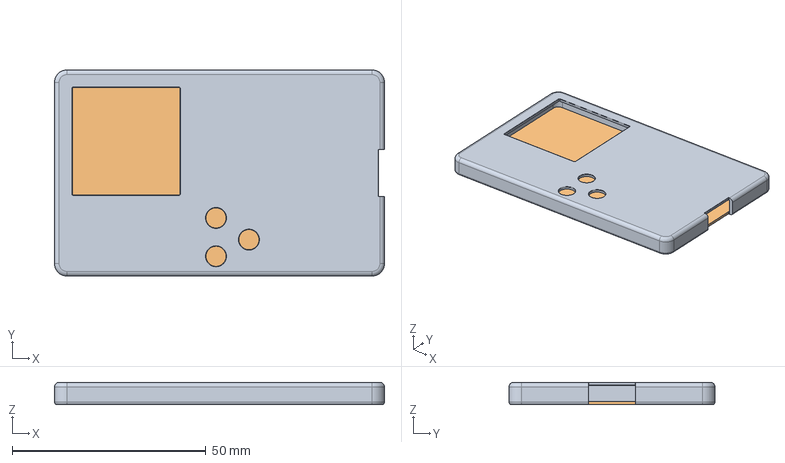
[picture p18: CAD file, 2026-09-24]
projects/nfc-business-card/enclosure/r1-rounded-rear-soft-swd254/rear-cover-study.step
85.2 x 53.2 x 5.80 mm

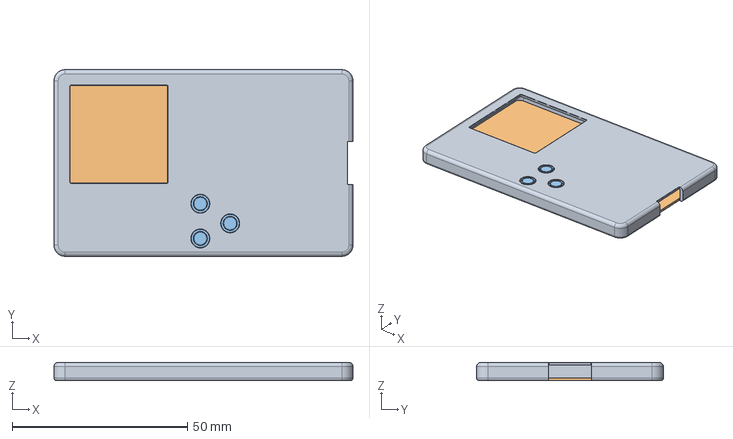
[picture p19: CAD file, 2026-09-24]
projects/nfc-business-card/enclosure/r1-usb-height-5.2/print-parts.step
85.2 x 53.2 x 5.20 mm

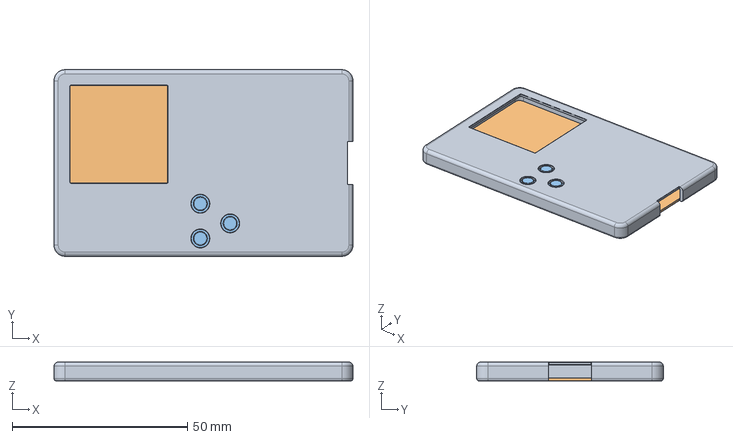
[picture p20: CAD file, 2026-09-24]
projects/nfc-business-card/enclosure/r1-usb-height-5.4/print-parts.step
85.2 x 53.2 x 5.40 mm

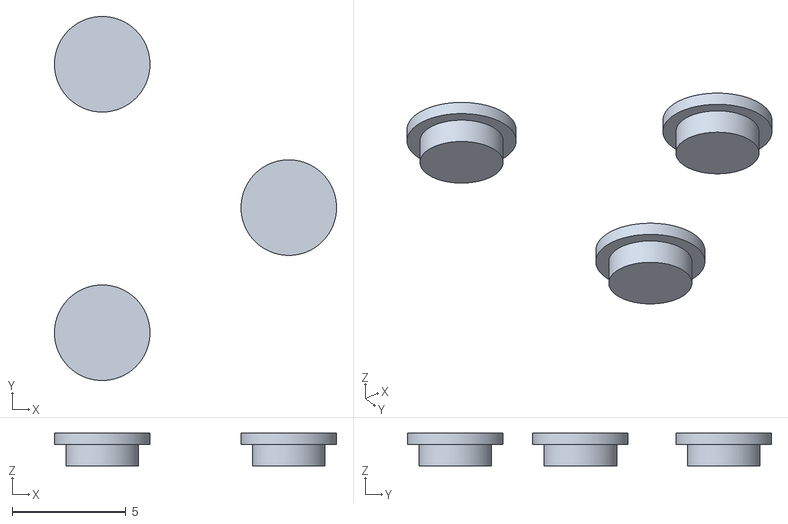
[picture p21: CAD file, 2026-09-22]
projects/nfc-business-card/enclosure/nfc-card-e16-keycaps-v7.stl
12.4 x 16.0 x 1.45

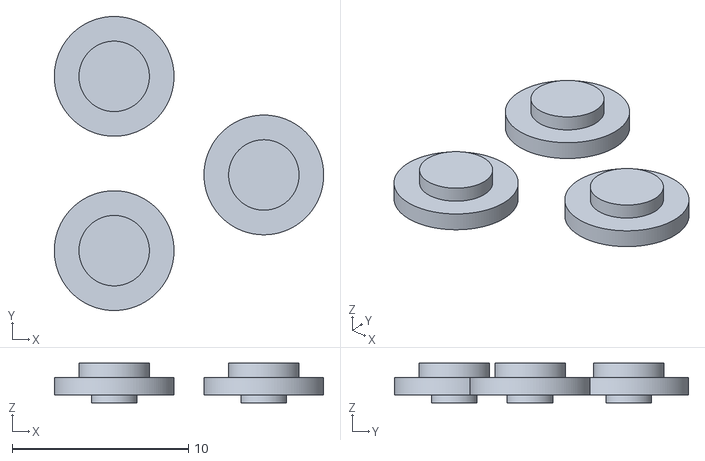
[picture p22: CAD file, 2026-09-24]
projects/nfc-business-card/enclosure/r1-clear-5.8/e20-clear-keys.stl
15.3 x 16.7 x 2.25

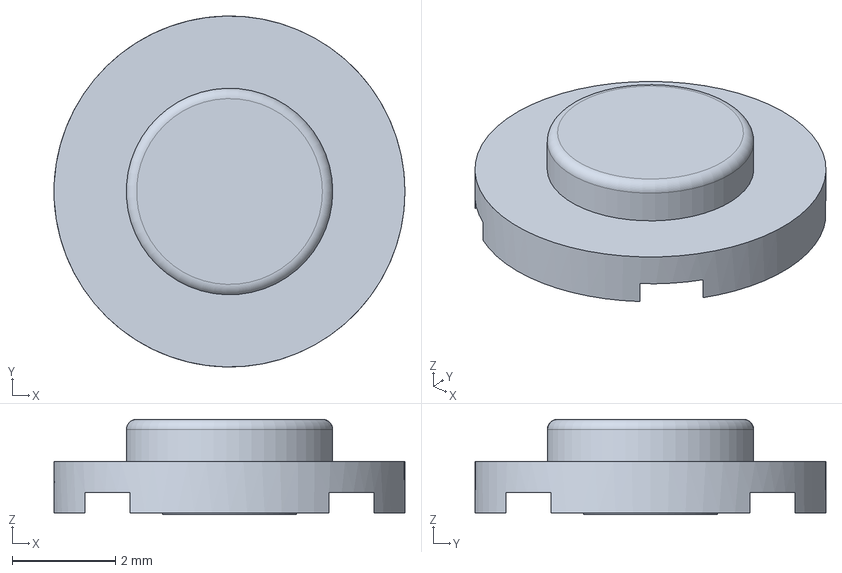
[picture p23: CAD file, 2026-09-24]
projects/nfc-business-card/enclosure/r1-usb-height-5.4/key-2.step
6.80 x 6.80 x 1.85 mm

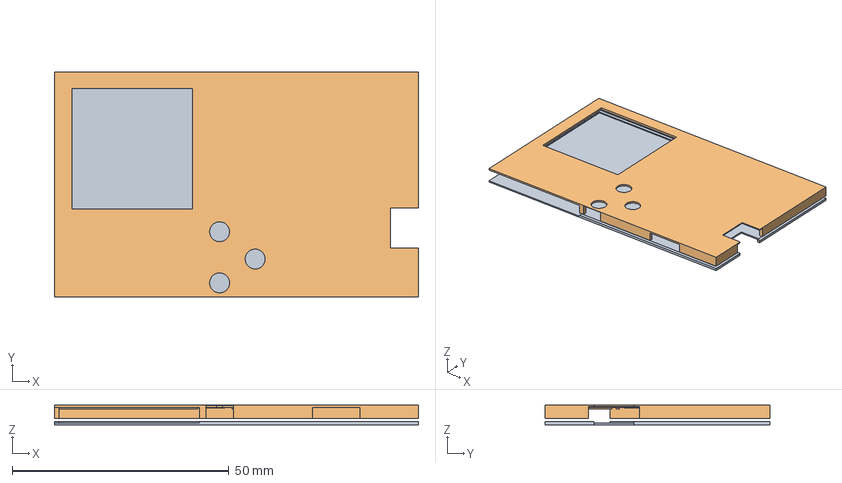
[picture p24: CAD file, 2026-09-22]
projects/nfc-business-card/enclosure/nfc-card-e16-enclosure-v7.step
84.0 x 52.0 x 4.50 mm

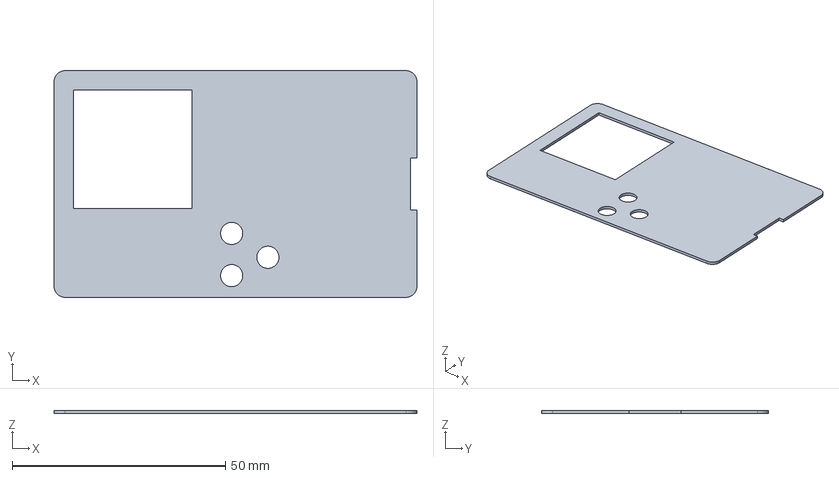
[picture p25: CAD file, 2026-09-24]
projects/nfc-business-card/enclosure/r1-clear-5.8/e20-clear-lid.step
85.2 x 53.2 x 0.8 mm

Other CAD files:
projects/nfc-business-card/enclosure/r1-usb-height-5.2/key-3.step
projects/nfc-business-card/enclosure/r1-usb-height-5.2/rear-cover-study.FCStd
projects/nfc-business-card/enclosure/r1-usb-height-5.4/key-1.step
projects/nfc-business-card/enclosure/r1-usb-height-5.2/rear.step
projects/nfc-business-card/archive/pre-r1/enclosure/e20-clear-5.8/e20-clear-assembly.FCStd
projects/nfc-business-card/archive/pre-r1/enclosure/e20-clear-5.8/e20-clear-keys.stl
projects/nfc-business-card/archive/pre-r1/enclosure/e20-clear-5.8/e20-clear-lid.step
projects/nfc-business-card/archive/pre-r1/enclosure/e20-clear-5.8/e20-clear-lid.stl
projects/nfc-business-card/archive/pre-r1/enclosure/e20-clear-5.8/e20-clear-tray.step
projects/nfc-business-card/archive/pre-r1/enclosure/e20-clear-5.8/e20-clear-tray.stl
projects/nfc-business-card/archive/pre-r1/enclosure/e20-clear-6.2/e20-clear-assembly.FCStd
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

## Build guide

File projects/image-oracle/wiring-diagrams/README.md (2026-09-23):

# Image Oracle 接线图册

本目录保存交互式 HTML 接线图；点击表中页面或使用 macOS `open` 命令打开。`sources/` 保留可编辑的对话图源，目录下同名 HTML 是可独立打开的导出页面。

## 当前确定方案

沿用 [oracle_live 桌面原型](../firmware/oracle_live/README.md)已验证的屏幕与 MID 中心键接线，不改变 GPIO。当前接线入口为[屏幕引脚位置](display-pin-locations.html)、[中心按键引脚位置](button-pin-locations.html)和[三路共地](shared-ground-wiring.html)；相机沿用原板排线。

2026-09-19 已完成原型实物验收。图中的面包板孔号是示例，共地近照尚未取得；具体适用版本和验证范围见下表。修改图源从 `sources/` 进入，同名 HTML 是对外查看入口。

## 已归档的图

| 图 | 内容 | 适用范围与验证状态 |
| --- | --- | --- |
| [屏幕引脚位置](display-pin-locations.html) | 主板外形、完整丝印、屏幕八针 ①～⑧，可逐根高亮 | ESP32-S3-CAM N16R8；对应当前 ST7789 接线，用户已确认基本显示 |
| [中心按键引脚位置](button-pin-locations.html) | 按键八针顺序、① COM 与 ⑥ MID 的主板位置 | 用户已确认接线，中心键计数、持续连按及第三个程序的定格操作均已实测 |
| [三路共地](shared-ground-wiring.html) | 主板 GND、屏幕 GND、按键 COM 接同组 a5／b5／c5 | 用户报告已按方案接好；孔号用于示例，未收到接线近照 |
| [面包板内部连接](breadboard-connections.html) | 选择孔位，显示内部相通的五个孔 | 典型 a～j 面包板接线区；不包含两侧电源轨 |

主板位置图固定为“金属盖朝前、天线上、USB 下”，按实物照片排列引脚；圈号表示模块端针序，主板圆点旁仍是 GPIO 丝印。按键图中的灰色主板针脚不代表空闲 GPIO。

接线依据与实测详情：[屏幕接线表](../hardware/display-wiring.md)、[按键接线表](../hardware/button-wiring.md)、[屏幕启动记录](../docs/display-bringup.md)。接线前断电，不能只依据图中的空间位置省略丝印核对。

## 打开与维护

从仓库根目录打开：

```sh
open projects/image-oracle/wiring-diagrams/display-pin-locations.html
open projects/image-oracle/wiring-diagrams/button-pin-locations.html
```

制作规范及重新导出命令见[仓库统一方法](../../../docs/wiring-diagrams.md)。以 `sources/` 为修改入口，重新生成同名独立页面；不要保存额外的 `*-preview.html`。

2026-09-19：归档了对话中的四张原图，使用 Codex `visualize` 1.0.38 导出独立页面。源文件一致性、导出内容和脚本语法已检查；主板图此前已通过 320／360／736 px 下的脚本运行与选择状态检查。本次未新增浏览器目视检查或硬件测试。

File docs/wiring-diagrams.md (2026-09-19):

# 接线图制作与归档方法

2026-09-19，用户确认偏好当前“实物主板外形 + 完整排针丝印 + 数字序号 + 可选择高亮”的 HTML 图。此格式作为本仓库后续接线图的默认形式，适用于所有项目。

## 统一目录

生成第一张接线图时，按下列结构创建目录；没有接线图的项目暂不创建目录或占位 README。

```text
projects/<项目名>/wiring-diagrams/
├── README.md                     # 图册、接线依据与验证状态
├── <接线主题>.html               # 可用浏览器直接打开的完整页面
└── sources/
    └── <接线主题>.html           # 可编辑、可嵌入对话的 HTML 片段
```

当前示例见 [Image Oracle 图册](../projects/image-oracle/wiring-diagrams/README.md)。其他项目产生接线图时沿用同名目录；未确认的硬件不预先画成确定接线图。

HTML 接线图是刻意保存的项目文档，源文件和独立页面一起纳入版本管理。不要保存临时预览副本，也不要只引用对话缓存路径。接线表和验证记录仍放在项目 `hardware/`、`docs/`，由图册链接过去。

## 默认画法

1. **按实物定位。** 根据已核对的照片和资料画出主板轮廓、天线、金属罩、USB 口、按钮等定位特征；标明元件正面／背面和摆放方向。当前 ESP32-S3-CAM 示例固定为“金属盖朝前、天线上、USB 下”。这不是其他板卡的通用布局。
2. **保留完整排针。** 左右两排按实物次序显示全部丝印，让用户可以数到目标针。GPIO 编号按原样保留，不能按数值重新排序。
3. **模块端决定圈号。** 顶部显示模块全部排针，并按实际顺序标 ①②③……；主板对应接线处显示同一圈号和模块信号名。圈号是模块针序，旁边的 `14`、`40` 等是主板 GPIO。只使用部分功能时保留原编号，例如按键 MID 仍是 ⑥，不重新编号为 ②。
4. **清楚表现本次接线。** 用高亮圆点、短连线和标签标出端点；未接脚保持中性样式并注明暂不接。灰色主板针脚只表示本图未高亮，不意味着未被摄像头、存储器或其他模块占用。
5. **单独说明分支。** 共地可另画面包板局部图，标明孔号、内部相通范围和公／母接头；不要让多条连接看起来需要挤进一个插孔。电源、电压、共地与信号线须区分。
6. **支持逐根定位。** 适合时增加“全部／某根线”的下拉选择，同步高亮模块端与主板端、更新简短连接说明。保留键盘可用的原生控件；不用无关动画或装饰面板。
7. **适应屏幕宽度。** 使用主题颜色、可读文字和实际容器宽度生成 SVG，窄屏调整排布，不能靠缩小整张图导致字看不清。中文用于说明，代码和代码注释用英文。

视觉布局可以复用，引脚事实必须逐项确认。未经确认的引脚不补猜；绘图不会自动更改固件，也不代表实物已接好或已通过测试。

## 制作与修改

先读目标项目 README、接线表、当前固件引脚常量及可用的实物照片。复用最接近的 `sources/` 图作为起点；换板卡时重新建立排针数据。

现有主板图用 HTML + 内联 SVG + 少量 JavaScript，无需图像生成模型：

- `left`、`right` 数组保存实物的左右排针顺序。
- `connections` 保存 `signal`、`pin`、`side`、从零起算的 `position` 和 `badge`；同一份数据驱动高亮及连接说明。
- `ResizeObserver` 在容器尺寸变化时重画，文字大小保持可读。
- `window.openai.widgetState`／`setWidgetState` 保存选中项；独立页面的导出壳提供兼容支持，不需要对话继续运行。

源文件是 HTML 片段；独立页面包含主题样式和运行所需的导出壳。修改源文件后重新导出，不直接编辑生成的独立页面，以免两份图不一致。新图需同步加入该项目图册；接线改变时，也要同步核对固件和接线文档。

## 导出与打开

本批图使用已安装的 Codex `visualize` 1.0.38 技能附带 `scripts/render.py` 导出。此工具用于给片段补齐独立页面，不参与硬件编译或烧录；升级技能后按当前安装位置调整工具路径。

以下从仓库根目录执行，以屏幕图为例。`--force` 会更新同名独立页面，输入和输出必须是不同文件：

```sh
visualize_renderer="$HOME/.codex/plugins/cache/openai-bundled/visualize/1.0.38/skills/visualize/scripts/render.py"
wiring_directory="$PWD/projects/image-oracle/wiring-diagrams"

python3 "$visualize_renderer" \
  "$wiring_directory/sources/display-pin-locations.html" \
  "$wiring_directory/display-pin-locations.html" \
  --title '屏幕接线位置 · ESP32-S3-CAM' --force

open "$wiring_directory/display-pin-locations.html"
```

其他图替换输入／输出文件名和标题；其他项目替换项目目录。现有独立页面可以直接打开，重导出时才需要上述工具。导出壳可能引用 CDN 图标／提示库，不将离线兼容性视为已验证能力。

工具如提示存在 `window.openai` 引用，检查是否只有受支持的 `widgetState`／`setWidgetState`；不要把依赖对话宿主的其他动作直接带入独立页面。本批三个交互图只有这两种 API。

## 检查与记录

- 逐项对照实物排针、接线表和固件映射，特别检查视角是否镜像、编号是否错位、电源与相邻 GPIO 是否混淆。
- 检查下拉选择、高亮、连接说明和恢复选中项，在 320 px 与桌面宽度下验证布局；可用浏览器时检查实际渲染。脚本模拟或语法检查不替代目视检查。
- 确认独立页面包含最新源片段，脚本可以解析，图册相对链接可用；归档原图时确认副本与原图一致。
- 执行 `git diff --check`；只修改图与文档不需要编译或烧录固件。
- 图册分别记录“接线方案”“源码已构建”“已烧录”“用户确认显示／按键实测”等状态，避免把图已生成写成硬件已验证。

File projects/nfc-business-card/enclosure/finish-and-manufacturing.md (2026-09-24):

---
description: 参考 AI Passport 的透明外壳质感，区分量产工艺与个人打样路线
last_updated: 2026-09-18
---

# 透明外壳的质感与制造流程

用户希望了解 TRAE 联名 AI Passport 那类外壳的制作方式，以便选择名片的外壳路线。这里记录工艺选项，不将量产开模视为已确定的计划。

## 产品事实与推断

[FoloToy 官方页面](https://ai-passport.folotoy.cn/) 明确将透明外壳作为产品设计的一部分。本轮未找到可确认其具体树脂牌号、模具方案、涂层或印刷工艺的官方制造资料。因此不能把“PC 注塑”“某种喷漆”直接写成该产品的实际工艺。

下文讨论的是获得类似透明消费电子外观的常见工程路线，是否接近 AI Passport 的实际触感，仍需到货后观察与对照试片。

## 常见量产流程

| 阶段 | 做什么 | 对最终质感的影响 |
| --- | --- | --- |
| 外观设计 | 定整体比例、圆角、透明区域、颜色、按钮与图案 | 让屏幕、PCB 和外壳形成统一视觉布局 |
| 结构设计 | 根据 PCB/USB/电池设计前后壳、支撑、卡扣或螺丝、定位台阶 | 装配缝隙均匀，按钮不松晃，插拔 USB 时壳体不变形 |
| 手板验证 | SLA 打印或 CNC 样件，检查握持、透明度、装配和操作 | 先发现设计问题，避免把不合适的结构做进模具 |
| 模具设计与试模 | 审核壁厚、拔模、浇口、顶出位置、收缩与分型线；开模并试件修正 | 决定批量尺寸稳定性，以及浇口/顶针痕是否出现在显眼位置 |
| 注塑与表面效果 | 用选定树脂注塑；模具抛光形成亮面，纹理处理形成磨砂等效果 | 很多表面效果直接从模具复制到塑料，并非每件都靠后期打磨 |
| 装饰与装配 | 按设计进行印刷、局部涂层或贴合；安装屏幕、PCB、电池和按键 | 图案边缘、遮挡、装配清洁度与细节一致性共同形成成品感 |

透明 PC 是可选材料之一，具体透明度、抗冲击、耐刮、加工难度与壁厚要按牌号权衡；不能把透明材料都视为同一种塑料。原厂依据：[PC 注塑](https://www.protolabs.com/services/injection-molding/polycarbonate/)、[模具纹理与表面处理](https://www.protolabs.com/resources/design-tips/mold-texture-standards-and-finishes/)、[注塑加工](https://www.protolabs.com/services/injection-molding/)。

图案可以用丝印、移印或适合材料的数字印刷等方式。透明面板还可考虑内侧反印，让图案透过面板显示；它属于设计选项，不代表已确认 AI Passport 采用同样工艺。参考：[CCL 装饰产品与 second-surface 方案](https://ccldesign.com/decorative-products)。

## 做一两台怎么获得接近的外观

### 方案一：透明 SLA 树脂 + 后处理

完成结构模型后，委托手板厂打印、清洗与固化，去支撑，逐级湿磨、抛光，再根据效果选择透明涂层或哑光处理。透明部位和磨砂部位分区，最后做印刷/贴膜与装配。

透明树脂打印后仍可能存在支撑痕与表面散射；表面精加工可以明显改善透明效果。不能把“透明树脂材料”直接等同于无需处理的透明成品，也不能把光敏树脂当成注塑 PC 的耐用性替代品。参考：[Formlabs 透明打印后处理](https://formlabs.com/blog/3d-printing-transparent-parts-techniques-for-finishing-clear-resin/)。

这是外观手板路线，需要把手工处理造成的边缘变薄、尺寸变化和涂层厚度计入装配。5 mm 总厚度目标下，仍要检查工厂的最小壁厚；后处理不会消除结构要求。

### 方案二：成品薄面板 + 打印中框

沿用用户提出的卡套思路：前后是现成光滑片材/卡套面板，中框负责高度、定位和按键支撑。比较 PP、PET、PC 的实际样片，尤其检查隔着面板的小字/二维码、刮擦与手感；截图商品的 PP 材质尚未核实。

为了获得更统一的外观，可以控制周边接缝、统一圆角、把胶藏在台阶槽中，并用内侧印刷或装饰膜遮住胶边和不希望露出的区域。USB-C 开口需要整齐且能承受插拔，按键露出高度保持一致。它比只在四周随意涂一圈胶更容易控制装配质量。

这条路线适合本项目继续保持薄度，前后片不需要打印。已有的 [卡套方案](../archive/pre-r1/enclosure/card-holder-option.md) 继续有效，材料和表面效果通过样品选择，不先锁定。

### 方案三：结构稳定后再评估注塑

开模是独立的前期投入，后续结构修改也可能涉及修模。若未来要做一批，再根据数量、模具寿命、表面等级和具体结构询价。没有可靠的通用数量分界或本项目报价，不声称达到某个数量就必然划算。

## 现成透明壳采购线索

2026-09-18 检索确认有现售的透明 PC 硬质卡套，可作为外壳或面板候选；尚未确认满足本项目 ≤5 mm 总厚度、USB-C 与按键空间的成品型号，也未查到 AI Passport 原厂空壳的公开独立销售页面。

[LifeShopping 透明双槽硬卡套](https://www.lifeshopping.com.tw/product/cahw0093) 的商家规格列出：CAHW0093A 直式外形 60 × 100 mm，CAHW0093B 横式外形 90 × 68 mm，均标称 PC，可放 87 × 53 mm 卡片。该页面同时售卖 PVC 软套，不能混用不同选项的材料和尺寸。硬款未给出总厚度、电子元件可用净高或前后盖拆分方式；这里只作为存在此类成品的来源，未验证装配、库存及配送条件。

淘宝/1688 可继续用「透明 PC 硬质卡套 可拆」「双面透明 卡套 上下盖」「电子工牌 空壳」「透明电子外壳 公模」检索。优先找可重复打开、前后面较平整的款式。先核实外尺寸、内部净高、面板厚度、卡扣/筋条和开孔位置，再按选定外壳布置 PCB；不要只依据“能装几张卡”或“容量厚度”判断能否容纳电子模块。

若找到外观合适但内腔偏薄的卡套，可评估沿用前后盖并替换为打印中框，中框负责 USB/按键开口和内部定位。原有边沿、卡扣是否可保留，以及改装后能否满足总厚度，仍需样品实测。

## 当前透明 SLA 试样安排

2026-09-18 用户反馈现成卡套内腔普遍偏低，并提供标有「SLA」「全透明树脂」的打印服务截图，希望尝试透明打印。当前将透明 SLA 试样放在前面，卡套改造与成品薄片保留为备选。这是试样方向，不代表材料、整壳尺寸或下单已确定。

用户随后补充的材料截图明确写有「透明树脂」「精度 ±0.1 mm」「最小壁厚 0.8 mm」。这是商家标称能力，支持把 0.8 mm 作为试样起点；但未注明 ±0.1 mm 对应外尺寸、壁厚还是局部特征，也未给出银行卡大小平面的翘曲限值、后处理后的尺寸保证或具体树脂牌号。不能将它直接当成装配后整机总厚度的公差。

标题中的「高韧性」「全透明」不能证明是同一材料选项。需要供应商明确材料型号及对应数据表，并区分原始打印、打磨抛光、透明涂层等交付效果。透明 SLA 经后处理可提高透明度，但不同设备、材料和形状的结果不能直接互推。参考：[Formlabs 透明打印后处理](https://formlabs.com/blog/3d-printing-transparent-parts-techniques-for-finishing-clear-resin/)。

建议分两步验证，以下尺寸是试验建议，尚非该商家的可制造承诺：

1. 先做 0.8 / 1.0 / 1.2 mm 三档壁厚的小样，包含一个圆角和代表性孔边；0.8 mm 为该材料页面标称最小壁厚，实际模型仍需审核。比较原始表面与后处理表面的小字/二维码可读性、手感、实测厚度与轻微弯曲表现。
2. 选出材料和工艺后，再做约 86 × 54 mm 的浅壳或面板，确认完整跨度的翘曲、平整度和接缝；小样成功不能证明整张薄盖合格。供应商应给出后处理后的尺寸公差和支撑面安排。薄壁性能取决于结构、材料和打印设备，参考：[Formlabs 壁厚设计说明](https://formlabs.com/blog/minimum-wall-thickness-3d-printing/)。

厚度示例：5.0 mm 外高减去两片 0.8 mm 面板，只剩 3.4 mm 内腔；当前 nRF52840 候选模块、0.8 mm PCB 与焊接高度的保守预算约 3.2 mm，仅剩 0.2 mm，尚未分配绝缘、装配间隙、涂层和外壳偏差，也未验证 USB 局部。两片 1.0 mm 面板则仅剩 3.0 mm，不够容纳该候选堆叠。因此透明度改善不等于薄度问题已解决，若样片表明壁厚不可再减，转用一面成品薄片或重新选更薄电子方案；不擅自放宽 ≤5 mm 目标。

作为敏感性示例，假设前后壁实际各增厚 0.1 mm，就会消耗上述 0.2 mm 余量。此例不表示商家的「精度」必然按每片壁厚独立叠加；正式预算需要实际结构尺寸链。最小可打印壁厚也不等于带 USB 开口、按键受力和大跨度面板的可靠壁厚，可在不挤占器件的周边局部加宽或加筋，但需同时检查外形与天线空间。

可用于用户自行咨询的简短描述：

> 想做约 86 × 54 mm、整机厚度目标不超过 5 mm 的透明电子外壳。看到页面标注最小壁厚 0.8 mm、精度 ±0.1 mm，请确认这种大小的薄盖是否适用、精度是否包含打磨喷涂后的尺寸，以及能保证的平整度。请提供树脂具体型号，并说明全透明效果包含哪些后处理。希望先做薄壁小样，再做银行卡大小的浅壳验证，请按模型分别报价。

## 本项目下一步

按上述两步安排验证透明 SLA；成品透明/半透明薄面板可作为外观与薄度参照。待 AI Passport 到货后，可观察分型线、内侧标识、顶出痕和面板结构作参考；这些观察仍不一定能确定具体树脂牌号。

软件仍按已有约定安装前讨论。当前只新增工艺研究，没有打印、开模、外包询价或采购。

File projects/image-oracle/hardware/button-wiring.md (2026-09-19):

# 五向按键：中心键与屏幕共地

## 已确认与待验证

2026-09-19，用户提供一块绿色导航按键板的近照；照片中排针从上到下为 `COM UP DWN LFT RHT MID SET RST`。中央按杆有四向和按下操作，另外有 SET、RST 两个独立按钮。COM／MID 接法已通过计数和定格交互验证；具体厂家、PCB 版本及其他触点尚未逐项核对。

当前主板为已验证的 ESP32-S3-CAM N16R8。GPIO14 未被相机、屏幕或原生 USB 占用；屏幕接线保持[原表](display-wiring.md)。方案采用 GPIO14 内部上拉，COM 接 GND，按下 MID 时预期读到 LOW。该接法不向按钮板连接 VCC，也不需要外接上拉电阻。

## 共地接线

先拔掉 USB。准备三根母对公杜邦线和一根母对母杜邦线：母头是带孔插座，套模块排针；公头露出金属针，插面包板。

1. 拆下原来直接连接主板 GND 与屏幕 GND 的母对母线，其余七根屏幕线保留。
2. 三根母对公线分别连接：主板 GND → a5、屏幕 GND → b5、按键 COM → c5。
3. 一根母对母线连接：按键 MID → 主板丝印 `14`。
4. 其他按键脚悬空；不要将主板 3V3 或 5V 插进这个共地孔组。

```text
主板 GND ── a5 ┐
屏幕 GND ── b5 ├── 同一块内部金属片：a5、b5、c5、d5、e5
按键 COM ── c5 ┘

按键 MID ───────── 主板 GPIO14
```

孔号只是便于说明：选择普通接线区任意一组相通的五孔即可，不需要使用两侧电源轨。典型 a～j 面包板中，同编号 a～e 相通；a5 与 a6 不通，e5 与跨中间沟的 f5 也不通。三根线插三个不同孔，不把线挤进同一个孔。实物编号或方向不同时，先对照孔组与中间沟。

主板若按金属屏蔽罩朝前、天线朝上、两个 USB 口朝下摆放，`14` 在左排倒数第二针，其下是 `5V`；仍以实物丝印为准。按键板的 RST 只是一个按钮触点，本实验不接主板 EN/RST。

## 程序与验收

[屏幕程序](../firmware/display_serial/README.md)已增加中心键计数：10 ms 消抖，每次按下加一，长按不连加，重启归零。2026-09-19 用户已实际操作按键，报告旧版快速连按漏计数、整屏刷新明显；基本按键路径已验证。

用户确认独立采样版计数不再丢失，但持续按压后画面延迟；已进一步烧录 `revision=button-counter-usb-nonblocking`，修正无串口读取端时 USB 日志阻塞绘图的问题。实机压力测试通过，接线不变；用户持续连按复测确认“始终跟手，问题解决”。长按不连加的实物专项验收仍待补充，详见[按键启动记录](../docs/button-bringup.md)。

原显示测试程序的源码和烧录文件保留于被忽略的 `artifacts/firmware/display-smoke-20260919/`，附 SHA-256 清单；完整原厂备份及相机基线仍保留。

当前板上运行第三个 [oracle_live](../firmware/oracle_live/README.md) 程序，沿用同一接线；MID 将左侧预览定格到右侧并更新答案，用户已确认交互正常。

## 依据

- 用户提供的按键正面丝印照片，以及项目现有相机与屏幕 GPIO 配置。
- [同类八针模块说明](https://sensorembedded.com/index.php?filename=5D+ROCKER+JOYSTICK.pdf&route=extension/module/document/download)：用于交叉核对 COM 与七个触点的含义，不作为实物 PCB 版本或实测结果。
- [Arduino-ESP32 GPIO 文档](https://docs.espressif.com/projects/arduino-esp32/en/latest/api/gpio.html)：`INPUT_PULLUP` 与 `digitalRead()`。
- [SparkFun 面包板结构说明](https://learn.sparkfun.com/tutorials/how-to-use-a-breadboard/all)。

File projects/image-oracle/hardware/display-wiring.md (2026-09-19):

# 1.54 寸 SPI 屏幕接线

## 确认范围与当前状态

2026-09-19，用户确认实物屏幕的八针标注依次为 `GND VCC SCL SDA RST DC CS BL`，与已购套装的屏幕参数图一致。商家图标注 `1.54TFT-SPI-ST7789 Ver:1.1`、240×240、供电 2.8～3.3 V；实物背面型号／版本文字尚未独立核对。

下表是为当前 ESP32-S3-CAM N16R8 项目分配的接线方案。用户已报告按表完成连接；[屏幕测试固件](../firmware/display_serial/README.md)构建、烧录及写入校验通过，USB 状态确认应用运行，用户也已目视确认测试画面显示。没有新增接线或背面照片，具体 PCB 版本未独立核对；该接法已通过当前实物的基本显示测试。

## 母对母杜邦线直连

先拔掉 USB，保持摄像头排线不动。按两块板上的丝印逐根连接；GPIO 编号不是排针的物理顺序。

| 屏幕丝印 | 主板丝印 | 固件中的信号 | 用途 |
| --- | --- | --- | --- |
| GND | GND | — | 共地 |
| VCC | 3V3 | — | 3.3 V 供电，不能接 5V |
| SCL | 40 | SCK = 40 | SPI 时钟 |
| SDA | 41 | MOSI = 41 | 主板发送显示数据 |
| RST | 21 | RST = 21 | 屏幕复位，不接主板 EN／RST |
| DC | 47 | DC = 47 | 数据／命令选择 |
| CS | 42 | CS = 42 | SPI 片选 |
| BL | 38 | BL = 38 | 背光，沿用套装教程的 GPIO38 接法 |

SCL／SDA 在该屏幕上是 SPI 信号，不是 I2C；本屏幕不需要连接 MISO。BL 方案依据同套装教程，不能推广到任意八针屏幕或裸背光 LED。

用八根较短的母对母杜邦线即可，电源线优先红色、地线优先黑色，其余颜色自行区分。本次不需要面包板分电源。暂不插 SD 卡：GPIO38、40 同时连到板载 SD 接口，后续启用 SD 时必须重新规划。

## 为什么重新分配 GPIO

- 当前已验证的相机占用 GPIO4～13、15～18。
- 当前使用原生 USB，保留 GPIO19／20；商家屏幕教程的 19／20 分配不能照搬。
- OPI PSRAM 使用的 GPIO33～37 不分配给外设；启动配置引脚 GPIO0、3、45、46 也不用于本次接线。
- 商家使用 GPIO45 作 CS，本项目改用 GPIO42。GPIO40、41、42、21、47、38 均可从用户提供的主板近照辨认到对应排针。
- 这些 GPIO 由后续固件明确配置；不是屏幕只能使用这些编号，也不是商家固件的默认接法。

## 验证与后续接线

1. 首次接线和以后改线均先断电，按两端丝印核对。
2. 屏幕基本显示和中心键交互已验证；加入按键后的 GND 改为通过面包板与 COM 共地，见[按键接线表](button-wiring.md)。其余七根屏幕线保持本表接法。
3. 当前第三个程序已经整合相机、屏幕与按键，用户确认预览、定格、方向和颜色正常，见[整合记录](../docs/oracle-bringup.md)。原始独立屏幕测试见[屏幕启动记录](../docs/display-bringup.md)。

文档检查命令：

```sh
git diff --check
```

## 依据

- [商家套装资料及版本差异](../docs/vendor_resources.md)，包括本地套装参数图和 revision 819 的接线教程。
- [当前相机 GPIO 配置](../firmware/camera_serial/camera_serial.ino)。
- [Espressif ESP32-S3 GPIO 说明](https://docs.espressif.com/projects/esp-idf/en/stable/esp32s3/api-reference/peripherals/gpio.html)。

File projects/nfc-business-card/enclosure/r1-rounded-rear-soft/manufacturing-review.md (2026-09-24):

# 圆角外壳打印与 SWD 烧录评审

## 当前确定方案

2026-09-24：保留正面＋侧壁一体、内嵌独立底盖和五个 SWD 小孔。圆角形状适合询价 SLA 透明树脂；**当前模型可用于工艺评审，尚不满足直接作为成品下单的条件**。主要未决项是薄板平整度、涂层后的配合、底盖定位胶接和键帽轴向公差。本次只读复核 CAD，没有修改 PCB、壳体几何或发起订单。

## CAD 复核结果

用 [只读脚本](../review-r1-print.py) 在 FreeCAD 1.1.3 重开保存文件，结果见 [测量证据](print-review.json)。上壳、底盖和三个键帽均有效且各为一个实体；两份壳体 STL 封闭，上壳与底盖无体积干涉，源文件哈希未变。原有 [装入与键帽移动检查](report.json)仍是名义几何证据，不是打印精度或实物装配验收。

| 部位 | 当前几何 | 工艺判断与下一步 |
| --- | --- | --- |
| 整体圆润外观 | 85.2 × 53.2 × 5.8 mm；正面 R1.2、背面 R0.7、俯视 R3.2 | 圆角本身不是限制。可用 SLA 加后处理；外观面支撑位置、打磨和透明涂层需与供应商约定。 |
| 大面与侧壁 | 面板 0.8 mm、侧壁 1.2 mm；底盖 82.3 × 50.3 × 0.8 mm | 大面积薄底盖的翘曲、刚度和打磨损耗是主要风险；不能只用最小壁厚判断。加厚方案必须重新算内部堆叠，不能直接向内加料。 |
| 背面窄框 | 圆角之间直边平面带 0.42 mm | 这是局部平面带宽度，不是整面侧壁壁厚。需要确认该处后处理不会削坏轮廓。 |
| 底盖接缝 | 单边 0.25 mm，入口微圆角使表面缝口约 0.41 mm | 接缝已内移到底面平面，仍会可见。间隙尚未覆盖尺寸误差、翘曲和涂层；需按成品状态配合验收。 |
| 底盖固定 | 没有卡扣、定位台阶或螺钉 | 当前需要外部定位治具与竖向胶接；胶种、结合面及固化定位未定。不能仅凭装配图认为底盖会自行保持齐平。 |
| PCB 装入 | 板到上壳最小距离 0.512535 mm | 原模型装入检查通过。若增加整圈向内承台 0.5 mm，直边只剩约 0.013 mm 名义余量，因此不建议直接加整圈承台。 |
| 五个调试孔 | 直径 2 mm、中心距 3 mm、穿过 0.8 mm 底盖 | 保留。要求后处理后通孔畅通；孔不代替探针定位夹具，也不是泄液孔。上下壳分开打印，内部本来就是开放的。 |
| 三个键帽 | 每个约 6.8 × 6.8 × 2.25 mm；可见头直径 4 mm、孔径 5.2 mm | 小件接单与支撑去除须单独确认。径向名义余量充足，轴向距壳仅 0.05 mm，接触开关的初始间隙也约 0.05 mm，需重做公差与回弹验证。 |

尺寸测量注意：FreeCAD 的普通 `BoundBox` 会对本模型部分样条圆角给出偏大的保守包围盒。本次另以 0.005 mm 曲面离散检查外形，得到约 85.2 × 53.2 × 5.80025 mm，底盖 82.3 × 50.3 × 0.8 mm；此近似核对不能当作加工精度。

供应商资料的适用边界：JLC3DP 国际站的 [设计指南](https://jlc3dp.com/help/article/3d-printing-design-guideline)建议随面尺寸增大壁厚，50 × 50 mm 与 100 × 100 mm 的 SLA 表列建议分别为 1.0、1.5 mm；100 mm 内一般尺寸公差 ±0.2 mm、孔 ±0.3 mm，并排除翘曲和喷涂影响。其 8001 最小零件尺寸表也不能直接覆盖本键帽。以上是询价参考，**不是国内站对本件的承诺或统一强制阈值**。

以底盖 X 向为例，开口 82.8 − 底盖 82.3 = 0.5 mm 总间隙。若供应商将开口按 ±0.3 mm、底盖按 ±0.2 mm 验收，最坏总间隙可到零，尚未计涂层。这是保守公差算例，开口分类须由实际供应商确认，不能简单保证“单边 0.25 足够”。

[PCBWay 透明件说明](https://www.pcbway.com/helpcenter/3d_engineering_questions/Wall_thickness_requirements_for_transparent_materials.html)建议至少 0.8 mm，但也明确打磨与清漆处理可能造成破损或变形，并会单独评估是否需要加厚。因此达到 0.8 mm 不能证明这块大底盖合格。

## 推荐询价平台与交付内容

1. **优先询价 [嘉立创 3D 国内站](https://www.jlc-3dp.cn/placeOrder)：SLA、8001 透明树脂。** 国内站有 [8001 材料介绍](https://www.jlc-3dp.cn/technicalColumnsDetails/60901.html)。明确询问打磨、透明处理、薄板平整度与配合面处理。[国际站 8001 说明](https://jlc3dp.com/help/article/photosensitive-8001-resin)区分透明件的打磨与喷油、半透明件的仅去支撑，国内订单需确认具体包含哪些工序。光滑与完全无纹、光学透明不是同一个承诺。
2. **备选 [PCBWay 3D 打印](https://www.pcbway.com/rapid-prototyping/3d-printing/)：SLA、UTR-8100 transparent。** 用相同图纸询价比较；该平台的 DLP 精度说明不能直接套给 SLA 透明材料。

目前目录内 `upper.stl`、`rear.stl` 可供壳体评审，`rear-cover-study.step` 仅含两件壳体；完整 FCStd 中才有三个圆角键帽。正式交付前须另导出键帽，并确认独立小件或供应商指定的连接架方案；不能上传整个含电路板的装配 STEP 当一个打印件。旧键帽导出不代表此次圆角版本。

可复制的供应商评审说明（尚未发送）：

> 外壳外形 85.2 × 53.2 × 5.8 mm，顶面与侧壁一体、独立内嵌底盖，外露面圆角；希望透明、平滑。侧壁 1.2 mm、面板及底盖 0.8 mm，底盖约 82.3 × 50.3 mm，单边装配间隙 0.25 mm，背面有五个直径 2 mm 通孔。请评估薄底盖平整度、局部窄边打磨风险、最终涂层后的装配间隙及通孔，并说明外观面支撑和后处理方式。另有三个约 6.8 × 6.8 × 2.25 mm 键帽，需要确认小件可制造性。当前底盖胶接定位和按键轴向公差仍在设计中，本轮先做工程评审，不按成品直接生产。

打印工艺确认后，先做一套结构样件试装，再收敛透明外观。试装应包含按键反复按压回弹、底盖齐平与固定、USB 插头、屏幕排线、电池导线及铁氧体。当前圆角候选沿用冻结元件模型，**没有验证最新 B 焊盘导线与 0.25 mm 铁氧体**，见 [高度交接](../r1-height-handoff.md)。

## SWD 自己烧录需要什么

本板主控是 Raytac MDBT50Q-P1MV2 模组中的 nRF52840。首批开发建议保留自己烧录能力，后续改程序会经常使用。

- 支持 nRF52840、3.3 V 目标电压及 macOS 的 SWD 调试器，例如 SEGGER J-Link；配对应 USB 线、SWD 转接线。选具体型号后再核对供电方式和接头。
- 接触五个焊盘的弹簧探针和定位夹具。焊盘约直径 1.2 mm、间距 3 mm；壳孔直径 2 mm。不要把常见 2.54 mm 排针夹具当成可直接使用。搜索词：`SWD J-Link nRF52840`、`Pogo Pin 弹簧探针 烧录治具`。早期未封壳时也可临时焊细线调试。
- Nordic 工具链与适配本板的固件。仓库目前只有 ESP32-S3 外接 PN532 的实验程序，没有本成品板固件、已验证 bootloader 或可交付烧录镜像。不能承诺直接插 USB-C 更新。

按 PCB 原生 X 递增方向的接口映射（背面观察可能镜像）：

| X / Y，约 mm | 焊盘网络 | 调试器连接 |
| --- | --- | --- |
| 65 / 48.5 | GND | GND |
| 68 / 48.5 | VDD_3V3 | VTref，目标电压参考；不能当成 5 V 输入 |
| 71 / 48.5 | SWDCLK | SWCLK |
| 74 / 48.5 | SWDIO | SWDIO |
| 77 / 48.5 | NRESET | RESET |

板子需按确认后的方案供电；VTref 的电压检测用途与调试器供电输出要区分。Nordic 的 [自定义板烧录连接说明](https://nrfconnectdocs.nordicsemi.com/ncs/latest/nrf/app_dev/device_guides/custom/programming_custom_board.html)列出 SWD 信号、参考电压和供电要求。本次没有连接设备或烧录。

## PCB 工厂能否代做

可以询价 PCB 制板、SMT 贴装，以及额外的固件烧录服务。[嘉立创 SMT 国内下单页](https://www.jlc-smt.com/order?smtOrderSource=pcb)有“程序烧录／贴装后烧录”选项；**是否接受本模组及五焊盘针床仍须工程确认**。通常准备模块/MCU 型号、焊盘坐标与接线、供电说明、已验证 HEX/BIN、操作和验收说明。国际站的 [代烧录资料要求](https://jlcpcb.com/help/article/pcba-programming-service)可作准备参考，其套餐与收费不套用国内订单。

工厂负责写入提供的程序，固件开发和功能验收仍需要完成；烧录成功也不代表 NFC、屏幕、按键和充电都通过。当前缺成品固件，PCB 文档还记录 C1 位置待处理，见 [PCB 评审](../../hardware/pcb-r1-review.md)，不能视为已准备好整机生产。

## 复核命令

从仓库根目录运行，输出路径必须尚不存在：

```sh
NFC_PRINT_REVIEW_OUT="$PWD/projects/nfc-business-card/artifacts/print-review-new.json" \
PYTHONHOME=/Applications/FreeCAD.app/Contents/Resources \
PYTHONPATH=/Applications/FreeCAD.app/Contents/Resources/lib \
/Applications/FreeCAD.app/Contents/Resources/bin/freecadcmd \
  projects/nfc-business-card/enclosure/review-r1-print.py
```

检查报告是否完整写出及断言结果，不能仅看 FreeCAD 退出码。本次还目视检查了已有背面渲染；没有重新渲染或实物打印。

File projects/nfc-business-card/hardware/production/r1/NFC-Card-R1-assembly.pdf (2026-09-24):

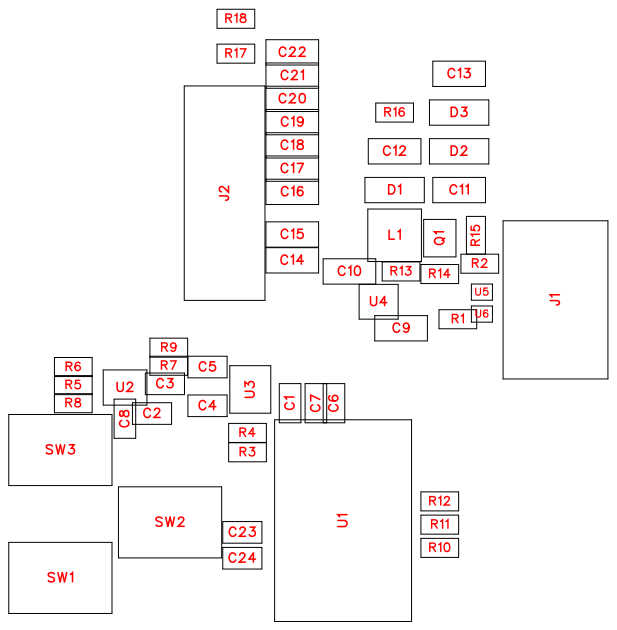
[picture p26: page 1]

U4 | U5
C9 | R1 | U6

No. | Quantity | Comment | Designator | Footprint | Value | Manufacturer Part | Manufacturer | Supplier Part | Supplier
1 | 4 | 2.2uF 16V | C1,C3,C4,C5 | C0603 | 2.2uF | CL10A225K O8NNNC | SAMSUNG( ) 三星 | C23630 | LCSC
2 | 2 | 10uF 10V | C2,C6 | C0603 | 10uF | CL10A106KP 8NNNC | SAMSUNG( ) 三星 | C19702 | LCSC
3 | 1 | 100nF 50V | C7 | C0603 | 100nF | CC0603KRX 7R9BB104 | YAGEO(国巨 ) | C14663 | LCSC
4 | 1 | 4.7uF 16V | C8 | C0603 | 4.7uF | CL10A475K O8NNNC | SAMSUNG( 三星 ) | C19666 | LCSC
5 | 11 | 1uF | C9,C10,C11,C12,C13,C16, C17,C18,C20,C21,C22 | C0805 | 1uF | CL21B105KB FNNNE | SAMSUNG( 三星 ) | C28323 | LCSC
6 | 3 | 4.7uF | C14,C15,C19 | C0805 | 4.7uF | CL21B475KA FNNNE | SAMSUNG( ) 三星 | C98195 | LCSC
7 | 2 | 220pF C0G (tune) | C23,C24 | C0603 | 220pF | GRM1885C1 H221JA01D | muRata(村田 ) | C77032 | LCSC
8 | 3 | MBR0530T1 G | D1,D2,D3 | SOD-123_L2 .7-W1.6-LS3. 7-RD-1 | | MBR0530T1 G | onsemi(安森 美) | C82046 | LCSC
9 | 1 | USB4500-03-0-A | J1 | USB4500 E20 Routed Cutout | | USB4500-03-0-A | GCT | C5354966 | LCSC
10 | 1 | FPC-05FB-2 4PH20 | J2 | FPC-SMD_2 4P-P0.50_FP C-05FB-24P H20 | | FPC-05FB-2 4PH20 | XUNPU(讯普 ) | C2856831 | LCSC
11 | 1 | 47uH | L1 | IND-SMD_L3 .0-W3.0 | 47uH | NRH3010T4 70MN | TAIYO YUDE N(太诱 ) | C223116 | LCSC
12 | 1 | SI1308EDL-T 1-GE3 | Q1 | SOT-323_L2. 0-W1.3-P1.3 0-LS2.1-BR | | SI1308EDL-T 1-GE3 | VISHAY(威世 ) | C469327 | LCSC
13 | 2 | 5.1k 1% | R1,R2 | R0603 | 5.1k | 0603WAF51 01T5E | UNI-ROYAL( 厚声 ) | C23186 | LCSC
14 | 3 | 0 | R3,R4,R16 | R0603 | 0 | 0603WAF00 00T5E | UNI-ROYAL( ) 厚声 | C21189 | LCSC
15 | 8 | 10k 1% | R5,R6,R7,R8,R9,R10,R11, R12 | R0603 | 10k | 0603WAF10 02T5E | UNI-ROYAL( ) 厚声 | C25804 | LCSC
16 | 1 | 100k | R13 | R0603 | 100k | 0603WAF10 03T5E | UNI-ROYAL( 厚声 ) | C25803 | LCSC
17 | 2 | 10k | R14,R18 | R0603 | 10k | 0603WAF10 02T5E | UNI-ROYAL( 厚声 ) | C25804 | LCSC
18 | 1 | 2.2 | R15 | R0603 | 2.2 | 0603WAF22 0KT5E | UNI-ROYAL( 厚声 ) | C22939 | LCSC
19 | 1 | 3 | R17 | R0603 | 3 | 0603WAF30 0KT5E | UNI-ROYAL( ) 厚声 | C23157 | LCSC
20 | 3 | SKQGABE01 0 | SW1,SW2,SW3 | KEY-SMD_4 P-L5.2-W5.2-P3.70-LS6.4 | | SKQGABE01 0 | ALPSALPIN E(阿尔卑斯阿 ) 尔派 | C115351 | LCSC

21 | 1 | MDBT50Q-P 1MV2 | U1 | COMM-SMD _MDBT50Q-1MV2 | MDBT50Q-P 1MV2 | RAYTAC | C5119772 | LCSC
22 | 1 | BQ25186DL HR | U2 | WSON-10_L 2.2-W2.0-P0. 40-BL-EP_TI _DLH0010A | BQ25186DL HR | TI(德州仪器 ) | C44639442 | LCSC
23 | 1 | TPS7A0233 DBVR | U3 | SOT-23-5_L2 .9-W1.6-P0.9 5-LS2.8-BL | TPS7A0233 DBVR | TI(德州仪器 ) | C5142805 | LCSC
24 | 1 | TPS22919D CKT | U4 | SC-70-6_L2. 0-W1.3-P0.6 5-LS2.1-BR | TPS22919D CKT | TI(德州仪器 ) | C2860814 | LCSC
25 | 2 | TPD2EUSB3 0DRTR | U5,U6 | SOT-9X3-3_ L1.0-W0.8-P 0.35-LS1.0-B R | TPD2EUSB3 0DRTR | TI(德州仪器 ) | C97502 | LCSC

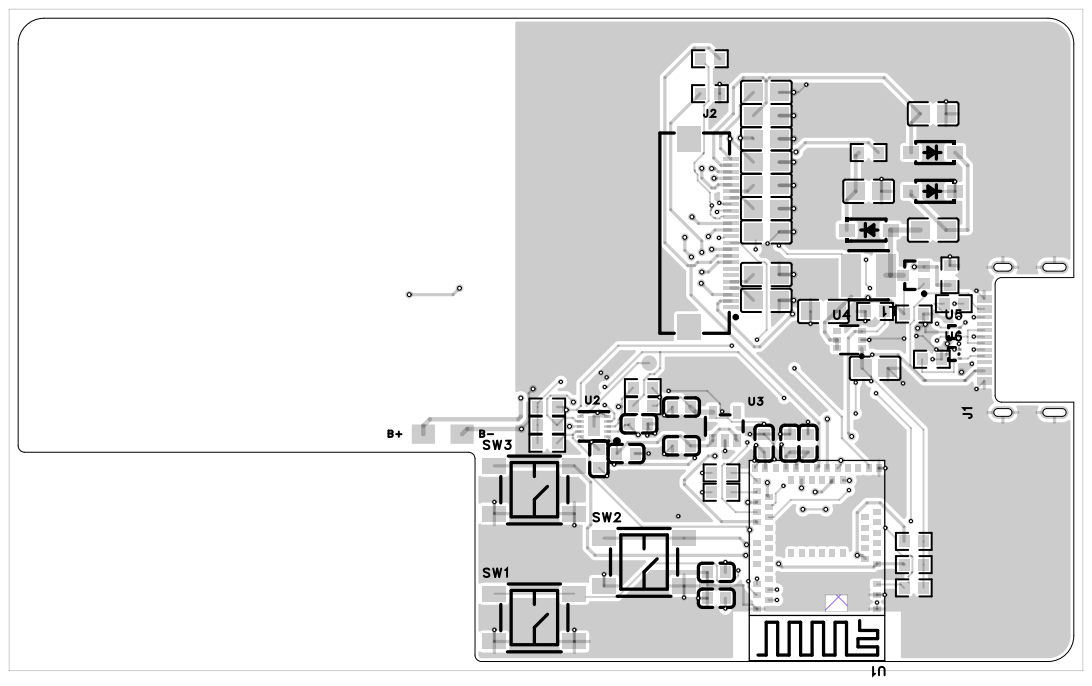
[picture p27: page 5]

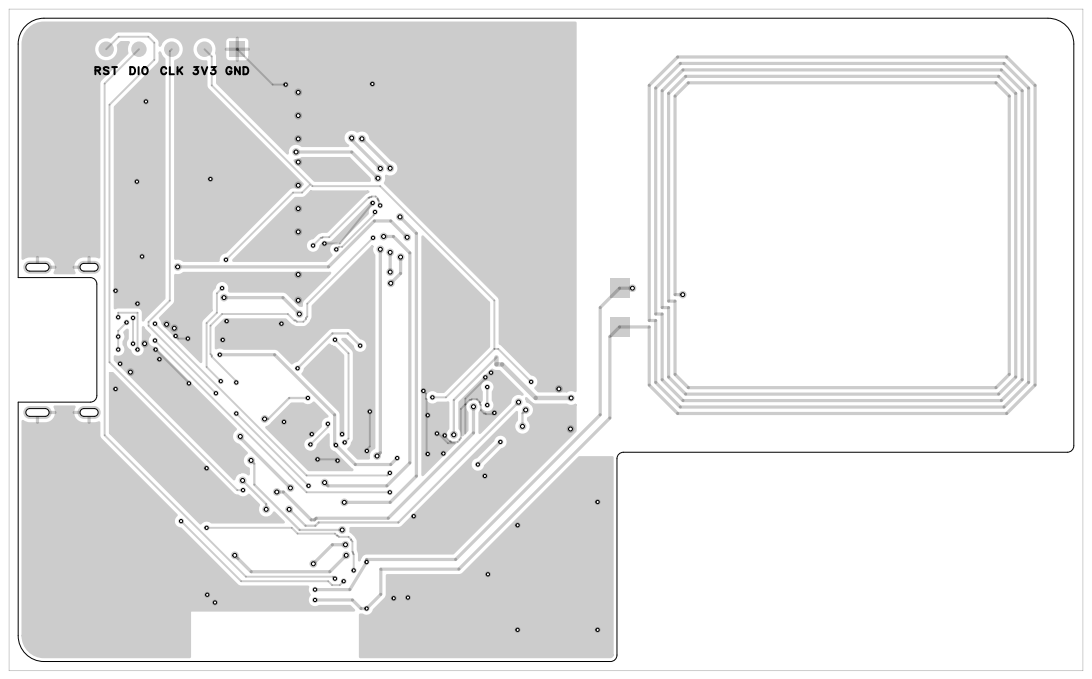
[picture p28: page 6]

RST DIO CLK 3V3 GND

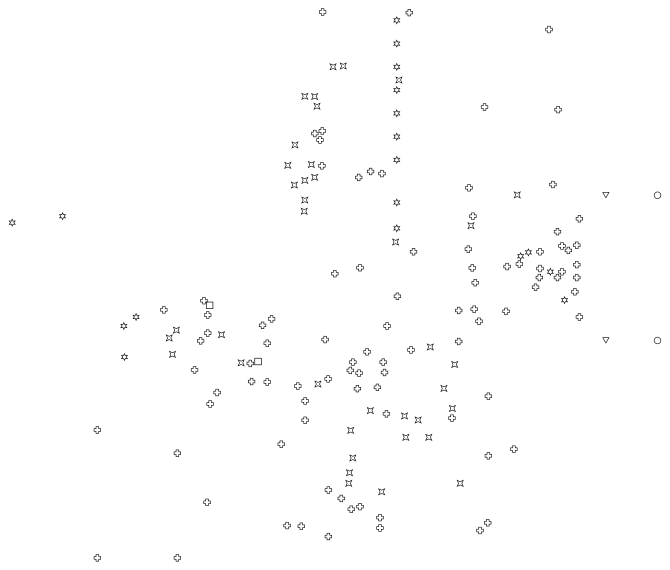
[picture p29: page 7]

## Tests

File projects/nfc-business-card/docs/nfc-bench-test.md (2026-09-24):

---
description: 使用 ESP32 与 PN532 或 nRF52840 开发板，先验证按键切换 NFC 名片的手机体验
last_updated: 2026-09-23
status: hardware_received_not_tested
---

# NFC 最小桌面实验

用户希望复用此前 ESP32 面包板经验，先确认 NFC 能否达到预期效果，再投入定制生产。这项实验补充现有 PCB/PCBA 主线，不将最终主控改为 ESP32；PN532 已到货，尚未接线或实测。

## 已选实验模块

2026-09-20 用户选择淘宝「深圳市优信电子科技有限公司」商品中的 **PN532_NFC模块_蓝板**，并确认该选项排针已焊好。2026-09-23 用户确认到货并提供正反面照片：可见 PCB 天线、已焊双排针、SET0/SET1 开关，以及另一排印有接口名称的未焊孔位。其外观接近 ITEAD PN532 NFC Module，但实物版本和双排针针序尚未独立确认。商品图标称约 79 × 49 mm；不把桌面模块的尺寸计为最终名片设计。

商家提供的说明标注 SPI 为 3.3 V 逻辑，I2C/UART 为 5 V TTL，因此实验优先核对 SPI 接口；它与所引用例程默认 HSU 接口不同，实现时需要调整驱动配置。ITEAD 同外观模块的[原厂规格书](https://www.openimpulse.com/blog/wp-content/uploads/wpsc/downloadables/PN532-NFC-Module-Datasheet.pdf)列出 SPI 模式为 SET0=L、SET1=H，但具体供电和双排针位置仍须按实物或可靠资料核对。照片中带 SCK 等丝印的一排是未焊孔位，不能直接按其位置推断已焊双排针的针序。当前没有已验证的 GPIO 分配或实测手机读取结果。

桌面测试复用 [Image Oracle 的 ESP32-S3-CAM N16R8](../../image-oracle/README.md)。其现有 `oracle_live` 固件、相机、TFT 和按键已验证；先在 USB 断电后拆下 TFT 的八根连接线并保留相机排线，不需要为拆屏而擦除固件。测试 PN532 与墨水屏转接板时逐个接入、分别构建和烧录测试程序；新程序烧录后原程序不再运行，恢复文件已归档于 Image Oracle 项目。墨水屏裸屏不能直接接 GPIO，必须先确认随附转接板型号、FPC 插入方向和接口丝印。

## PN532 双排针与拟接线（未通电验证）

照片左侧的已焊 **2×13 双排针**是 Raspberry Pi 26 针接口；照片左右镜像，不能直接按屏幕上的左右方向数针。[ITEAD 原厂规格书](https://www.openimpulse.com/blog/wp-content/uploads/wpsc/downloadables/PN532-NFC-Module-Datasheet.pdf)第 2 页的板卡图与实物布局相符，[原厂连接示例](https://itead.cc/nextion/raspberry-pi-drives-itead-pn532-nfc-module-with-libnfc/)用 26 芯排线连接 Raspberry Pi。板边标 `SCK / MI / MO/SDA/TX / NSS/SCL/RX / IRQ / RST# / GND / 5V` 的八孔是另一个接口，用户这块尚未焊排针。不要把八孔丝印逐行套到双排针上。

以下按该双排针遵循标准 Raspberry Pi 26 针排布**推导**，尚未在用户实物上量通断。将板正面 `NFC` 字样摆正、天线置左、双排针置右；原厂图中双排针靠上、靠天线一侧的**方形焊盘为 1 号脚**，相邻靠板外缘的是 2 号脚，往下逐排递增。从背面看会左右反转，因此以双排针自身的方形焊盘定位，不以照片左右定位；顶部另一组单排孔也有方形焊盘，不能拿来当双排针 1 号。若实物看不清方形焊盘或方向不符，先暂停接线。Raspberry Pi 物理针序与 SPI 信号取自[官方 GPIO 文档](https://www.raspberrypi.com/documentation/computers/raspberry-pi.html#spi)。ESP32 的 40/41/42 是拆除 TFT 后释放的原已验证引脚；39 在这块 ESP32 板的排针上，但尚未验证作 PN532 MISO。

| PN532 双排针物理脚 | 预期信号 | ESP32-S3-CAM 丝印 | 状态 |
| --- | --- | --- | --- |
| 2 | 5 V 供电 | `5V` | 待实物核对 |
| 6 | GND | `GND` | 待实物核对 |
| 19 | MOSI | `41` | 拟接 |
| 21 | MISO | `39` | 拟接 |
| 23 | SCK | `40` | 拟接 |
| 24 | CE0 / NSS | `42` | 拟接 |

按**双排针从方形焊盘所在的第一排开始**，13 排逐排数如下；`—` 表示本次不接，列位置随正反面观察会互换：

| 从方形焊盘开始的排数 | 方形焊盘所在列：奇数脚 | 相邻列：偶数脚 |
| --- | --- | --- |
| 1 | 1 — | **2 → ESP32 `5V`** |
| 2 | 3 — | 4 — |
| 3 | 5 — | **6 → ESP32 `GND`** |
| 4 | 7 — | 8 — |
| 5 | 9 — | 10 — |
| 6 | 11 — | 12 — |
| 7 | 13 — | 14 — |
| 8 | 15 — | 16 — |
| 9 | 17 — | 18 — |
| 10 | **19 → ESP32 `41`** | 20 — |
| 11 | **21 → ESP32 `39`** | 22 — |
| 12 | **23 → ESP32 `40`** | **24 → ESP32 `42`** |
| 13 | 25 — | 26 — |

只需六根母对母杜邦线；IRQ、RST# 和其余双排针暂不接。SET0 拨到板上 `L`、SET1 拨到 `H`，对应 SPI。先断 USB、拆 TFT；准备并烧录专用 PN532 测试固件后再次断 USB，逐根核对供电与信号再接模块，最后重新上电。不要把 5 V 接到任何 ESP32 GPIO，也不要在通电时改线。若不想使用双排针，也可给板边八孔焊一排单列排针后按丝印连接；未焊孔不能靠松插导线作可靠测试。

## 实验目标与术语

目标：程序选择名片 A/B，设备呈现对应的 NDEF HTTPS URI；手机靠近后读到当前链接，移开、切换、再次靠近后读到新链接。先用 USB 供电和串口显示状态，之后增加一个按键；墨水屏、电池与薄壳不参与第一轮。

要找的是卡模拟/标签仿真（Card Emulation / NFC Tag Emulation），不能只搜「主动 NFC」。主动产生射频场的读卡器功能不等于本项目需要的被读取标签功能。NDEF URI 是本次验证载荷，不涉及门禁凭据或任意 UID 模拟。

## 两条可买现成硬件的路线

| 路线 | 所需硬件 | 能验证什么 | 与最终定制板的差异 |
| --- | --- | --- | --- |
| **复用 ESP32** | 空闲 ESP32 + 带天线的 PN532 开发模块 + 导线，按键可后加 | 卡模拟、程序更换 NDEF、手机提示及打开链接体验 | Seeed 例程使用 Type 4 标签模拟，最终计划是 nRF52840 Type 2；驱动、功耗和天线距离不直接迁移 |
| 同主控验证 | 普通版 XIAO nRF52840 + 已验证配套 NFC 天线，或带天线的 nRF52840 DK | 更接近最终主控的 Type 2 标签行为、内容切换及恢复 | 板级天线/布局仍不同，最终装壳要重测；XIAO 天线通常需要焊接 |

希望沿用手头 ESP32 时，PN532 是合理的交互实验选择。若准备专门买主控且希望直接验证最终架构，优先比较 nRF52840 开发板。不要同时采购两套完整设备作为默认要求。

## PN532 购买与软件依据

- 候选类别：带板载天线、可选择 HSU/UART、SPI 或 I2C 的 PN532 模块；优先有明确板卡版本、原理图和卡模拟例程的型号。若只做桌面实验，可选焊好排针的版本。
- [Seeed PN532 库](https://github.com/Seeed-Studio/PN532) 明确列出 NFC Type 4 卡模拟，README 也有 ESP32 硬件串口支持说明。
- [emulate_tag_ndef 例程](https://github.com/Seeed-Studio/PN532/blob/arduino/examples/emulate_tag_ndef/emulate_tag_ndef.ino) 使用 URI 记录、NDEF 缓冲区和 `EmulateTag`；当前源码默认启用 HSU。默认 `emulate()` 会阻塞，提供超时形式；加入按钮时需设计返回/会话边界，不能简单把按钮读取放在无限阻塞调用后。
- 「读卡 UID」例程不能作为本项目通过证据。需要运行标签模拟程序，使手机读取模块自己呈现的内容。
- [Elechouse PN532 V3 手册](https://www.elechouse.com/elechouse/images/product/PN532_module_V3/PN532_%20Manual_V3.pdf) 可作为支持虚拟卡模式的硬件参考；它是较早版本资料，不能直接用于所有淘宝同名兼容板。采购前确认实际电源和所选接口的逻辑电平，ESP32 GPIO 不因模块支持 5 V 供电就变成 5 V 容忍。

本轮只读文档与例程，未导入源码、安装依赖或构建。实现时固定库版本，按仓库约定保留来源/许可证；具体板卡未确认前不分配 GPIO、不绘制可直接接线的图。

## nRF52840 购买与软件依据

[Seeed NFC 指南](https://wiki.seeedstudio.com/XIAO-BLE-Sense-NFC-Usage/) 提供原生 Type 2 标签及网址例程，记录验证的 Seeed nRF52 Boards 1.1.13。普通 XIAO nRF52840/Sense 与 Plus 的 NFC 引脚默认配置可能不同；初次验证可优先普通版，减少 Plus 配置恢复的步骤。Sense 的传感器不是本实验必需。

指南列出 MOLEX 1462360051、TAOGLAS FXR.07.A.DG 天线的测试经验，但当前供应情况和最终距离未确认。天线是线圈及匹配问题，不能购买一张普通 NFC 标签贴纸当作裸天线直接连接。最终卡片的匹配仍按实际装配验证。

## 验收顺序

1. 固定一个普通 HTTPS 链接，先使用 NFC 读取工具确认收到有效 NDEF。
2. 不打开读取工具，检查手机系统是否提示以及点击后的页面；分别记录手机型号、系统版本、屏幕亮灭/锁定状态。URI、文本和 vCard 的系统处理不等价，不预设碰一下就自动保存联系人。
3. 从串口选择 A/B 两个可区分的 URI：手机移开 → 切换 → 再靠近，每次读到当前值；再把选择动作改成面包板按键。
4. 连续做至少 10 轮切换与读取，记录漏读、旧内容、耗时；手机一直贴着时切换单独记录，不假定手机会自动重新读取。
5. 用实际将使用的 iPhone/Android 分别验证。若目标还包括桌面读卡器，明确型号及读取软件后另测。

通过后可以确认交互方向，再在最终 nRF52840 固件和 PCBA 上重复核心测试。PN532 实验成功不能证明定制板的功耗、读距或 Type 2 兼容性；PN532 特定驱动失败也不能直接判定最终 nRF52840 路线不可行。

2026-09-23 已在 `/dev/cu.usbmodem1101` 用原 `oracle_live STATUS` 确认当前板卡；Image Oracle 恢复包八个文件的 SHA-256 校验均通过。新建 [PN532 SPI 探测固件](../firmware/pn532_probe/README.md)，使用 Adafruit PN532 1.3.4 与现有 ESP32 工具链构建通过，实机写入四段摘要校验通过；芯片识别为 ESP32-S3 v0.2，MAC 为 `68:ee:8f:4c:ff:b0`。烧录后串口 `STATUS` 返回 `PN532_PROBE_READY pins_idle=1`，证明原 `oracle_live` 已停止。**PN532 尚未接线或通电**；新固件只在收到 `PROBE` 时初始化 SPI。

当前缺口：PN532 双排针在用户实物上的 1 号脚方向、六线接入后的 SPI 应答、墨水屏转接板实物型号和接口、手机卡模拟体验。构建与烧录成功不是 PN532 功能验证。

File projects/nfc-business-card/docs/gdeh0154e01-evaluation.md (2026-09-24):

---
description: GDEH0154E01 六色屏原厂资料、示例代码核对及采购前缺口
last_updated: 2026-09-21
---

# GDEH0154E01 六色屏评估

用户当前取样选择为佳显 **GDEH0154E01 + DESPI-E01 转接板** 1 套，最新购物车截图优惠价 ¥63.3；此前 ¥36.9 截图对应裸屏。尚未确认付款或到货，价格不代表实时库存或最终结算。它作为 1.54 英寸彩色重点候选，尚未替换原理图中的黑白屏设计输入。

**2026-09-21 接口复核：公开规格书、转接板原理图和示例已找到，可继续原理图草案。** 已识别参考板插座 **FPC-05FB-24PH20 / C2856831** 并取得 XUNPU 图纸；实际 EDA 库封装的 79 项名义尺寸比较通过，优先继续评审该型号。当前 EDA/CAD 仍保留 FH12A 候选，未替换。引脚版本、外围参数差异、FPC 公差及刷新/电流规格仍需厂家与样品确认，不能直接投板。

## 电路落实进展（2026-09-21）

已在独立 [84 × 52 E6 工程](../archive/pre-r1/hardware/pcb-e6-84x52.md)接入 FPC-05FB-24PH20、TPS22919、DESPI 升压/负压外围和相应电容，保留原有方案。pin 1/6/7 按屏型号 NC，电容先按参考板作可调整选择；BUSY 极性、参考板/型号差异、刷新时间和峰值电流仍待样品验证。下面的资料审阅记录不应再理解为“所有疑点都阻止画电路”，也不能理解为已完成实测。

## 商家指定页面复核（2026-09-21）

用户转交商家的 [GDEH0154E01 英文产品页](https://www.good-display.com/product/983.html)。已从该页实际进入下载区，并重新下载[英文规格书入口](https://www.good-display.com/companyfile/2038.html)和[ESP32 示例入口](https://www.good-display.com/companyfile/2062.html)对应文件：

- 英文站规格书为 3,763,348 字节，SHA-256 与此前中文站缓存完全一致；不同 CDN 目录不代表新版本。
- ESP32 示例 ZIP 为 37,611,209 字节，SHA-256 也与既有缓存一致。
- 页面及其下载区没有补充本型号的刷新耗时、刷新峰值电流、BUSY 勘误或装配 BOM；原先缺口仍存在。页面提及集成 DC-DC，不代表外部电感、MOSFET、二极管和电容可以省略。
- 页面中标为 DESPI-E01 的文字链接实际指向 `/product/904.html`，打开后是 **DESPI-C169 / 30 pin**，不能混用该板资料。正确 [DESPI-E01 英文页](https://www.good-display.com/product/1087.html)为 24 pin；本项目沿用已核对的 DESPI-E01 中文说明书与电路图。

结论：商家链接确认了产品及公开资料入口，**没有消除文档差异或证明实物版本兼容**。可继续封装审核和原理图草案；不能将“收到官网链接”当成投板条件已满足。下载端点与文件比较记录位于 `artifacts/archive/gdeh0154e01-research/merchant-*.json`。

## 核对结果

| 项目 | 已查到的证据 | 当前判断 |
| --- | --- | --- |
| 屏幕 | 240 × 240、六色；官网显示区 27 × 27 mm | 适合头像、文字与身份图案；二维码可读性待实测 |
| 机械尺寸 | 屏幕规格书第 5 页：31.8 ±0.1 × 37.32 ±0.1 mm，厚度 0.85 ±0.15 mm；FPC 尾部约 14.3 ±0.3 mm | 屏体上界已纳入[独立样品排布](../archive/pre-r1/enclosure/pcba-e6-302030.svg)，插座、支撑及排线弯曲仍待细化 |
| 供电 | 规格书第 9 页 DC Characteristics：VDD 为 2.4–3.6 V，典型值 3.0 V | 与 3.3 V 供电方向相容；绝对最大值 6 V 不是允许的工作电压 |
| 完整刷新时间 | 规格书没有提供明确秒数；Arduino 与 ESP-IDF 示例的刷新超时均为 `120000 ms`，完成条件为 BUSY 释放 | **无法据此确定实际刷新时间**；120 秒是软件超时，不是刷新规格或实测值 |
| 局刷 | 已查两份驱动示例均采用整屏写入和 `0x12` 更新；未找到局刷实现或产品级局刷保证 | 目前按整屏更新评估；不能由“没找到”断言硬件绝不支持局刷 |
| 功耗 | 规格书第 9–10 页将工作电流、休眠电流、单次刷新电荷量标为 `TBD`；没有峰值电流规格 | 无法据此核算电源峰值和候选电池续航 |
| 连续翻页 | 产品页提供的 E6 通用设计须知第 3 页建议连续显示时设置 150 秒翻页间隔 | 是通用建议，不是单次刷新耗时，也不是本型号硬性最短间隔的证明；频繁按键切换场景需要厂家确认 |

结论：尺寸和资料入口支持继续评估，但**实际刷新耗时、允许翻页频率、局刷能力和峰值功耗仍未闭合**。不能仅凭销量、屏体薄度或低功耗宣传冻结采购及 PCB。彩色低频展示可以取样研究，要求连续快速切换身份时暂保留 GDEY0154D67 黑白方案。

## 示例代码的实际内容与限制

来源为[官方 ESP32 示例下载页](https://www.good-display.com/companyfile/2062.html)，页面跳转至厂商 CDN 压缩包。只做静态读取，未执行上游脚本、构建或烧录。

- `GDEH0154E01.ino` 第 11–13 行设置 240 × 240、4 bit/pixel，一帧为 28,800 字节；第 63–65 行分别设置初始化 15 秒、电源操作 60 秒、刷新 120 秒超时。
- `epdDisplayImage()` 第 407–442 行执行整帧写入、上电、`0x12` 更新、等待 BUSY、断开屏幕高压电源。ESP-IDF 版本有对应流程。
- 示例显示图片后另等待 3 秒再刷白。这个演示等待值既不是刷新耗时，也不能推翻 E6 通用翻页间隔建议。
- 包内 README / QUICK_START 仍写 GDEH037E01 和 480 × 720；源文件实际设置 240 × 240。不能把残留文档当成已验证的本型号配置。
- BUSY 检测失败后，代码会翻转极性，进一步失败时忽略 BUSY 继续；部分等待返回值未阻止后续命令。后续移植需要明确极性、让超时终止当前操作，不能直接复用这一降级行为作为正常驱动。
- 未发现可直接用于本项目的 nRF52840 工程；SPI 命令流程是可移植输入，不等于已完成兼容验证。

## 配套硬件与资料差异

[DESPI-E01](https://www.good-display.cn/product/748.html) 是官方配套驱动转接板。已取得说明书和独立电路图，其中包含 47 µH 电感、MOSFET、二极管、电容及 FPC 插座。因此裸屏依然需要外围电路，不能只把 24 pin 排线接到主控 GPIO。

以下差异须在画板前确认，当前不生成最终引脚表：

1. 屏幕规格书第 7 页写 BUSY 高电平为忙；转接板说明书印刷第 4 页（PDF 第 5 页）及示例默认使用低电平为忙。
2. 屏幕第 6 页把 pin 1、6、7 列为 NC；参考电路及转接板图出现 CS2、TSCL、TSDA 等标签，部分电容配置也不同。转接板同时适配两种屏幕，不能把图上所有连接直接移入本型号成品。
3. 转接板说明书印刷第 6 页（PDF 第 7 页）要求 **24 pin / 0.5 mm 的上接触或双面接触插座**。现有黑白草案的 FH12 底接触候选不能直接沿用；需结合 FPC 朝向、pin 1 和安装方向重新选择。

若取样，裸屏加 DESPI-E01 可用于桌面验证；转接板不计入最终薄名片方案。确认用户实际主控板、电压和引脚占用后再给接线方案。成品再把已验证的外围集成到定制 PCB。

## 接口与参考电路复核（2026-09-21）

以下是**公开资料之间的对照与拟连接关系**，不是交付屏幕的最终引脚表，也未写入 EDA 网表。依据屏幕 PDF 第 6–8 页、DESPI-E01 独立电路图及说明书 PDF 第 5、7 页；方向均须结合屏幕触点朝向与连接器 pin 1 重新核对。

| 屏幕 FPC 脚号 | 文档一致的功能 / 拟接项目网络 | 设计处理 |
| --- | --- | --- |
| 9 | BUSY → `EPD_BUSY_TBD` | MCU 输入；高忙/低忙的说明冲突尚未解决 |
| 10 / 11 / 12 | RESET / DC / CS → `EPD_RESET_N_TBD` / `EPD_DC_TBD` / `EPD_CS_N_TBD` | 主控输出；RESET、CS 低有效 |
| 13 / 14 | SCL / SDA → `EPD_SCK_TBD` / `EPD_MOSI_TBD` | 此处是 SPI 时钟/数据，不能因名称误接到 I2C |
| 15 / 17 | 电源 / VSS → 拟新增 `EPD_VDD` / GND | `EPD_VDD` 计划来自 U4 负载开关；不是锂电池直接供电 |
| 8 | BS0，选择 4-wire SPI 时为低 | 屏幕参考图用 0 Ω，DESPI-E01 用 3 Ω 接地；数值待确认 |
| 2 / 3 | GDR / RESE | 分别接升压 MOS 栅极控制与源极采样节点，不是额外 MCU GPIO |
| 4 / 5 / 16 / 18 / 19 / 20 / 22 / 24 | VDDL / VSPL1 / VSPL2 / VSNL1 / VSNL2 / VSPH / VSNH / VCOM | 屏幕外围电容节点，不是普通 3.3 V 信号 |
| 21 / 23 | VGP / VGN | 对应参考升压正、负输出 VGH / VGL（转接板标签 PREVGH / PREVGL） |
| 1 / 6 / 7 | 屏幕引脚表为 NC | 保持待确认且不连接；不能照转接板 CS2 / TSCL / TSDA 标签自动接入 |

4-wire SPI 是屏幕协议名称，桌面转接板还需 RESET、BUSY 和供电；DESPI-E01 的 H1 共 8 个引出信号。屏幕驱动电路集成到主板后，桌面 H1 排针不需要保留。

### 不能直接照抄的差异

| 项目 | GDEH0154E01 规格书 | DESPI-E01 原理图 | 当前处理 |
| --- | --- | --- | --- |
| pin 1 | 第 6 页 NC，第 7 页参考符号却写 CSB2 | CS2 标签，未连接 H1 | 同一规格书内部也不一致；问实际批次，先不连接 |
| pin 6 / 7 | NC | TSCL / TSDA，各画 10 kΩ 上拉，其中 R67 以灰色显示 | 灰色不能单独证明 DNP；索取装配 BOM，先不加这两个上拉 |
| BUSY | 第 7 页写高为忙 | 说明书与示例默认低为忙；电路只有 10 kΩ 上拉，没有反相器 | 冲突不能归因于板上反相；由厂家说明和实测波形确定 |
| pin 4 / 5 / 20 电容 | 第 7–8 页为 1 µF | C75 / C76 / C80 为 4.7 µF | **已定（2026-09-23）**：按 1.54 英寸版本取 1 µF；实际选料 `CL21B105KBFNNNE`（LCSC C28323）= 1 µF / **0805** / **X7R** / **50 V** / ±10%，容值与耐压都高于规格书下限（0603/X5R/25 V），封装放大到 0805 只为取料方便 |
| MOSFET | 第 8 页列 Si1304BDL / NX3008NBK（Vds ≥ 30 V、Vgs(th) 0.9 V typ / 1.3 V max、Rds(on) ≤ 2.1 Ω @ Vgs=2.5 V） | Q1 为 Si1308EDL | **已核对（2026-09-23，Vishay Rev C 数据表）**：Vds **30 V** ✓；Rds(on) @2.5 V 最大 **0.185 Ω**（要求 ≤2.1 Ω，约 11× 余量）✓；Vgs(th) 0.6–1.5 V，上限比规格书的 1.3 V 高 0.2 V，但在 2.5 V 栅压下仍有约 1 V 过驱动，且该型号正是 DESPI-E01 官方评估板在用的器件 → **接受该替换** |

两份图均有 47 µH 电感、三颗 MBR0530、2.2 Ω 采样电阻和 10 kΩ 栅极下拉。屏幕第 8 页还列出电感 NRH3010T470MN 和 0603 / X5R / 25 V 电容参考条件；这些是选料输入，不能代替电感饱和电流、有效电容和启动峰值核算。

**外围器件选料已逐项对过规格书要求（2026-09-23）**：`D1–D3 = MBR0530T1G`（LCSC C82046，30 V / 0.5 A，满足"反向 ≥30 V、Io ≥500 mA、Vf ≤430 mV"）✓；`L1 = NRH3010T470MN` 47 µH（C223116，与规格书同型号）✓；`R15 = 0603WAF220KT5E` = **2.2 Ω ±1%**（C22939，对应 RESE 要求 2.2 Ω / 0603 / 1%）✓；`R14/R18 = 10 kΩ ±1%`（C25804）✓；`R13 = 100 kΩ`（C25803）✓；`R16 = 0 Ω`（C21189）、`R17 = 3 Ω ±1%`（C23157，BS0 走 DESPI 的 3 Ω 方案）✓。也就是说除上面已核过的 MOSFET 与电容封装外，EPD 升压外围与规格书第 8 页的参考要求一致。

按 DESPI-E01 图面清点，除 H1 外是 **1 插座 + 1 电感 + 1 MOSFET + 3 二极管 + 7 电阻 + 13 电容 = 26 个图面器件**。其中电容 10 个为 1 µF、3 个为 4.7 µF；装配数量可能受 DNP/屏幕版本影响。这份图面清单用于评估外围区容量，不是冻结 BOM；目前 19.5 × 7.2 mm 预留区尚未通过完整器件布局验证。

### 参考板同款插座

官方电路图 FPC2 标为 **FPC-05FB-24PH20**；[LCSC C2856831](https://www.lcsc.com/product-detail/C2856831.html) 和 [JLCPCB 料库](https://jlcpcb.com/partdetail/XUNPU-FPC_05FB24PH20/C2856831)有对应 XUNPU 条目。商城条目不代表国内 SMT 已锁库存或已确认可装配。

已下载商城提供的 XUNPU 系列原厂图纸，第一张包含 24P 型号；大图以 30P 示意，24P 尺寸应代入公式，不能照用图上 18.50 mm：

- 24 pin、0.5 mm，双面接触；图纸标称闭合高度 2.00 ±0.10 mm。
- 24P 本体宽按 `(24−1)×0.5+4.00` 得 **15.50 ±0.05 mm**，比当前 FH12A 包络窄；实际库本体轮廓约 15.50 × 4.90 mm，与名义值一致。
- 推荐露铜长至少 **3.00 mm**；屏幕标称 **3.2 ±0.2 mm**，这项尺寸范围相容，但最低值没有额外余量。
- 推荐尾宽 **12.50 ±0.03 mm**、厚 **0.30 ±0.02 mm**；屏幕分别为 **12.5 ±0.1 mm**、**0.30 ±0.03 mm**。范围未完全覆盖，仍需厂家确认交付 FPC 公差及实际兼容性，不能仅凭参考板标注宣称已解决。

下一轮继续核对该插座的 pin 1、排线插入深度、翻盖空间与实物，并完善封装制造层审核。旧 FH12A CAD/PCB 留作对照；不同插座不能只改料号而保留原焊盘。

**实际库封装检查：** 使用 EDA API 导出系统库原始 `elibz2`，解包读取全部焊盘，按 PCB 单位 `1 mil = 0.0254 mm` 换算；[检查报告](../archive/pre-r1/hardware/fpc-connector-review.json)记录库 UUID、源文件 SHA-256 与逐项结果。ZIP CRC 通过，未修改上游库。

| 核对项 | 原厂名义尺寸 | 库中结果 |
| --- | --- | --- |
| 信号焊盘 | 24 个，间距 0.50 mm，单个 0.30 × 1.20 mm | 24 个编号齐全，23 个间距和 48 个长宽比较通过 |
| 固定焊盘 | 2 个，单个 2.00 × 1.80 mm，中心跨距 14.60 mm | 编号 25/26；尺寸、跨距通过 |
| 信号与固定焊盘行距 | 3.25 mm | 约 3.24993 mm，通过 |
| 本体轮廓 | 24P 宽 15.50 mm，深 4.90 mm | 对应库本体层比较通过 |

共 79 项尺寸比较，数值误差阈值 0.002 mm 仅用于容纳库坐标换算，**不是放宽制造公差**。包括固定焊盘在内的铜焊盘包围框约 16.60 × 4.75 mm，不能仅按 15.50 mm 本体宽预留。库局部坐标下 pin 1 位于 `(5.75005, 1.62497)` mm，pin 24 位于 `(-5.75005, 1.62497)` mm；这些不等于安装后屏幕引脚朝向已核实。仍需审核阻焊/钢网/丝印、实际 FPC 配合和制造工艺；本轮未改成品 PCB/CAD，三份既有 EDA 数据库校验值不变。

## 尚需厂家回答的问题

优先询问交付版本和资料差异。可直接复制给商家，请转技术支持；本轮未发送：

> 我选的是 GDEH0154E01 240×240 六色屏 + DESPI-E01，准备把驱动外围集成到自己的 3.3 V PCB。官网规格书 v1.0 和转接板电路图已下载，请技术支持确认：
>
> 1. 本次交付对应哪个屏幕/FPC 和转接板版本？请给适用的最新原理图、装配 BOM（包括不装的元件）及驱动程序。pin 1/6/7 是否都悬空？BUSY 是高忙还是低忙？pin 4/5/20 的电容应为 1 µF 还是 4.7 µF？
> 2. 转接板是否实际使用 FPC-05FB-24PH20？能否确认它与本批屏幕兼容，并提供接触面、pin 1、插入深度和 FPC 尺寸公差说明？
> 3. 25°C 下全刷典型/最长时间、允许最短刷新间隔是多少？E6 通用的 150 秒翻页建议是否适用？3.3 V 下刷新峰值/平均电流、单次刷新耗电和休眠电流是多少？有没有该型号支持的局刷或快速黑白模式？

收到答复前可整理符号、审核连接器封装、完善独立的 USB/电源部分；屏幕外围元件值保持草案。样品先通过 DESPI-E01 验证点亮、BUSY、刷新体验与供电，再冻结成品接口和外围，不要求商家代画整张名片板。

## 来源与可重复检查

2026-09-20 从厂家官网链接下载，原始字节未修改；2026-09-21 重取屏幕规格书、转接板说明书和电路图，三份 SHA-256 与既有缓存相同。新增 XUNPU 图纸来自 LCSC 对应料号的数据手册入口。路径均相对本项目；完整 URL、大小和 SHA-256 见 [下载清单](download_manifest.json)。

| 本地缓存 | 官方入口与版本 | 已检查内容 |
| --- | --- | --- |
| `downloads/gdeh0154e01.pdf` | [规格书](https://www.good-display.cn/companyfile/1762.html)，v1.0 / 2026-03-20，15 页 | 全文抽取；第 5、6、7、8、9、10 页渲染目视核对 |
| `downloads/gdeh0154e01-esp32.zip` | [ESP32 示例](https://www.good-display.com/companyfile/2062.html) | ZIP CRC、两份驱动源码和两份说明文档；未构建/烧录 |
| `downloads/despi-e01-guide.pdf` | [说明书](https://www.good-display.cn/companyfile/1816.html)，v1.0 / 2026-05-27 | 全文抽取；PDF 第 5、7 页目视核对 |
| `downloads/despi-e01-schematic.pdf` | [电路图](https://www.good-display.cn/companyfile/1817.html) | 已对照屏幕接口、升压拓扑、图面器件数量及差异；未完成 EDA 网表或实物验证 |
| `downloads/e6-design-notice-cn.pdf` | [产品页资料区](https://www.good-display.cn/product/718.html)提供的 E6 通用须知，25 页 | 全文抽取；第 3 页的 150 秒建议已目视核对 |
| `downloads/fpc-05fb-24ph20.pdf` | [XUNPU 图纸入口](https://www.lcsc.com/datasheet/C2856831.pdf)，系列图 REV A + 产品规格，共 5 页 | 首张机械/焊盘/FPC 图目视核对；Poppler 报 XRef 结构警告但可渲染，保留原文件；实际库名义尺寸已核对，装配未验证 |

使用 `pdftotext -layout` 抽取文本，`pdftoppm -png` 渲染关键页；文本及 PNG 保存在被忽略的 `artifacts/archive/gdeh0154e01-research/`。示例只从压缩包读取到该研究缓存，未引入正式固件目录。原始代码和文档保留上游声明。

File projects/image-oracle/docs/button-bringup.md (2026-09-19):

# 中心按键与屏幕计数

本页记录实际操作与验证；技术原理和后续复用方法见[按键与屏幕响应知识笔记](responsive-input-display.md)。

## 接线与目标

2026-09-19，用户确认已按此前方案接好按键并连接 USB：COM 与主板、屏幕共地，MID 接 GPIO14。接线依据见[按键接线表](../hardware/button-wiring.md)，其他六个按键信号暂不接。

本轮验证中心键每按一次，屏幕计数加一；长按只计一次，松开后再次按下才继续计数。重新上电归零。摄像头保持原有接线，但本测试固件不启用拍摄。

## 构建与烧录

以下命令从仓库根目录执行。先枚举 USB，确认 `/dev/cu.usbmodem1101` 为此前同一主板的原生 USB JTAG/serial debug unit，VID/PID `303a:1001`；旧程序 `STATUS` 仍返回显示测试版本。

```sh
uv run --with pyserial==3.5 python -m serial.tools.list_ports -v
uv run projects/image-oracle/scripts/display.py --port /dev/cu.usbmodem1101 STATUS
bash projects/image-oracle/scripts/build-display.sh
```

原厂完整 16 MiB 备份及显示基线的 7 个文件重新计算 SHA-256，与已有清单一致。恢复资料见[相机启动记录](camera-bringup.md)及 `artifacts/firmware/display-smoke-20260919/`，文件未改动。

构建通过：程序占用 342,340 字节，静态 RAM 24,464 字节，应用二进制 342,496 字节。确认没有其他进程占用串口后执行：

```sh
(
  cd projects/image-oracle/build/display_serial
  uv tool run --from esptool==5.1.0 esptool \
    --chip esp32s3 --port /dev/cu.usbmodem1101 \
    --before usb-reset --after watchdog-reset \
    write-flash @flash_args
)
```

启动程序、分区表、OTA 引导数据和应用四段写入均通过摘要校验，watchdog 自动复位进入应用。

## 状态与实物验证

```sh
uv run projects/image-oracle/scripts/display.py --port /dev/cu.usbmodem1101 STATUS
uv run projects/image-oracle/scripts/display.py --port /dev/cu.usbmodem1101 COUNTER
```

烧录后的回复包含 `revision=button-counter button_gpio=14 raw_mid=1 mid=1 count=0`，同时 `ready=1 backlight=1`、Flash 为 16 MiB、PSRAM 为 8 MiB；重画计数页返回 `OK COUNTER`。这确认新固件运行和当前 GPIO 读数，屏幕画面仍需用户目视确认。

已请用户短按 3 次、长按约 2 秒再松开、最后短按 1 次，预期计数依次到 3、4、5，长按期间不重复增加。用户操作结果待回报。测试期间通过共用的 `NativeUsbSerial` 每 250 ms 查询状态并接收按键事件；原始串口记录保存在被 Git 忽略的 `logs/button-mid-*.log`。

## 快速连按漏计数与刷新修正

用户随后报告快速连按会漏计数，并能看到明显的从上到下刷新；旧固件查询时已有 `count=25`，基本按键到屏幕路径已由实际操作验证，但上述固定次数的验收未得到明确回报。

原因是旧版在同一循环里读取按键、调用 `fillScreen()` 清屏并重画全部文字。SPI 8 MHz 下，单次 240×240、16 bit 全屏像素传输的理论下限就是 `240 × 240 × 16 / 8000000 = 115.2 ms`，加上其他绘图更慢；绘图期间主循环不再读按键。旧版还要求电平稳定 30 ms，进一步限制了快速按压。

这次改动保留现有引脚和 8 MHz SPI：

1. 使用独立 FreeRTOS 任务，每 1 ms 采样并累计按下次数；通过短临界区与绘图循环共享快照。
2. 消抖阈值改为 10 ms，按下和松开都需要达到稳定时间；长按不重复计数。
3. 只刷新 180×24 的数字区域。先在内存画好数字及黑色背景，再一次写入对应矩形，避免先清空整个可见画面。

内存画布与局部重绘的依据见 [Adafruit 减少重绘闪烁说明](https://learn.adafruit.com/adafruit-gfx-graphics-library/minimizing-redraw-flicker)。此处没有加入屏幕扫描同步，不能据此保证所有情况下都无撕裂。

### 验证结果

2026-09-19，同一块开发板、同一端口测试：

| 项目 | 结果 |
| --- | --- |
| 旧版 `COUNTER` 命令往返，3 次 | 152.39、152.49、152.48 ms |
| 新版计数页 `COUNTER` 命令往返，4 次 | 10.93、10.44、10.33、11.00 ms |
| 新版固件内测得的数字绘图耗时 | 9.55～9.59 ms |
| 新版完整计数页绘图 | 约 159 ms，仅进入页面时执行 |
| 采样最大间隔，包含 `TEST` 和完整计数页切换 | 1.362 ms |
| 消抖行为测试 | 抖动、长按、100 次快速按压、计时回绕、上电按住均通过 |
| 固件构建 | 程序 344,428 字节，静态 RAM 24,520 字节；不含运行时分配的画布／任务栈 |
| 烧录 | 四段写入摘要校验通过，watchdog 自动复位 |
| 启动状态 | `revision=button-counter-partial ready=1 button_ready=1 count=0` |

命令往返包含 USB 与任务调度，不能直接当作纯 SPI 耗时。完整页面仍需约 159 ms，但这时采样任务继续工作。原始测量记录位于本地忽略目录 `logs/display-partial-benchmark-20260919.log`。

本次构建及行为测试命令见[工程说明](../firmware/display_serial/README.md#编译)。烧录仍使用上文命令，已缓存依赖时实际使用 `uv tool run --offline --from esptool==5.1.0 ...`。查看固件内计时可直接执行：

```sh
uv run --offline projects/image-oracle/scripts/display.py --port /dev/cu.usbmodem1101 COUNTER
uv run --offline projects/image-oracle/scripts/display.py --port /dev/cu.usbmodem1101 STATUS
```

实物复测：从 0 开始快速短按 10 次，再长按约 2 秒并松开，预期到 11，同时观察数字更新是否还出现整屏扫刷。用户结果待回报；模拟测试通过和采样间隔测量不能替代真实按压验收。

修改前的整屏计数固件、源码及 SHA-256 清单已存入本地 `artifacts/firmware/display-counter-20260919/`，用于回退；原厂、相机与 `HELLO!` 显示基线仍保留。

## 连续按压后变慢：USB 日志阻塞

用户随后确认局部重绘版不再丢计数，但出现“刚开始跟手，连续按压后几次合并刷新，停一会儿又恢复”。上一轮测量时电脑持续读取串口，未覆盖关闭读取端的情况。

检查固定版本 Arduino-ESP32 3.3.11 的 `HWCDC.cpp`：默认 TX 缓冲为 256 字节，每轮发送等待 100 ms，连续失败上限 20 次。USB 连接仍在但主机停止取数据时，一次写入可等待约 2 秒。依据为本地固定版本源码与[上游对应版本](https://github.com/espressif/arduino-esp32/blob/3.3.11/cores/esp32/HWCDC.cpp)。`Serial.printf("EVENT MID ...")` 在绘图所在主循环执行，所以日志等待会推迟下一次绘图；独立按键任务仍会累计，恢复后直接显示最新总数。

### 修复及对照实验

先只增加计时，保留原有阻塞发送行为，烧录 `button-counter-usb-probe` 临时诊断版本。再对比正式修复版 `button-counter-usb-nonblocking`：所有应用层 USB 输出共用 `send_usb()`，发送等待设为 0，TX 缓冲不足容纳整条消息时跳过，并累计 `usb_dropped`。缓冲扩至 1,024 字节以容纳完整 `STATUS`；关键是零等待和跳过策略，单纯扩大缓冲只会延后堵塞。

两版均运行 [usb_backpressure.py](../tests/usb_backpressure.py)：先切到 `TEST` 页，排队八条 `STATUS` 请求，关闭 Mac 串口读取端 20 秒，再重新连接查询。`TEST` 的绘图耗时让脚本有时间在状态回复产生前关闭端口；结束后恢复计数页。测试不生成虚拟按压。

| 实机指标 | 保留阻塞发送 | 不等待发送 |
| --- | --- | --- |
| 单次 USB 输出最大耗时 | 1,999.978 ms | 0.212 ms |
| 局部数字绘图最大耗时 | 9.574 ms | 9.580 ms |
| 主循环最大间隔 | 16,195.000 ms | 196.002 ms |
| 按键采样最大间隔 | 1.146 ms | 1.172 ms |
| 未完整发送／主动跳过消息数 | 8 | 6 |
| 回归测试 | 按预期失败：USB 等待超过 50 ms | 通过 |

主循环的 16 秒来自压力测试连续排队的多条阻塞回复，不代表每次物理按键都等待 16 秒；修复后的约 196 ms 来自测试特意触发的完整彩色页面绘图。两版数字绘制均约 9.6 ms，实测慢点是 USB 发送，未发现屏幕绘图随次数增加而变慢。

构建通过：程序 345,912 字节、静态 RAM 24,584 字节；启动程序、分区表、OTA 引导数据和应用四段写入均通过校验，自动复位成功。原始对照日志保存在本地 `logs/usb-backpressure-before-20260919.log` 与 `logs/usb-backpressure-after-20260919.log`。修复前的局部重绘固件及 SHA-256 清单保存在 `artifacts/firmware/display-partial-20260919/`，同目录另存了临时诊断源码 `usb-probe.ino`。

实际使用的构建、烧录及测试命令如下，从仓库根目录执行；运行测试前关闭其他串口客户端，建议正常复位以清空历史计时峰值：

```sh
bash projects/image-oracle/scripts/build-display.sh
(
  cd projects/image-oracle/build/display_serial
  uv tool run --offline --from esptool==5.1.0 esptool \
    --chip esp32s3 --port /dev/cu.usbmodem1101 \
    --before usb-reset --after watchdog-reset write-flash @flash_args
)
uv run --offline projects/image-oracle/tests/usb_backpressure.py --port /dev/cu.usbmodem1101
uv run --offline projects/image-oracle/scripts/display.py --port /dev/cu.usbmodem1101 STATUS
```

其中 `usb_dropped` 是跳过的诊断消息数，真实按键总数仍由独立任务保存；电脑不读取时允许丢日志，之后重新查询 `count` 即可。

2026-09-19，用户针对关闭串口读取端、连续快速按约 15 秒、停顿后再按的复测，明确反馈“始终跟手，问题解决”。持续连按后延迟与合并刷新的实物验收通过，`button-counter-usb-nonblocking` 作为当前按键与屏幕交互基线。该反馈不替代此前固定次数和长按不连加的专项验收。

## 代码阅读入口

源代码为 [display_serial.ino](../firmware/display_serial/display_serial.ino)：

- `setup()` 用 `pinMode(BUTTON_MID, INPUT_PULLUP)` 启用内部上拉；松开预期读到 HIGH，按下接地后读到 LOW。
- `sample_button()` 独立采样，通过 [ButtonDebouncer](../firmware/display_serial/button_debouncer.h) 要求电平稳定 10 ms。只有新的稳定按下才计数；长按不重复触发。
- `draw_counter()` 绘制完整页面，`draw_counter_value()` 仅绘制数字。`loop()` 发现累计次数变化后更新画面；采样任务在此期间继续运行。
- `STATUS` 的 `raw_mid` 是即时电平，`mid` 是消抖后的电平，`count` 是累计按下次数；`counter_draw_us` 和 `sample_gap_max_us` 用于观察耗时。
- `send_usb()` 发送状态、命令回复和 `EVENT MID count=...`；缓冲满时跳过整条消息，`usb_write_max_us` 记录耗时峰值。事件日志可能合并或跳过，总数以 `STATUS` 为准。

普通 `STATUS` 客户端退出后，板上程序仍然继续读取按键和绘图。不要同时用多个串口客户端读取同一端口。

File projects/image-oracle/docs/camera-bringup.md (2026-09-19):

# 摄像头首次启动记录

## 目标与当前进度

2026-09-18：用户选择先验证摄像头。目标是备份原固件，构建包含 `esp32-camera` 驱动的 Arduino 固件，通过原生 USB 拍摄一张 JPEG 并在 Mac 查看。

- 原固件为 MicroPython v1.19.1，运行 `RGB Demo`；`import camera` 返回模块不存在。
- `esptool 5.1.0 flash-id` 识别 ESP32-S3 revision v0.2、16 MB Flash；应用初始化报告 8,388,608 字节 PSRAM，并成功使用 PSRAM 帧缓冲取图。尚未进行独立的全容量压力测试。
- 用户断电安装的摄像头已被驱动识别为 OV3660，PID `0x3660`，与发货单一致。
- 2026-09-19，原生 USB 完整备份成功：16,777,216 字节，用时 1461 秒；`verify-flash` 摘要比对通过，前 64 KiB 与 USB-UART 独立读取结果一致。备份为 `artifacts/backups/factory-20260918.bin`，校验记录为同目录 `factory-20260918.json`，均不入 Git。
- 工具链安装和原生 USB 版固件构建通过：程序 378,476 字节，静态 RAM 34,000 字节。烧录成功，各镜像均通过写入校验；设备查询显示 Secure Boot 和 Flash Encryption 未启用，没有修改 eFuse。
- 2026-09-19，不按按钮断电重插后，使用不切换串口控制线的 POSIX 读写方式，取得第一张 320×240 JPEG，3725 字节。已解码查看，可见显示器边角和周围环境。
- 正式 `capture.py` 随后调整为打开端口时不操作 DTR／RTS，关闭时不使用 HUPCL 挂断控制线；连续两次独立运行成功保存 4154、4289 字节的 JPEG，后一张已解码查看。照片位于忽略目录 `artifacts/photos/`。
- shell 语法检查、Python 编译检查、`git diff --check` 通过。接收逻辑通过伪终端验证：分段二进制数据完整接收，错误结束标记导致失败且不落盘，ROM 下载提示可明确报错；随后完成上述实物拍照验证。

## 操作复盘：模式、固件与工具

需要分清三层：ROM 下载器是芯片内置的；Flash 保存可替换的固件；`screen`、`esptool`、`capture.py` 是运行在 Mac 上、通过 USB 与板子通信的工具。

| 名称 | 属于哪一层 | 本次用途 |
| --- | --- | --- |
| ROM 下载模式 | 芯片启动模式 | 运行内置下载器，读取备份或写入 Flash；此时不运行灯效或相机应用 |
| 正常应用启动 | 芯片启动模式 | 从 Flash 加载引导程序和应用，执行当前保存的固件 |
| MicroPython REPL | 原固件提供的交互界面 | `>>>` 在板子上解释执行 Python；不是 ROM 下载器，也不是 Mac 本机 Python |
| 相机命令循环 | 新固件的应用逻辑 | Arduino/C++ 程序接收 `SNAP`，调用 `esp32-camera`，返回 JPEG |

本次经历的流程是：

1. **识别原程序。** Mac 识别串口后，`screen` 在 115200 下显示 RGB 灯效日志。`Ctrl+C` 中断 MicroPython 的 `main.py` 并回到 REPL，`Ctrl+D` 软重启 MicroPython。它们都不是切换到 ROM 下载模式。
2. **确认缺少相机支持。** 原固件 `import camera` 失败。选择使用包含 `esp32-camera` 的 Arduino 工程；驱动作为固件的一部分编译，未在原 Python REPL 中执行 `pip install`。
3. **进入下载模式并备份。** 按住 BOOT 插电，原灯效停止；这是运行下载器的结果，按 BOOT 本身不会擦除固件。USB-UART 高速读取失败后换到原生 USB，执行 `read-flash 0 ALL`，再用 `verify-flash` 校验完整 16 MiB 备份。
4. **在 Mac 构建。** `setup.sh` 安装固定工具链，`build.sh` 把 C++ 源码和驱动编译成 `.bin`。构建只生成电脑上的文件，还没有改动板子。
5. **写入 Flash。** `write-flash @flash_args` 将引导程序、分区表和相机应用写入板子并校验。这一步才用新固件替换原来的 MicroPython 运行环境；原固件保留在 Mac 的备份中。
6. **退出下载模式并拍照。** 本次最终通过不按任何按钮断电重插，配合不切换控制线的接收方式启动成功。随后正式 `capture.py` 连续两次完成拍照。

### 按键、快捷键和断开连接的区别

| 操作 | 作用 | 会改变 Flash 中的固件吗？ |
| --- | --- | --- |
| 按住 BOOT 上电，或按住 BOOT 再按 EN/RST | 请求进入 ROM 下载模式 | 不会 |
| 不按 BOOT，断电重插 | 重新启动当前 Flash 中的固件 | 不会 |
| 短按 EN/RST | 硬件复位；完整复位时重新判读启动状态 | 不会 |
| MicroPython 中按 `Ctrl+C` | 中断 Python 程序，返回旧固件的 REPL | 不会 |
| MicroPython REPL 中按 `Ctrl+D` | 软重启 MicroPython，再执行启动脚本 | 不会 |
| `screen` 中按 `Ctrl+A`、`D` | 只分离 Mac 上的会话，串口仍可能被占用 | 不会 |
| `screen -S <SESSION> -X quit` | 关闭指定的 Mac 会话并释放端口；控制线变化可能影响板子运行状态 | 不会 |
| `esptool write-flash ...` | 将文件内容写入指定 Flash 地址 | 会 |

**复位不会恢复原厂程序。** 现在 Flash 中是相机固件，重启仍会运行它；要回到原来的 Python REPL，需要重新烧录原固件备份。当前相机程序没有 RGB 闪灯循环，也没有 Python REPL，因此不能通过“灯是否闪”或 `Ctrl+C` 是否出现 `>>>` 判断它是否正常。

## 两个接口与 BOOT

按用户照片中天线在左、USB 接口在右的方向：靠 BOOT/IO0 的接口连接板载 USB-UART；靠 EN/RST 的接口连接 ESP32-S3 原生 USB。换口后的 USB 枚举已验证此区别：前者为 `USB Single Serial`，后者为 `USB JTAG/serial debug unit`。

BOOT 连接启动配置引脚 GPIO0。按住 BOOT 上电或复位，让芯片进入 ROM 下载模式，电脑可读取和写入 Flash。它本身不擦除 Flash；灯效停止是因为此时没有运行原来的应用程序。EN/RST 用于复位；不按 BOOT 复位通常回到 Flash 中的应用。

备份或烧录期间不要拔线、按复位或另开串口工具。完成后再按步骤切换运行模式。

参考：[Espressif 启动模式说明](https://docs.espressif.com/projects/esptool/en/latest/esp32s3/advanced-topics/boot-mode-selection.html)。

## 备份命令与恢复方法

以下命令从仓库根目录执行。`<PORT>` 替换为本次检测到的串口，不要原样输入尖括号；换接口后路径可能变化。

```sh
ls /dev/cu.*
screen -ls
```

`screen -ls` 列出会话；`Ctrl+A`、`D` 只分离会话，仍可能占用串口。需要释放端口时，先确认目标会话，再执行 `screen -S <SESSION> -X quit`。

手动进入下载模式：拔 USB，按住 BOOT，插入原生 USB 接口，再松开 BOOT。查询芯片和 Flash：

```sh
uv tool run --from esptool==5.1.0 esptool \
  --chip esp32s3 --port <PORT> --before no-reset --after no-reset \
  flash-id
```

`uv tool run` 使用隔离的固定版本工具；`--before no-reset` 保留手动进入的下载状态，`--after no-reset` 让读取完成后继续留在下载环境。备份命令：

```sh
mkdir -p projects/image-oracle/artifacts/backups
uv tool run --from esptool==5.1.0 esptool \
  --chip esp32s3 --port <PORT> --before no-reset --after no-reset \
  read-flash 0 ALL projects/image-oracle/artifacts/backups/factory-20260918.bin
```

`0 ALL` 表示从地址 0 开始读取检测到的全部 Flash；此命令只读取设备。现有同名备份应保留，重复备份需换文件名。备份、校验文件和日志均在 Git 忽略目录内。

读取成功后检查字节数和 SHA-256，再通过设备校验：

```sh
wc -c projects/image-oracle/artifacts/backups/factory-20260918.bin
shasum -a 256 projects/image-oracle/artifacts/backups/factory-20260918.bin
uv tool run --from esptool==5.1.0 esptool \
  --chip esp32s3 --port <PORT> --before no-reset --after no-reset \
  verify-flash 0 projects/image-oracle/artifacts/backups/factory-20260918.bin
```

完整文件应为 16,777,216 字节。SHA-256 标识本地文件内容；`verify-flash` 将其与设备 Flash 比对。

**下面是需要回到原厂程序时的恢复命令，不是当前备份流程的一步。** 它覆盖设备 Flash，执行前应确认目标为同一块板、备份校验通过，并按上述 BOOT 步骤重新进入下载模式：

```sh
uv tool run --from esptool==5.1.0 esptool \
  --chip esp32s3 --port <PORT> --before no-reset --after hard-reset \
  write-flash 0 projects/image-oracle/artifacts/backups/factory-20260918.bin
```

### 已遇到的读取问题

- USB-UART、921600 baud：约 4.6 MB 时数据流中断，未生成完整备份。
- USB-UART、460800 baud：约 332 KB 时收到不足 4096 字节的数据块，读取失败。
- USB-UART、115200 baud：64 KiB 小范围读取成功。
- 切换原生 USB 后可连接同一芯片；完整 16 MiB 读取与设备摘要校验均通过。

前 64 KiB 中的原厂分区表：

| 分区 | 起始地址 | 大小 |
| --- | --- | --- |
| nvs | `0x9000` | `0x6000` |
| phy_init | `0xf000` | `0x1000` |
| factory | `0x10000` | `0x1f0000` |
| vfs | `0x200000` | `0x600000` |

## 构建与拍照

```sh
bash projects/image-oracle/scripts/setup.sh
bash projects/image-oracle/scripts/build.sh
```

第一条安装固定版本工具链，第二条编译固件；均不会自动烧录。具体版本、板型参数、源码来源和传输协议见[相机工程说明](../firmware/camera_serial/README.md)。

构建生成的 `build/camera_serial/flash_args` 已核对：ESP32-S3、DIO、80 MHz、16 MB Flash，分别在 `0x0`、`0x8000`、`0xe000`、`0x10000` 写入引导程序、分区表、OTA 初始数据与应用。使用该文件可避免手工复制偏移量。

以下烧录步骤已在完成备份校验后执行成功。复现时先确认目标设备、备份和恢复方式；板子进入下载模式后，从仓库根目录运行：

```sh
uv tool run --from esptool==5.1.0 esptool \
  --chip esp32s3 --port <PORT> --before no-reset --after no-reset \
  get-security-info

(
  cd projects/image-oracle/build/camera_serial
  uv tool run --from esptool==5.1.0 esptool \
    --chip esp32s3 --port <PORT> --before no-reset --after hard-reset \
    write-flash @flash_args
)
```

`get-security-info` 只查询安全启动与 Flash 加密状态，不修改 eFuse。`@flash_args` 从构建产物读取烧录参数与文件列表；括号中的 `cd` 只影响该组命令，不改变当前终端目录。`write-flash` 会覆盖相应 Flash 区域，成功后工具尝试自动复位。

### 手动下载模式的退出

本次通过 BOOT 上电进入下载模式，烧录后的 `--after hard-reset` 未让应用运行。原生 USB 的普通复位只重置内核，不重新采样启动配置引脚，因此仍保留下载模式状态。这与烧录数据是否正确是两件事。

尝试过以下软件完整复位命令，但此板在后续串口读取中仍报告下载模式，不能将它记为已验证的退出方法：

```sh
uv tool run --from esptool==5.1.0 esptool \
  --chip esp32s3 --port <PORT> --before no-reset --after watchdog-reset \
  flash-id
```

本次已验证的退出操作是：**拔掉 USB，等待 2 秒，不按任何按钮，再插回原生 USB 接口**，随后使用修正后的 `capture.py`。理论上不按 BOOT、短按 EN/RST 也可退出；此前尝试受串口控制线操作干扰，不能据此断言按钮失效。参考：[Espressif：退出 USB-Serial/JTAG 下载模式](https://docs.espressif.com/projects/esptool/en/latest/esp32s3/troubleshooting.html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)。

### Mac 串口控制线问题

早期脚本主动设置 DTR／RTS，打开端口后收到 `rst:0x15 (USB_UART_CHIP_RESET)` 和 `waiting for download`，说明通信操作又触发了芯片复位。改为 pyserial 默认控制线状态仍没有解决。断电重插后，不执行调制解调器控制线 ioctl 的原始 POSIX 读写立即成功取图，定位到主机连接方式。

最终脚本保留 pyserial 3.5 的读写和超时处理，专门覆盖其 `_update_dtr_state`、`_update_rts_state` 钩子以跳过控制线修改，并清除 termios 的 `HUPCL`，避免关闭端口时挂断控制线。这是针对当前 Mac 与原生 USB 接口的实现；不要将该连接行为直接套用到其他需要控制线的串口设备。已用两次独立启动脚本验证连接、取帧和关闭流程。

### 日常拍照

相机程序通过 `Serial` 使用原生 USB，备份、烧录和拍照均可使用靠 EN/RST 的同一个接口；日常启动普通插入即可，不按 BOOT。该程序没有 Python REPL，也没有 RGB 闪灯循环，灯不闪不能据此判断烧录失败。

原生 USB 使用 GPIO19／20，当前摄像头不占用它们。商家屏幕接线使用这两个引脚，之后连接屏幕前必须调整屏幕引脚或将固件改为 USB-UART 通信。

```sh
uv run projects/image-oracle/scripts/capture.py \
  --port <PORT> \
  --output projects/image-oracle/artifacts/photos/my-photo.jpg
```

此脚本发送 `SNAP`，打印传感器与内存信息，接收 JPEG，并检查长度和协议标记；已有照片不会被覆盖，每次拍照需使用新文件名。当前端口为 `/dev/cu.usbmodem1101`，重插或换 Mac 接口后先用 `ls /dev/cu.*` 核对。可用以下命令打开新照片：

```sh
open projects/image-oracle/artifacts/photos/my-photo.jpg
```

已验证 320×240 单帧 JPEG；更高分辨率、视频流、屏幕和按键尚未测试。

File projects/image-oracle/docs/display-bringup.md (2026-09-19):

# 屏幕首次启动记录

## 目标与实物状态

2026-09-19：用户报告已按[接线表](../hardware/display-wiring.md)连接八针屏幕，授权继续操作。主板正常插入靠 EN/RST 的原生 USB-C 口，未按 BOOT。

- 屏幕排针顺序由用户确认：`GND VCC SCL SDA RST DC CS BL`，与套装资料一致。
- 供电按套装 3.3 V，SCK40、MOSI41、RST21、DC47、CS42、BL38。
- 没有新增实物接线／背面照片，具体 PCB 版本未独立核对；用户随后目视确认屏幕已显示测试画面。
- 电脑识别原生 USB JTAG/serial debug unit，VID/PID `303a:1001`，设备序列号与此前同一主板一致；当前端口 `/dev/cu.usbmodem1101`。

## 烧录前检查

原厂 16 MiB 备份重新计算 SHA-256，与此前验证记录一致：

```sh
shasum -a 256 projects/image-oracle/artifacts/backups/factory-20260918.bin
```

结果：`d73b6dd5a15e469a30629798664fb6e9e5c0ee30ef2679d75858d97a72b6fb15`。相机基线的源码、固件和原厂恢复路径仍保留；没有重新读取完整 Flash。

接好屏幕后，原相机固件成功拍照，说明当前供电、相机与原生 USB 仍能工作，但不证明屏幕接线无误：

```sh
uv run projects/image-oracle/scripts/capture.py \
  --port /dev/cu.usbmodem1101 \
  --output projects/image-oracle/artifacts/photos/display-wiring-check.jpg
```

收到 OV3660、16 MB Flash、8 MB PSRAM 信息，保存 320×240 JPEG，5311 字节。提取公共原生 USB 连接类后再拍一张 `display-usb-helper-check.jpg`，4869 字节，确认连接行为仍可用；照片均不入 Git。

## 屏幕固件

独立工程为 [display_serial](../firmware/display_serial/README.md)，复用已有 Arduino CLI／ESP32 core，新增固定版本 Adafruit 显示库。应用上电显示色块、白框和文字，USB 命令支持纯色、测试页和背光开关。摄像头基线工程未加入显示依赖。

构建通过，程序占用 341,532 字节，静态 RAM 24,456 字节，应用二进制 341,680 字节。生成的分区表与相机基线逐字节一致。

通过原生 USB 自动进入下载模式，写入启动程序、分区表、OTA 引导数据和应用，各段摘要校验全部通过。`--after watchdog-reset` 本次成功自动进入应用，无需用户再按按钮或断电。

```sh
bash projects/image-oracle/scripts/build-display.sh
(
  cd projects/image-oracle/build/display_serial
  uv tool run --from esptool==5.1.0 esptool \
    --chip esp32s3 --port /dev/cu.usbmodem1101 \
    --before usb-reset --after watchdog-reset \
    write-flash @flash_args
)
uv run projects/image-oracle/scripts/display.py --port /dev/cu.usbmodem1101 STATUS
```

首次状态回复：`firmware=display_serial configured=ST7789 size=240x240 ready=1 backlight=1 uptime_ms=5572 flash=16777216 psram=8388608 sck=40 mosi=41 rst=21 dc=47 cs=42 bl=38 spi_hz=8000000`。这确认主板应用正在运行，并按配置发起显示操作。

随后独立重开客户端，`STATUS` 的 uptime 增至 85,627 ms，确认打开／关闭 USB 未让程序复位；重画测试页返回 `OK TEST`。

用户在测试页显示后反馈“确实显示了”，基本显示验证通过。没有收到新照片；颜色顺序、四边是否完整和旋转方向未逐项检查，背光开关命令也尚未单独目视验证。当前保留测试页，下一步确认按键模块后做按键计数实验。

## 验证命令

```sh
bash -n projects/image-oracle/scripts/build-display.sh
python3 -m py_compile projects/image-oracle/scripts/capture.py \
  projects/image-oracle/scripts/native_usb.py \
  projects/image-oracle/scripts/display.py
git diff --check
```

上述脚本语法和差异检查已通过。屏幕没有 MISO，串口状态或命令成功不能代替对实际画面的检查。

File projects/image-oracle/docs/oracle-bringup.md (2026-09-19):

# 第三个程序：相机、屏幕与按键整合记录

日期：2026-09-19。工程与完整命令见 [oracle_live](../firmware/oracle_live/README.md)。

## 本次实现与接线

沿用已验证的 OV3660 排线、ST7789 八针接线和 MID14／COM 共地，不新增接线。固件同时运行：

- core 0：采集 160×120 JPEG，解码为 RGB565，缩到 112×84，发布最新预览帧。
- core 1 主循环：更新左侧 `LIVE`；收到 MID 或 USB `SNAP` 后，把已经显示的帧保存到右侧 `FROZEN`，计算并显示答案。
- core 1 独立按键任务：每 1 ms 采样、10 ms 消抖；绘图和 USB 不参与采样路径。

右图和答案只在定格时更新，左图继续播放。图像只保存在 RAM；断电后清空。答案采用 `RGB565-FNV1a32-MSB-v1`：对右图像素计算 FNV-1a 32 bit 哈希，以最高位决定 `TRUE`／`FALSE`。相同像素得到相同结果，不加入时间、计数或随机数。

## 构建、烧录与启动

构建通过，程序占用 408,244 字节、静态 RAM 35,784 字节。图像、驱动和任务栈另行动态分配。此前用户确认可用的按键显示程序已备份到本地 `artifacts/firmware/display-nonblocking-20260919/`，备份摘要核对通过；完整原厂备份仍保留。

本次自动进入下载模式未成功，失败发生在写入前。用户按住 BOOT 插入原生 USB 后，以下命令成功写入并通过四段摘要校验：

```sh
(
  cd projects/image-oracle/build/oracle_live
  uv tool run --offline --from esptool==5.1.0 esptool \
    --chip esp32s3 --port /dev/cu.usbmodem1101 \
    --before no-reset --after watchdog-reset write-flash @flash_args
)
```

自动重启及一次短按 EN/RST 后没有应用回复。没有重新烧录，而是先用不触发复位的只读操作确认状态：

```sh
uv tool run --offline --from esptool==5.1.0 esptool \
  --chip esp32s3 --port /dev/cu.usbmodem1101 \
  --before no-reset --after no-reset --no-stub --connect-attempts 1 read-mac
```

能够与 ROM 下载器通信，确认此时还未进入应用。用户拔 USB、等待 2 秒、不按任何按钮重新插入后，屏幕显示 `IMAGE ORACLE`，应用 `STATUS` 正常回复，识别 `sensor_pid=3660`。

这里要区分“固件写入成功”和“应用已经启动”：前者由烧录摘要校验确认，后者由应用自己的协议和实际画面确认。下载模式下不会执行屏幕程序；正常开机使用同一个原生 USB 接口即可。

## 实机结果

首次状态为 `ready=1 tasks=1 camera=1 camera_error=0`，采集与预览帧数持续增加。首轮自动测试期间出现物理按键，冻结照片发生变化，测试按预期中止；松开按键重测通过。

```sh
uv run --offline projects/image-oracle/tests/oracle_smoke.py --port /dev/cu.usbmodem1101
```

测试主动定格、等待 2 秒，确认左侧继续推进，右图的帧编号、哈希和答案保持不变。随后排队发送状态请求并关闭串口读取端，等待 5 秒再连接，确认预览继续推进、设备未重启、日志发生丢弃但没有长时间阻塞。

| 指标 | 本次实测 |
| --- | --- |
| 预览帧率 | 约 20 FPS，短窗口估算 |
| 相机错误 | 0 |
| 最近一帧解码与缩放 | 16.752 ms |
| 左图绘制峰值 | 21.073 ms |
| 右图保存、计算与答案绘制峰值 | 52.561 ms |
| 按键采样间隔峰值 | 1.490 ms |
| USB 消息发送峰值 | 0.314 ms |
| 主循环间隔峰值 | 76.009 ms |
| 无读取端压力测试期间跳过的消息 | 6 条 |

这是本次运行窗口内的结果，不是长时间运行的最坏上界。按键任务独立采样，显示仍需等待当前绘制完成；连续请求可能合并为一次定格，原始按下次数单独记录。USB 丢弃策略仅用于诊断和尽力回复；图片导出采用逐行请求与校验，失败会报错。

本地原始日志：`logs/oracle-smoke-20260919.log`，不入 Git。

## 真实照片与答案复核

```sh
uv run --offline projects/image-oracle/scripts/oracle.py --port /dev/cu.usbmodem1101 EXPORT \
  --output projects/image-oracle/artifacts/photos/oracle-frozen-20260919.png
```

成功导出右图的 112×84 像素；Mac 端重新计算得到 `232CB5A2 / FALSE`，与板上结果一致。已打开 PNG 查看，能辨认实际室内画面。照片在本地忽略目录，未加入 Git。

固定输入、重复计算、两种 Boolean 结果与最近邻缩放也已通过 `tests/oracle_image_test.cpp` 的 Mac 测试。

用户移动摄像头并多次按 MID 后，确认左侧持续预览、右侧按键换图、下方显示 TRUE/FALSE，以及画面方向和颜色“都正常，效果符合预期”。第三个程序实物体验验收通过，作为后续开发的可用基线。尚未进行长时间连续运行或专门的长按实物测试。

## 经验复用

- 固定照片应复制已经显示完成的预览帧，使按键与用户看到的画面一致。
- 摄像头的采集、解码和显示各有耗时；使用独立任务发布最新帧，避免积压旧帧。
- 图像互斥锁只保护像素复制和元数据更新，不包住相机等待、JPEG 解码或 SPI 传输。
- 沿用[按键与显示响应性笔记](responsive-input-display.md)中的独立采样、局部绘制和非阻塞日志，并重新测试相机加入后的开销。
- 导出冻结像素并在电脑重算答案，可以验证“屏幕照片 → 算法结果”是否对应；仅检查屏幕上出现 TRUE/FALSE 还不够。

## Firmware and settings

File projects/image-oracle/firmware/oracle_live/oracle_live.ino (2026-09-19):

#include <Arduino.h>
#include <SPI.h>
#include <Adafruit_ST7789.h>
#include <stdarg.h>
#include "esp_camera.h"
#include "jpeg_decoder.h"
#include "oracle_image.h"
#include "../display_serial/button_debouncer.h"

constexpr int LCD_SCK = 40, LCD_MOSI = 41, LCD_RST = 21;
constexpr int LCD_DC = 47, LCD_CS = 42, LCD_BL = 38, BUTTON_MID = 14;
constexpr uint32_t LCD_SPI_HZ = 8000000;
constexpr size_t CAMERA_WIDTH = 160, CAMERA_HEIGHT = 120;
constexpr size_t IMAGE_WIDTH = 112, IMAGE_HEIGHT = 84;
constexpr size_t IMAGE_PIXELS = IMAGE_WIDTH * IMAGE_HEIGHT;
constexpr size_t IMAGE_BYTES = IMAGE_PIXELS * sizeof(uint16_t);
constexpr int LIVE_X = 6, FROZEN_X = 122, IMAGE_Y = 48;

class Display : public Adafruit_ST7789 {
 public:
  using Adafruit_ST7789::Adafruit_ST7789;
  void begin(uint32_t = 0) override { Adafruit_ST7789::begin(LCD_SPI_HZ); }
};

struct CameraState {
  bool initialized = false;
  esp_err_t error = ESP_OK;
  uint16_t sensor_pid = 0;
  uint32_t frames = 0, frame_ms = 0, errors = 0;
  uint32_t capture_us = 0, decode_us = 0;
};

struct ButtonState {
  uint32_t presses = 0, sample_gap_max_us = 0;
  bool pressed = false;
};

Display display(&SPI, LCD_CS, LCD_DC, LCD_RST);
GFXcanvas16 answer_canvas(224, 56);
uint16_t *decoded_pixels = nullptr, *camera_pixels = nullptr, *shared_pixels = nullptr;
uint16_t *live_pixels = nullptr, *frozen_pixels = nullptr;
SemaphoreHandle_t frame_mutex = nullptr;
CameraState camera_state;
ButtonState button_state;
portMUX_TYPE button_mux = portMUX_INITIALIZER_UNLOCKED;
bool display_ready = false, tasks_ready = false, has_snapshot = false;
uint32_t live_frame = 0, frozen_frame = 0, snapshots = 0, frozen_hash = 0;
uint32_t preview_frames = 0, preview_draw_max_us = 0, snapshot_draw_max_us = 0;
uint32_t usb_write_max_us = 0, usb_dropped = 0, loop_gap_max_us = 0;
uint32_t consumed_presses = 0;

void send_usb(const char *format, ...) {
  const uint32_t started = micros();
  char message[896];
  va_list args;
  va_start(args, format);
  const int length = vsnprintf(message, sizeof(message), format, args);
  va_end(args);
  if (length <= 0 || length >= static_cast<int>(sizeof(message)) || Serial.availableForWrite() < length) {
    ++usb_dropped;
  } else if (Serial.write(reinterpret_cast<const uint8_t *>(message), length) != static_cast<size_t>(length)) {
    ++usb_dropped;
  }
  const uint32_t elapsed = micros() - started;
  if (elapsed > usb_write_max_us) usb_write_max_us = elapsed;
}

ButtonState read_button() {
  portENTER_CRITICAL(&button_mux);
  const ButtonState state = button_state;
  portEXIT_CRITICAL(&button_mux);
  return state;
}

CameraState read_camera() {
  if (!frame_mutex) return {};
  xSemaphoreTake(frame_mutex, portMAX_DELAY);
  const CameraState state = camera_state;
  xSemaphoreGive(frame_mutex);
  return state;
}

void sample_button(void *) {
  ButtonDebouncer button(10, digitalRead(BUTTON_MID) == LOW, millis());
  TickType_t next_wake = xTaskGetTickCount();
  uint32_t previous_us = micros();
  for (;;) {
    const uint32_t now_us = micros();
    const uint32_t gap = now_us - previous_us;
    previous_us = now_us;
    const bool press = button.update(digitalRead(BUTTON_MID) == LOW, millis());
    portENTER_CRITICAL(&button_mux);
    if (press) ++button_state.presses;
    button_state.pressed = button.pressed();
    if (gap > button_state.sample_gap_max_us) button_state.sample_gap_max_us = gap;
    portEXIT_CRITICAL(&button_mux);
    vTaskDelayUntil(&next_wake, pdMS_TO_TICKS(1));
  }
}

void capture_camera(void *) {
  camera_config_t config = {};
  config.ledc_channel = LEDC_CHANNEL_0;
  config.ledc_timer = LEDC_TIMER_0;
  config.pin_d0 = 11; config.pin_d1 = 9; config.pin_d2 = 8; config.pin_d3 = 10;
  config.pin_d4 = 12; config.pin_d5 = 18; config.pin_d6 = 17; config.pin_d7 = 16;
  config.pin_xclk = 15; config.pin_pclk = 13; config.pin_vsync = 6; config.pin_href = 7;
  config.pin_sccb_sda = 4; config.pin_sccb_scl = 5;
  config.pin_pwdn = -1; config.pin_reset = -1;
  config.xclk_freq_hz = 20000000;
  config.pixel_format = PIXFORMAT_JPEG;
  config.frame_size = FRAMESIZE_QQVGA;
  config.jpeg_quality = 12;
  config.fb_count = 2;
  config.fb_location = CAMERA_FB_IN_PSRAM;
  config.grab_mode = CAMERA_GRAB_LATEST;
  const esp_err_t result = esp_camera_init(&config);
  xSemaphoreTake(frame_mutex, portMAX_DELAY);
  camera_state.initialized = result == ESP_OK;
  camera_state.error = result;
  if (result == ESP_OK) camera_state.sensor_pid = esp_camera_sensor_get()->id.PID;
  xSemaphoreGive(frame_mutex);
  if (result != ESP_OK) {
    vTaskDelete(nullptr);
    return;
  }

  for (;;) {
    const uint32_t started_ms = millis();
    const uint32_t capture_started = micros();
    camera_fb_t *frame = esp_camera_fb_get();
    const uint32_t capture_us = micros() - capture_started;
    bool valid = frame && frame->format == PIXFORMAT_JPEG &&
                 frame->width == CAMERA_WIDTH && frame->height == CAMERA_HEIGHT;
    const uint32_t decode_started = micros();
    if (valid) {
      esp_jpeg_image_cfg_t jpeg = {};
      jpeg.indata = frame->buf;
      jpeg.indata_size = frame->len;
      jpeg.outbuf = reinterpret_cast<uint8_t *>(decoded_pixels);
      jpeg.outbuf_size = CAMERA_WIDTH * CAMERA_HEIGHT * sizeof(uint16_t);
      jpeg.out_format = JPEG_IMAGE_FORMAT_RGB565;
      jpeg.out_scale = JPEG_IMAGE_SCALE_0;
      esp_jpeg_image_output_t output = {};
      valid = esp_jpeg_decode(&jpeg, &output) == ESP_OK &&
              output.width == CAMERA_WIDTH && output.height == CAMERA_HEIGHT;
      if (valid) resize_rgb565(decoded_pixels, CAMERA_WIDTH, CAMERA_HEIGHT,
                               camera_pixels, IMAGE_WIDTH, IMAGE_HEIGHT);
    }
    const uint32_t decode_us = micros() - decode_started;
    if (frame) esp_camera_fb_return(frame);
    // Hold the mutex only for publishing pixels and metadata, never camera or SPI I/O.
    xSemaphoreTake(frame_mutex, portMAX_DELAY);
    camera_state.capture_us = capture_us;
    camera_state.decode_us = decode_us;
    if (valid) {
      memcpy(shared_pixels, camera_pixels, IMAGE_BYTES);
      ++camera_state.frames;
      camera_state.frame_ms = millis();
    } else {
      ++camera_state.errors;
    }
    xSemaphoreGive(frame_mutex);
    const uint32_t elapsed_ms = millis() - started_ms;
    vTaskDelay(pdMS_TO_TICKS(elapsed_ms < 50 ? 50 - elapsed_ms : 1));
  }
}

void draw_answer() {
  answer_canvas.fillScreen(ST77XX_BLACK);
  answer_canvas.setTextWrap(false);
  answer_canvas.setTextSize(1);
  answer_canvas.setTextColor(ST77XX_WHITE);
  answer_canvas.setCursor(0, 0);
  answer_canvas.print("ORACLE");
  if (has_snapshot) {
    const bool answer = oracle_answer(frozen_hash);
    answer_canvas.setTextSize(4);
    answer_canvas.setTextColor(answer ? ST77XX_GREEN : ST77XX_YELLOW);
    answer_canvas.setCursor(0, 16);
    answer_canvas.print(answer ? "TRUE" : "FALSE");
    answer_canvas.setTextSize(1);
    answer_canvas.setTextColor(ST77XX_WHITE);
    answer_canvas.setCursor(144, 16);
    answer_canvas.print("IMAGE HASH");
    answer_canvas.setCursor(144, 32);
    answer_canvas.printf("%08lX", static_cast<unsigned long>(frozen_hash));
  } else {
    answer_canvas.setTextSize(2);
    answer_canvas.setCursor(0, 20);
    answer_canvas.print("PRESS TO ASK");
  }
  display.drawRGBBitmap(8, 152, answer_canvas.getBuffer(), 224, 56);
}

void draw_layout() {
  display.fillScreen(ST77XX_BLACK);
  display.setTextWrap(false);
  display.setTextColor(ST77XX_WHITE);
  display.setTextSize(2);
  display.setCursor(48, 8);
  display.print("IMAGE ORACLE");
  display.setTextSize(1);
  display.setTextColor(ST77XX_GREEN);
  display.setCursor(LIVE_X, 32);
  display.print("LIVE");
  display.setTextColor(ST77XX_CYAN);
  display.setCursor(FROZEN_X, 32);
  display.print("FROZEN");
  display.drawRect(LIVE_X - 1, IMAGE_Y - 1, IMAGE_WIDTH + 2, IMAGE_HEIGHT + 2, ST77XX_WHITE);
  display.drawRect(FROZEN_X - 1, IMAGE_Y - 1, IMAGE_WIDTH + 2, IMAGE_HEIGHT + 2, ST77XX_WHITE);
  display.setTextColor(ST77XX_WHITE);
  display.setCursor(LIVE_X + 20, IMAGE_Y + 38);
  display.print("STARTING...");
  display.setCursor(FROZEN_X + 26, IMAGE_Y + 38);
  display.print("PRESS MID");
  display.drawFastHLine(8, 144, 224, 0x4208);
  display.setCursor(60, 224);
  display.print("PRESS MID TO FREEZE");
  draw_answer();
}

void take_snapshot() {
  if (!display_ready || !live_frame) {
    send_usb("ERROR preview not ready\n");
    return;
  }
  const uint32_t started = micros();
  // Freeze exactly the completed preview, not a newer frame from the camera task.
  memcpy(frozen_pixels, live_pixels, IMAGE_BYTES);
  frozen_frame = live_frame;
  frozen_hash = oracle_hash(frozen_pixels, IMAGE_PIXELS);
  ++snapshots;
  has_snapshot = true;
  display.drawRGBBitmap(FROZEN_X, IMAGE_Y, frozen_pixels, IMAGE_WIDTH, IMAGE_HEIGHT);
  draw_answer();
  const uint32_t elapsed = micros() - started;
  if (elapsed > snapshot_draw_max_us) snapshot_draw_max_us = elapsed;
  send_usb("SNAP snapshot=%lu frame=%lu hash=%08lX oracle=%s\n",
           static_cast<unsigned long>(snapshots), static_cast<unsigned long>(frozen_frame),
           static_cast<unsigned long>(frozen_hash), oracle_answer(frozen_hash) ? "TRUE" : "FALSE");
}

void handle_command(const char *command) {
  if (strcmp(command, "STATUS") == 0) {
    const CameraState camera = read_camera();
    const ButtonState button = read_button();
    send_usb("STATUS firmware=oracle_live revision=1 ready=%d tasks=%d camera=%d camera_error=%d "
             "sensor_pid=%04X uptime_ms=%lu camera_frames=%lu preview_frames=%lu camera_errors=%lu "
             "live_frame=%lu frozen_frame=%lu snapshots=%lu hash=%08lX oracle=%s "
             "frame_age_ms=%lu capture_us=%lu decode_us=%lu preview_draw_max_us=%lu snapshot_draw_max_us=%lu "
             "button_presses=%lu sample_gap_max_us=%lu usb_write_max_us=%lu usb_dropped=%lu loop_gap_max_us=%lu\n",
             display_ready, tasks_ready, camera.initialized, camera.error, camera.sensor_pid, millis(),
             camera.frames, preview_frames, camera.errors, live_frame, frozen_frame, snapshots, frozen_hash,
             has_snapshot ? (oracle_answer(frozen_hash) ? "TRUE" : "FALSE") : "NONE",
             camera.frames ? millis() - camera.frame_ms : 0, camera.capture_us, camera.decode_us,
             preview_draw_max_us, snapshot_draw_max_us, button.presses, button.sample_gap_max_us,
             usb_write_max_us, usb_dropped, loop_gap_max_us);
  } else if (strcmp(command, "SNAP") == 0) {
    take_snapshot();
  } else if (strncmp(command, "ROW ", 4) == 0) {
    char *end = nullptr;
    const long row = strtol(command + 4, &end, 10);
    if (!has_snapshot || end == command + 4 || *end || row < 0 || row >= static_cast<long>(IMAGE_HEIGHT)) {
      send_usb("ERROR invalid row or no snapshot\n");
      return;
    }
    char pixels[IMAGE_WIDTH * 4 + 1];
    const char hex[] = "0123456789ABCDEF";
    for (size_t x = 0; x < IMAGE_WIDTH; ++x) {
      const uint16_t pixel = frozen_pixels[row * IMAGE_WIDTH + x];
      for (size_t digit = 0; digit < 4; ++digit) pixels[x * 4 + digit] = hex[(pixel >> (12 - digit * 4)) & 15];
    }
    pixels[IMAGE_WIDTH * 4] = '\0';
    send_usb("ROW snapshot=%lu y=%ld pixels=%s\n", snapshots, row, pixels);
  } else {
    send_usb("ERROR use STATUS SNAP or ROW <0..83>\n");
  }
}

void setup() {
  Serial.setTxBufferSize(1024);
  Serial.setTxTimeoutMs(0);
  Serial.begin(115200);
  pinMode(LCD_BL, OUTPUT);
  digitalWrite(LCD_BL, LOW);
  pinMode(BUTTON_MID, INPUT_PULLUP);
  if (!psramFound()) { send_usb("ERROR PSRAM unavailable\n"); return; }
  decoded_pixels = static_cast<uint16_t *>(ps_malloc(CAMERA_WIDTH * CAMERA_HEIGHT * sizeof(uint16_t)));
  camera_pixels = static_cast<uint16_t *>(ps_malloc(IMAGE_BYTES));
  shared_pixels = static_cast<uint16_t *>(ps_malloc(IMAGE_BYTES));
  live_pixels = static_cast<uint16_t *>(ps_malloc(IMAGE_BYTES));
  frozen_pixels = static_cast<uint16_t *>(ps_malloc(IMAGE_BYTES));
  frame_mutex = xSemaphoreCreateMutex();
  if (!decoded_pixels || !camera_pixels || !shared_pixels || !live_pixels || !frozen_pixels ||
      !frame_mutex || !answer_canvas.getBuffer()) { send_usb("ERROR allocation failed\n"); return; }
  if (!SPI.begin(LCD_SCK, -1, LCD_MOSI, LCD_CS)) { send_usb("ERROR SPI initialization failed\n"); return; }
  display.init(240, 240, SPI_MODE0);
  display.setRotation(0);
  draw_layout();
  display_ready = true;
  digitalWrite(LCD_BL, HIGH);
  const bool button_started = xTaskCreatePinnedToCore(sample_button, "button", 2048, nullptr, 2,
                                                     nullptr, ARDUINO_RUNNING_CORE) == pdPASS;
  const bool camera_started = xTaskCreatePinnedToCore(capture_camera, "preview", 8192, nullptr, 1,
                                                     nullptr, 0) == pdPASS;
  tasks_ready = button_started && camera_started;
  send_usb("READY oracle_live tasks=%d; MID freezes the visible preview\n", tasks_ready);
}

void loop() {
  static uint32_t previous_us = micros();
  const uint32_t now_us = micros();
  const uint32_t gap = now_us - previous_us;
  previous_us = now_us;
  if (gap > loop_gap_max_us) loop_gap_max_us = gap;
  static char command[32];
  static size_t length = 0;
  static bool overflow = false;
  for (int budget = 0; budget < 64 && Serial.available(); ++budget) {
    const char ch = Serial.read();
    if (ch == '\r') continue;
    if (ch == '\n') {
      if (overflow) send_usb("ERROR command too long\n");
      else if (length) { command[length] = '\0'; handle_command(command); }
      length = 0;
      overflow = false;
    } else if (length < sizeof(command) - 1) command[length++] = ch;
    else overflow = true;
  }
  const ButtonState button = read_button();
  if (consumed_presses != button.presses) {
    // Multiple presses between displayed frames request the same latest frozen view.
    consumed_presses = button.presses;
    take_snapshot();
  }
  if (display_ready && frame_mutex) {
    bool changed = false;
    xSemaphoreTake(frame_mutex, portMAX_DELAY);
    if (camera_state.frames != live_frame) {
      memcpy(live_pixels, shared_pixels, IMAGE_BYTES);
      live_frame = camera_state.frames;
      changed = true;
    }
    const esp_err_t camera_error = camera_state.error;
    xSemaphoreGive(frame_mutex);
    if (changed) {
      const uint32_t started = micros();
      display.drawRGBBitmap(LIVE_X, IMAGE_Y, live_pixels, IMAGE_WIDTH, IMAGE_HEIGHT);
      const uint32_t elapsed = micros() - started;
      if (elapsed > preview_draw_max_us) preview_draw_max_us = elapsed;
      ++preview_frames;
    }
    static bool error_shown = false;
    if (camera_error != ESP_OK && !error_shown) {
      display.fillRect(LIVE_X, IMAGE_Y, IMAGE_WIDTH, IMAGE_HEIGHT, ST77XX_BLACK);
      display.setTextColor(ST77XX_RED);
      display.setTextSize(1);
      display.setCursor(LIVE_X + 20, IMAGE_Y + 38);
      display.print("CAM ERROR");
      error_shown = true;
    }
  }
  delay(1);
}

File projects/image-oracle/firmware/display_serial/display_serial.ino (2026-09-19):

#include <Arduino.h>
#include <SPI.h>
#include <Adafruit_ST7789.h>
#include <stdarg.h>
#include "button_debouncer.h"

constexpr int LCD_SCK = 40;
constexpr int LCD_MOSI = 41;
constexpr int LCD_RST = 21;
constexpr int LCD_DC = 47;
constexpr int LCD_CS = 42;
constexpr int LCD_BL = 38;
constexpr uint32_t LCD_SPI_HZ = 8000000;
constexpr int BUTTON_MID = 14;
constexpr uint32_t BUTTON_DEBOUNCE_MS = 10;
constexpr int COUNTER_WIDTH = 180;
constexpr int COUNTER_HEIGHT = 24;

class Display : public Adafruit_ST7789 {
 public:
  using Adafruit_ST7789::Adafruit_ST7789;

  void begin(uint32_t = 0) override {
    // init() calls begin() internally; also limit initialization on jumper wires.
    Adafruit_ST7789::begin(LCD_SPI_HZ);
  }
};

Display display(&SPI, LCD_CS, LCD_DC, LCD_RST);
GFXcanvas16 counter_canvas(COUNTER_WIDTH, COUNTER_HEIGHT);
bool display_ready = false;
bool backlight_on = false;
bool counter_visible = false;
bool button_ready = false;
uint32_t press_count = 0;
uint32_t counter_draw_us = 0;
uint32_t counter_draw_max_us = 0;
uint32_t page_draw_us = 0;
uint32_t usb_write_max_us = 0;
uint32_t usb_messages_dropped = 0;
uint32_t loop_gap_max_us = 0;

struct ButtonSnapshot {
  uint32_t count = 0;
  uint32_t max_sample_gap_us = 0;
  bool pressed = false;
};

ButtonSnapshot button_state;
portMUX_TYPE button_mux = portMUX_INITIALIZER_UNLOCKED;

void send_usb(const char *format, ...) {
  const uint32_t start_us = micros();
  char message[768];
  va_list args;
  va_start(args, format);
  const int length = vsnprintf(message, sizeof(message), format, args);
  va_end(args);
  // A missing or slow USB reader must never delay the screen.
  if (length <= 0 || length >= static_cast<int>(sizeof(message)) || Serial.availableForWrite() < length) {
    ++usb_messages_dropped;
  } else if (Serial.write(reinterpret_cast<const uint8_t *>(message), length) != static_cast<size_t>(length)) {
    ++usb_messages_dropped;
  }
  const uint32_t elapsed_us = micros() - start_us;
  if (elapsed_us > usb_write_max_us) usb_write_max_us = elapsed_us;
}

ButtonSnapshot read_button_state() {
  portENTER_CRITICAL(&button_mux);
  const ButtonSnapshot snapshot = button_state;
  portEXIT_CRITICAL(&button_mux);
  return snapshot;
}

void sample_button(void *) {
  ButtonDebouncer button(BUTTON_DEBOUNCE_MS, digitalRead(BUTTON_MID) == LOW, millis());
  TickType_t next_wake = xTaskGetTickCount();
  uint32_t previous_sample_us = micros();
  for (;;) {
    const uint32_t now_us = micros();
    const uint32_t gap_us = now_us - previous_sample_us;
    previous_sample_us = now_us;
    const bool pressed = button.update(digitalRead(BUTTON_MID) == LOW, millis());
    portENTER_CRITICAL(&button_mux);
    if (pressed) ++button_state.count;
    button_state.pressed = button.pressed();
    if (gap_us > button_state.max_sample_gap_us) button_state.max_sample_gap_us = gap_us;
    portEXIT_CRITICAL(&button_mux);
    vTaskDelayUntil(&next_wake, pdMS_TO_TICKS(1));
  }
}

void draw_counter_value() {
  const uint32_t start_us = micros();
  counter_canvas.fillScreen(ST77XX_BLACK);
  counter_canvas.setTextWrap(false);
  counter_canvas.setTextColor(ST77XX_GREEN);
  counter_canvas.setTextSize(3);
  counter_canvas.setCursor(0, 0);
  counter_canvas.print(press_count);
  display.drawRGBBitmap(24, 90, counter_canvas.getBuffer(), COUNTER_WIDTH, COUNTER_HEIGHT);
  counter_draw_us = micros() - start_us;
  if (counter_draw_us > counter_draw_max_us) counter_draw_max_us = counter_draw_us;
}

void draw_counter() {
  const uint32_t start_us = micros();
  display.fillScreen(ST77XX_BLACK);
  display.drawRect(0, 0, 240, 240, ST77XX_WHITE);
  display.setTextWrap(false);
  display.setTextColor(ST77XX_WHITE);
  display.setTextSize(2);
  display.setCursor(24, 28);
  display.print("BUTTON COUNTER");
  display.setTextColor(ST77XX_WHITE);
  display.setTextSize(1);
  display.setCursor(24, 166);
  display.print("Press the stick: +1");
  display.setCursor(24, 190);
  display.print("MID -> GPIO14");
  display.setCursor(24, 208);
  display.print("COM -> GND");
  draw_counter_value();
  counter_visible = true;
  page_draw_us = micros() - start_us;
}

void draw_test_pattern() {
  counter_visible = false;
  display.fillScreen(ST77XX_BLACK);
  display.fillRect(0, 0, 80, 64, ST77XX_RED);
  display.fillRect(80, 0, 80, 64, ST77XX_GREEN);
  display.fillRect(160, 0, 80, 64, ST77XX_BLUE);
  display.drawRect(0, 0, 240, 240, ST77XX_WHITE);
  display.setTextWrap(false);
  display.setTextSize(2);
  display.setTextColor(ST77XX_WHITE);
  display.setCursor(10, 24);
  display.print("R");
  display.setTextColor(ST77XX_BLACK);
  display.setCursor(90, 24);
  display.print("G");
  display.setTextColor(ST77XX_WHITE);
  display.setCursor(170, 24);
  display.print("B");
  display.setTextSize(4);
  display.setCursor(24, 85);
  display.print("HELLO!");
  display.setTextSize(2);
  display.setCursor(24, 140);
  display.print("ESP32-S3");
  display.setTextSize(1);
  display.setCursor(24, 175);
  display.print("ST7789 240x240 / SPI 8MHz");
  display.setCursor(24, 197);
  display.print("SCK40 MOSI41 RST21");
  display.setCursor(24, 211);
  display.print("DC47 CS42 BL38");
}
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

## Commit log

2026-09-19 feat: complete Image Oracle breadboard prototype
    Add reproducible camera, display/button, and live oracle firmware with host tools and regression tests. Archive wiring diagrams and bring-up notes, record responsiveness fixes, and document sensor experiments and compact hardware as the next two tracks.
    Verify debounce and image tests, script syntax, documentation links, wiring JavaScript, and local firmware archive checksums.
    [camera_serial.ino, capture.py, display.py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]
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2026-09-22 feat: apply right-mid USB layout to the E16 sheet
    Move the USB-C receptacle to the right edge middle and turn the nRF52840
    module so its antenna faces the bottom board edge. The cut-out is 9.24 mm
    tall, matching the GCT recommended-layout solder area so the connector
    anchor pads stay on the board.
    Verified live: rotation is counter-clockwise positive, all 11 moved parts
    and the rebuilt Layer 11 outline survive close and reopen, and native DRC
    drops from 220 findings to 213 (clearance 8 to 1, no new items). Remaining
    mechanical items: connector shell versus the cut-out flanges and the
    enclosure right-wall opening.
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2026-09-22 docs: record the USB fan-out channel study after a reverted routing try
    Routing CC1, CC2 and the two data nets needed 33 segments and 4 vias and
    produced 16 track-to-track violations: the fan-out band between the module
    side parts and the 0.5 mm pitch connector pads is only about 1.2 mm wide,
    so two data lanes plus vias and the CC lanes do not fit. The attempt is
    reverted to the verified layout (213 DRC findings, 0 copper, 0 vias) and
    the measured constraints are recorded for the next iteration.
2026-09-22 feat: route USB CC1/CC2 on the E16 sheet
    Both CC nets are now connected with 13 top-layer segments (17.1 mm, no vias):
    the trace leaves the connector at the pad ends, clears the pull-down
    resistor ground pads and lands on the U6 clamp pads. Close and reopen keeps
    the copper; native DRC stays at 1 clearance, 12 same-footprint and 194
    connection findings, so nothing new was introduced.
    Session search recovered the earlier E7/E9/E10/E11 study of the same
    constraint: USB-C data fan-out is a local bottleneck independent of the
    connector position, and the 12/24 mil vias used so far cannot be placed at
    the 0.5 mm pad pitch. The record now points at 0.15/0.25 mm vias plus a
    four-layer stack, or mov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
2026-09-22 feat: move the USB series resistors next to the module
    R3/R4 leave the charger cluster at x 53 for (72.0, 11.0) and (72.0, 9.2)
    with the connector-side pads facing right, so both ends of each data net
    now sit inside the same local area instead of a 40 mm detour. Coordinates
    only: the netlist is untouched and DRC stays at 1 clearance, 12
    same-footprint and 194 connection findings.
2026-09-22 docs: record the small-via fan-out test and its blocker
    Four 0.15/0.25 mm vias fit at the 0.5 mm connector pad pitch, but the test
    produced 16 clearance and 4 physical errors: every one of them is the
    existing CC2 top-layer run crossing the via column. The fan-out band is
    blocked by channel occupancy, not by via size or trace width. The test is
    reverted (13 CC segments, 0 vias, DRC 1 + 12 + 194) and the note records
    the order for the next attempt: move CC to the bottom layer first, then
    fan out the data pair with the small vias.
2026-09-22 docs: record that the via-size rule blocks the small-via fan-out
    Routing CC2 on the bottom layer with 0.15/0.25 mm vias produced three
    physical "Via Diameter" errors: the project's manufacturing rules require a
    larger via than 0.25 mm, so the small-via plan needs a GUI rule change
    before DRC can accept it. The same test also showed the CC2 clamp stub
    colliding with the CC1 top-layer branch. The test is reverted (13 CC
    segments, 0 vias, DRC 1 + 12 + 194).
2026-09-22 feat: pass the USB data fan-out with 0.3 mm vias on the multilayer rules
    With the sheet switched to the JLCPCB multiple-layer capability (via 0.3 mm
    / hole 0.2 mm), six small vias now carry the data pair and CC2 out of the
    0.5 mm-pitch connector: DM staggered into the gap between the ESD pad rows,
    DP on the pad rows, and CC2 moved to the bottom layer so the top band
    stays free. Native DRC reports a single clearance finding - the pre-existing
    BAT_PACK test-point conflict - plus the known 12 slot items and 199
    unrouted connections, so the E7/E11 fan-out blocker is resolved.
2026-09-22 feat: route the complete USB data pair through the series resistors
    DP and DM now run from the connector through U5 and R3/R4 to the nRF52840:
    the U5 side connects on the top layer without extra vias, the bottom trunk
    keeps DP at x 75.05 and DM at x 73.60 so the two never cross, and the module
    side re-enters the top layer next to U1's USB pins. All four data nets are
    connected (connection findings 200 -> 184) with no new clearance errors;
    the only clearance finding is the pre-existing BAT_PACK test-point conflict.
    USB_CC2 still shows two contacts to recheck and VBUS is not routed yet.
2026-09-22 docs: refresh the NFC card status with the routed USB data path
    README now records the multilayer rule switch, the 0.3/0.2 mm small-via
    fan-out, the completed DP/DM path from the connector through U5 and R3/R4
    to the module, and the current 39 segments / 13 vias with DRC at 1 + 12 +
    184 and no new clearance errors. It also lists the E16 enclosure sample
    with its two open constraints and the concrete next steps.
2026-09-22 fix: complete USB_CC2 and record the VBUS routing constraint
    CC2 needed its R2-side stub extended into the pad; both CC nets are now
    connected (connection findings 184 -> 182). Two VBUS attempts are reverted:
    vias at x = 77.0 sit inside the connector body outline and trip the 0.3 mm
    board-outline rule, while escaping around the body hit 29 findings instead.
    The board is back to 39 segments, 13 vias and DRC 1 + 12 + 182, and the note
    records the escape rule for the next attempt.
2026-09-22 docs: record that the right-hand corridor is unusable for VBUS
    The third VBUS attempt (trunk at y = 8.2) still produced 13 findings:
    the connector anchor pads sit at x = 77.1 and the footprint outline line
    e62 also runs there, so the x > 76.4 corridor is closed. The attempt is
    reverted (39 segments, 13 vias, DRC 1 + 12 + 182) and the note records the
    corridor table for the next pass.
2026-09-22 docs: record the EDA bridge stability diagnosis
    Logs show the bridge itself is healthy (launchd-managed, single instance) while
    the extension reconnects about every 16 seconds and registers a new windowId
    each time; the server never heartbeats or drops stale registrations, so the
    window list keeps a zombie entry and requests land on a dead or half-dead
    socket. The note records the three-step mitigation: client-side window
    selection with one retry (done), a patched local server copy with heartbeat and
    stale-connection cleanup (not upstream), and keeping a single editor window.
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2026-09-22 feat: route the USB_VBUS trunk along the recorded corridor
    The corridor table worked on the first try: layer-change vias stay outside
    the connector body, the bottom trunk runs at y = 8.2 from x 75.1 to 44.2 and
    climbs at x 44.2 to the charger input, C8 joins at y = 20.5 and C1 plus the
    module VBUS pin use via-in-pad changes. Clearance findings stay at the single
    pre-existing BAT_PACK item with no additions and connections drop from 182 to
    178. USB_VBUS still shows two isolated primitives to close next.
2026-09-22 chore: add VBUS junction overlap segments
    VBUS still reports two connection findings after adding redundant overlap
    segments at the x 44.2 junction, so the isolated component is not the
    charger/C8 branch end. The board keeps 19 vias and the single pre-existing
    clearance finding; the next pass should dump the two isolated primitive ids
    with their endpoints rather than guessing.
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2026-09-22 feat: complete the USB interface routing
    The connectivity graph pinpointed the last VBUS break: the B4A9 branch
    stopped at (75.6, 8.2) while the trunk ended at (75.1, 8.2). A single 0.5 mm
    segment closes it, so CC1, CC2, DP_CONN, DM_CONN, DP_MCU, DM_MCU and VBUS
    are all routed with no new clearance findings - the only clearance item left
    is the pre-existing BAT_PACK test point. Board: 60 segments, 19 vias and
    connection findings down from 200 to 176.
2026-09-22 docs: record the completed USB interface routing
    README now states that all seven USB nets (CC1, CC2, DP/DM connector and
    module sides, VBUS) are routed on the E16 sheet with 60 segments and 19
    0.3/0.2 mm vias, connection findings down from 200 to 176 and no new
    clearance findings beyond the pre-existing BAT_PACK item.
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2026-09-22 feat: take over the EasyEDA bridge in the repo with a crash-proof server
    The upstream bridge exited whenever a /execute result could not be serialised:
    it wrote the 200 header first and the catch wrote it again, so
    ERR_HTTP_HEADERS_SENT killed the process and every EDA connection dropped with
    it. tools/easyeda-bridge now carries a patched copy whose 15 response paths use
    a safe serializer (circular refs marked, BigInt stringified, functions
    dropped) plus uncaughtException and unhandledRejection guards, together with an
    idempotent LaunchAgent installer, a status script and a plist template that
    keeps logs under logs/ and throttles restarts. The capability notes record the
    root cause and the n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
2026-09-22 fix: single-write HTTP responses and fresh-window selection in the bridge
    Every HTTP reply now goes through sendJson(), which checks headersSent and
    writableEnded before writing, so the ERR_HTTP_HEADERS_SENT branch that the
    guards used to catch is gone (the two historical "Cannot write headers"
    lines stay at two, crashes stay at zero). The server also pings EDA sockets
    every 5 s, records lastSeenAt, exposes lastSeenMsAgo/stale in
    /eda-windows and makes select/execute fall back to the freshest window when
    the requested one has gone quiet for 30 s. install-agent.sh gains
    --no-login-start and --quiet, refuses to start when 49620 is held by another
    process, checks the node path, rotates logs ove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
2026-09-22 feat: route the first EPD net along the corrected corridor
    BUSY is fully connected with no new clearance findings (connection findings
    176 -> 173): via-in-pad at the module, a bottom trunk on y = 19 that clears
    R9's pull-up pads and the NFC keep-out, a plain via plus top stub on the J2
    side because a 0.3 mm via-in-pad on the 0.5 mm FPC row only clears 0.2 mm,
    and an R18 branch at x = 52.6. The note records those two rules for the
    remaining five EPD nets.
2026-09-22 docs: record the corridor constraints for the five remaining EPD nets
    Their module-side pads sit at y 9.3-11.3 while the routed USB data pair
    owns the escape corridor (DM_MCU vertical at x 59.3, DP_MCU horizontal at
    y 11.0 and their two vias), so the five nets must drop to y ~ 8.8 on the top
    layer under the module first, stagger five layer-change vias between x 59.6
    and 61.6 at >= 0.5 mm pitch, then use the nested bottom lanes. SCK and MOSI
    swap order between the two ends, so SCK needs a two-via top jog near y 11.3.
    J2 side stays via-plus-stub at x ~ 51.4.
2026-09-22 feat: route every non-GND net on the E16 PCB
    All 45 signal nets on the E16 right-mid USB page are now connected; the
    native DRC is down to one pre-existing clearance error (BAT_PACK test
    point), the 12 known J1 slot-edge warnings, and 54 GND connections that
    need a copper pour.
    The auto router resolved 29 nets but left 12 connections blocked by its
    own local decisions, so this round adds an offline two-layer maze router
    (projects/nfc-business-card/scripts/pcb-maze-router.py). It rasterises the
    real design rules (track-track 0.102 mm, pad/via-track 0.152 mm, edge
    0.300 mm) into a 0.1 mm grid, runs a vectorised Dijkstra with an optional
    congestion cost, and emits a segment/via list that a sep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
2026-09-22 feat: add the GND copper pour on the E16 PCB
    pcb_PrimitivePour.create() only accepts an explicitly closed polygon on
    this build: every open-loop variant fails with "无法创建覆铜边框图元".
    With the loop closed, GND_TOP and GND_BOT pour over the whole board, and
    rebuilding the copper regions drops the GND connection errors from 54 to
    32. Stitching vias - placed with the maze router's clearance model so they
    still touch the pad copper - bring it down to 23 without adding clearance
    errors; the first attempt at pad centres produced 13 Track/Hole/Pad to Via
    violations, all removed by the repositioning pass.
    23 GND pads remain isolated where no legal via spot exists or where the
    pour is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
2026-09-22 feat: finish the GND stitching and clear the E16 DRC
    Every net on the E16 right-mid USB page is now connected: the native DRC
    connection count is 0, leaving only the pre-existing BAT_PACK test point
    clearance (0.05 mm to R6_2) and the 12 known J1 slot-edge warnings.
    Finishing steps after the first pour pass:
    - 26 stitching vias placed with the router's clearance model (the first
    attempt at pad centres added 13 Track/Hole/Pad to Via violations).
    - 15 remaining GND islands routed to the nearest connected GND pad - 101
    segments and 22 vias - dropping GND connection errors from 23 to 2.
    - hole-to-hole clearance (0.3 mm) added to the via placement search; one
    duplicate via removed and two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
2026-09-22 fix: clear the last E16 clearance error
    The BAT_PACK test point is a free pad, not part of a component, so it can
    be moved with pcb_PrimitivePad.modify(). Moving it from (49.799, 23.701)
    to (49.5, 23.55) takes it 0.24 mm away from the R6_2 pad instead of
    0.05 mm, and the board now reports zero clearance errors and zero
    connection errors; only the 12 documented J1 slot-edge warnings remain.
    The pours have to be rebuilt after such a move, otherwise the stale fill
    sits against the moved pad and raises "Copper Region(Filled) to SMD Test
    Point" instead.
2026-09-22 feat: add the E16 enclosure V2 and settle the size basis
    V1 shipped an outer shell of 84 x 52 mm with an 81.6 x 49.6 mm cavity,
    which cannot hold the 84 x 52 mm PCB, and assumed the USB connector body
    reached x = 88.45 mm.
    V2 fixes both:
    - laminate structure: the PCB outline is the card outline, and each shell
    carries a 1.0 mm inboard ledge so the card stays 84 x 52 mm with the PCB
    edge exposed.
    - the connector front is 85.3 mm, taken from the GCT drawing (recommended
    layout and Section A-A put it roughly 1.2-1.3 mm past the PCB edge), so
    the card is 85.3 mm long and fits inside the 85.6 mm business-card
    length. The shells follow the board notch, so no wall slot is needed.
    - the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
    [nfc-card-e16-bottom-v2.stl, nfc-card-e16-enclosure-v2.FCStd, nfc-card-e16-enclosure-v2.step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]
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2026-09-22 fix: measure the J1 envelope from the exported STEP model
    The enclosure V2 estimated the connector's front at x = 85.3 mm from a
    reading of the GCT drawing, and V1 assumed 88.45 mm. Exporting the board's
    3D model (pcb_ManufactureData.get3DFile with 'Component Model') and
    measuring J1 in it gives the real envelope: x 76.7 -> 83.2 mm (6.5 mm body
    length, matching the catalogue), y 10.22 -> 21.77 mm, and 0 -> 3.17 mm
    above the board face.
    So the mating face sits 0.8 mm *inside* the board edge, the connector does
    not overhang at all, and the card's overall length is the 84 mm board
    outline. The 0.8 mm difference between the footprint's internal slot line
    (76.7 mm) and the board notch inner ed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
    [nfc-card-e16-bottom-v2.stl, nfc-card-e16-enclosure-v2.FCStd, nfc-card-e16-enclosure-v2.step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]
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2026-09-22 docs: tighten the antenna keep-out verification (1681-point sampling + Gerber boundary check)
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2026-09-22 feat: add the E16 enclosure V3 for the L-shaped board
    With the battery bite in the PCB, the cell no longer stacks on top of the
    board, so the case drops from 5.0 to 4.5 mm: 0.4 bottom plate + 0.3
    under-board gap + 0.8 PCB + 2.5 top cavity (panel area) + 0.5 top plate.
    The shells follow the L-shaped outline; the bite keeps no ledge, so the
    bottom plate is the cell's floor and the top plate covers it. Screen
    window, three key holes and the USB relief carry over from V2, and the
    geometry check is green: one solid per shell, no shell or reference
    intersections, and zero contact with the connector.
    [nfc-card-e16-bottom-v3.stl, nfc-card-e16-enclosure-v3.FCStd, nfc-card-e16-enclosure-v3.step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]
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2026-09-22 feat: rib the E16 V3 top shell
    The 0.5 mm top plate spans the battery bite (33.5 x 15) and the rest of the
    cavity unsupported, which would sag in a print and leave the visible face
    wavy. Three 0.8 x 0.4 mm ribs now run under the plate at z 3.6-4.0: one in
    the band between the bite and the screen, one in the strip east of the keys,
    and one across the battery pocket ceiling. They sit above the tallest part
    (1.51 mm over the PCB) and the geometry check confirms no intersection with
    the panel, FPC, keys, U1 or the cell envelope.
    [nfc-card-e16-enclosure-v3.FCStd, nfc-card-e16-enclosure-v3.step, nfc-card-e16-top-v3.stl]
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2026-09-22 fix: close the E16 battery pocket in enclosure V4
    Probing the saved V3 solid showed both printed plates were built from the
    L-shaped board outline, so the 33.5 x 15 mm battery bite had no floor and no
    ceiling: the cell would sit in a through-opening, and the rib meant to stiffen
    the pocket ceiling floated in mid air (TopShell reported two solids).
    - build the printed plates from the full card outline minus the USB notch and
    keep only the 1.0 mm ledge on the L-shaped board outline
    - record the pocket floor (201 mm3) and ceiling (251.25 mm3) volumes plus the
    single-solid expectation as regression checks in the report
    - render the V4 isometric and front views and update the enclosure, E16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
    [nfc-card-e16-bottom-v4.stl, nfc-card-e16-enclosure-v4.FCStd, nfc-card-e16-enclosure-v4.step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]
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2026-09-22 feat: check the E16 shells against the real component models
    The enclosure geometry reports only used simplified reference boxes, so nothing
    proved that the actual footprints fit inside the 2.5 mm cavity.
    - add eda-export-e16-3d.js to export the board plus component models as STEP
    - add check-e16-board-fit.py: lifts the board to z=0.7, drops the unplaced
    library models the exporter leaves at the origin, and reports shell
    interferences, rib-band interferences and the tallest-part clearance
    - record the result in the E16 record and the manufacturing gates: 462 placed
    solids, 0 real interferences, 0 rib collisions, J1 (3.87 mm) leaves 0.13 mm
    below the 4.0 mm ceiling, U1 3.53 and J2 3.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
2026-09-22 feat: add flush key caps to the E16 enclosure (V5)
    The SKQGABE010 is 5.2 x 5.2 x 1.5 mm with 0.25 mm travel (Alps drawing No.1),
    so its stem top sits 1.0 mm below the 0.5 mm top plate: nothing could press it.
    - add two printed caps (4.2 mm puck riding in the 4.6 mm hole plus a 3.2 mm
    travel boss, 1.45 mm tall) whose face is flush with the shell when released
    and that uses the full 0.25 mm travel when pressed
    - no under-plate flange: a flange collides with the y 16.4-17.2 rib, so the
    hole locates the cap instead
    - trim rib 1 to x >= 41.0 mm to clear the cap travel, and record cap/shell,
    cap/cap and pressed-state checks in the geometry report
    - extend check-e16-board-fit.py to the V5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
    [nfc-card-e16-bottom-v5.stl, nfc-card-e16-enclosure-v5.FCStd, nfc-card-e16-enclosure-v5.step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]
2026-09-22 docs: write down the E16 V5 assembly sequence
    Records the four printed parts, print orientation, the step-by-step stack-up
    (caps, cell, PCB, panel foam, shell bonding) and the dimensions that still need
    a physical sample. It also fixes the panel stack: the 1.5 mm foam behind the
    3.05 mm panel presses it against the top bezel while the tallest part under it
    stops at 3.01 mm.
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2026-09-22 docs: record the E16 battery landing pads and the TS/NTC options
    The battery interface was already designed - my earlier reading only looked at
    nets whose names start with BAT and missed BN.
    - document the three free pads next to U2: BP (BAT_PACK_TBD, d1.5, 49.5/23.55),
    BN (GND, d1.5, 47.7/23.70) and NTC (BAT_NTC_TBD, d1.2, 45.60/23.70), so only
    the cell envelope and lead exit are still open
    - recommend the lead corridor: x 35.6-45.8, y 6.1-11.1 measured free of tracks
    between the two keys, then north to the pads past SW3
    - record the BQ25186 TS option: with no thermistor the firmware must clear TS_EN
    (datasheet 6.3.15.1) or a 10 kOhm dummy has to bridge NTC-BN, otherwise fast
    and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
2026-09-22 feat: evaluate the three-key triangle and prepare enclosure V6
    The user asked for a triangular three-key layout and to fall back to two keys
    only if it does not fit. It fits, with one detail worth correcting.
    - measured against the live snapshot with exact same-layer distances: at
    (38.1, 3.20) / (38.1, 9.50) / (46.3, 6.35) only the new key's lower-left pad
    collides with the existing KEY_PREV_N diagonal (-0.127 mm, a ~0.3 mm reroute);
    SW3's new pads are clear and the GND via at (35.0, 7.40) is same-net
    - the two pad columns end up 0.200 mm apart, not the 1.4 mm in the request, so
    the note recommends x = 46.55 (0.45 mm) while still leaving 8.3 mm of corridor
    - enclosure V6 prepared wi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
    [nfc-card-e16-bottom-v6.stl, nfc-card-e16-enclosure-v6.FCStd, nfc-card-e16-enclosure-v6.step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]
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2026-09-22 feat: build enclosure V7 for the recommended three-key arrangement
    V6 already covers the user's coordinates; this adds the zero-reroute variant so
    both can be inspected before deciding.
    - V7 keeps SW1 (38.1, 3.3) and SW3 (38.1, 15.1) and puts the third key at
    (46.3, 8.8), the arrangement measured with 0 clearance conflicts and no copper
    to move on the board
    - three holes plus three flush caps: single solid per shell, pocket volumes
    unchanged, zero cap/shell, cap/cap and pressed-state interference, ribs
    unchanged
    - point the STL renderer at V7 and label all three holes
    Verified: freecadcmd run reports valid=true with no findings; both V6 (user
    coordinates) and V7 (recommended) repor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
    [nfc-card-e16-bottom-v7.stl, nfc-card-e16-enclosure-v7.FCStd, nfc-card-e16-enclosure-v7.step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]
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2026-09-23 chore: archive old artifacts, publish durable evidence, and repair doc paths
    Layout: projects/nfc-business-card/artifacts/ now keeps only the live outputs
    (manufacture/, review/, studies/routing-space/) at the top level and moves the
    23 phase directories of 2026-09-20/21 into archive/. Directory names are
    purpose-first (the revision lives in the file name) so the next board revision
    does not force a rename again.
    Evidence that tracked documents link to is no longer hidden in the ignored
    tree: the EDA reopen records, netlists and check scripts move to
    hardware/records/, the workflow-validation model to enclosure/, the V2-V7
    render gallery to enclosure/renders/ and the print-mesh report to
    en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
    [pcba-layout-workflow-validation.FCStd]
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
